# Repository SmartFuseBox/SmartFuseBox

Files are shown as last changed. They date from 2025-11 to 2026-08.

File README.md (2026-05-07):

# PowerControlHub  
PowerControlHub is an Arduino-based 12V power distribution and control system for marine and off-grid applications. It provides configurable fused relay switching, multi-protocol sensor telemetry, WiFi/BLE/MQTT connectivity, and a companion touchscreen control panel — all managed through a unified serial command protocol and EEPROM-persisted configuration.

> Current firmware version: **0.9.1.x** — see [`FirmwareVersion.h`](PowerControlHub/FirmwareVersion.h).

---

## Table of Contents

- [Overview](#overview)
- [Prototype PCBs](#prototype-pcbs)
- [Key Features](#key-features)
- [Architecture](#architecture)
- [Board Support](#board-support)
- [Installation](#installation)
- [Configuration](#configuration)
- [Usage](#usage)
- [Subsystem Reference](#subsystem-reference)
- [Limitations and Known Issues](#limitations-and-known-issues)
- [Documentation](#documentation)
- [License](#license)

## Overview

PowerControlHub is a single-unit firmware target running on an Arduino Uno R4 WiFi or ESP32 NodeMCU-32. The Nextion touchscreen display is driven directly by the PCH controller over a dedicated hardware serial port (`Serial2` for GPS; display connected via `NextionControl`).

The firmware entry point is `PowerControlHubApp`, which owns all subsystem instances and wires them together at startup. Host and debug communication uses a text-based framed serial protocol:

```
<CMD>:<key>=<value>;<key>=<value>\n
```

Commands are grouped by prefix (`F`, `C`, `R`, `H`, `W`, `S`, `M`, `N`, `E`, `T`) and are available over serial, USB, and — where applicable — the HTTP REST API. See [Docs/Commands.md](Docs/Commands.md) for the full reference.

---

## Prototype PCBs

<a href="Docs/pcbway.md">Prototype PCBs for PowerControlHub were supported by PCBWay</a>
Prototype PCBs for **PowerControlHub** were supported by [PCBWay](https://www.pcbway.com), enabling rapid iteration from design to real-world testing.

See the [PCB Sponsorship & Manufacturing](Docs/pcbway.md) page for photos, build details, and ongoing testing.

---
## Key Features

### Relay Control
- Up to **8 independently configurable relay channels**, pin-assigned at runtime via configuration.
- **Linked relays** — any relay can be configured to mirror the state of another.
- **Default-on state** — individual relays can be initialised to active at boot.
- **Pulse mode** — relay activates for a configurable duration (seconds) then turns off automatically.
- **Named relays** — short name (5 chars) and long name (20 chars) stored in EEPROM for display use.
- **Action types** — relays can be designated as `Default`, `Horn` (COLREGS sound signal output), or `NightRelay` (automatic day/night switching driven by the LDR sensor).
- **Relay status bitmask** broadcast via `MessageBus` on every state change.

### Sensor Pipeline

All sensors inherit from `BaseSensor` and are registered with `SensorController`. The `RemoteSensor` class provides an extensibility point for sensors on external devices that push readings via serial.

| Sensor | Class | Poll Interval | Notes |
|---|---|---|---|
| **DHT11** | `Dht11SensorHandler` | 2 500 ms | Temperature (°C) and relative humidity (%). Raises `TemperatureSensorFailure` warning on read error; clears automatically on recovery. |
| **Light (LDR)** | `LightSensorHandler` | 30 000 ms | Rolling average over 10 readings. 3-reading debounce before day/night state change. Configurable ADC threshold (default 512). Drives a `NightRelay` automatically. |
| **Water Level** | `WaterSensorHandler` | Configurable | 15-reading rolling average. Active-pin corrosion-reduction control (power applied only during measurement). |
| **GPS** | `GpsSensorHandler` | Continuous | GY-GPS6MV2 (NMEA). Reports latitude, longitude, altitude, speed (km/h), course, cumulative distance. Provides UTC time for automatic RTC synchronisation. Raises `GpsFailure` warning if no valid fix for 30 seconds. |
| **System Diagnostics** | `SystemSensorHandler` | Configurable | Free heap memory, CPU usage percentage, WiFi/BT enabled state, SD log file size (bytes), system uptime (`d HH:MM:SS`), active warning count. |

Sensors expose data over Serial, WiFi REST, BLE, and MQTT. Custom local or remote sensors can be added with minimal boilerplate; see [Docs/Sensors.md](Docs/Sensors.md).

### Connectivity

#### WiFi
- Operates in **Access Point** or **Client** mode, selectable via `C12`.
- Implements **persistent HTTP connections** to reduce TCP handshake overhead on resource-constrained hardware.
- Supports up to **8 concurrent clients** (`MaxConcurrentClients`).
- Automatic reconnection with exponential backoff in Client mode.
- RSSI monitoring — raises `WeakWifiSignal` warning when signal falls below −70 dBm.
- Full REST API across 9 route groups:

| Route | Handler | Purpose |
|---|---|---|
| `/api/relay` | `RelayNetworkHandler` | Relay state read/write |
| `/api/sensor` | `SensorNetworkHandler` | Sensor telemetry |
| `/api/sound` | `SoundNetworkHandler` | COLREGS horn signals |
| `/api/system` | `SystemNetworkHandler` | System status, heartbeat, OTA |
| `/api/config` | `ConfigNetworkHandler` | Configuration read/write |
| `/api/warning` | `WarningNetworkHandler` | Warning bitmask access |
| `/api/timer` | `SchedulerNetworkHandler` | Scheduled event read |
| `/api/externalsensor` | `ExternalSensorNetworkHandler` | Remote sensor config |
| `/` | `WebIndexNetworkHandler` | Index page |

Uses a platform-abstraction interface (`IWifiRadio`) to isolate board-specific WiFi drivers from application logic.

#### Bluetooth BLE
- Available on boards with `BLUETOOTH_SUPPORT` defined.
- Exposes three GATT services via `BluetoothManager`:
  - `BluetoothSystemService` — system diagnostics characteristics.
  - `BluetoothSensorService` — sensor telemetry characteristics with notifications.
  - `BluetoothRelayService` — relay state read and write characteristics.
- Single-client model. Advertising restarts automatically after disconnect.
- No pairing or bonding. Device advertises as **"Power Control Hub"**.
- Uses `IBluetoothRadio` interface — higher-level code operates exclusively through the interface pointer, with runtime null-checks replacing compile-time guards.
- **Arduino Uno R4 WiFi constraint:** WiFi and BLE share the RF path on the ANNA-B112/ESP32-S3 modules; `BLUETOOTH_SUPPORT` and `WIFI_SUPPORT` are mutually exclusive on this board. Enforced by a compile-time `#error`. On ESP32, both can operate simultaneously.

#### MQTT
- Custom **MQTT 3.1.1** client implementation (`MQTTClient`) — no third-party MQTT library dependency.
- **Home Assistant auto-discovery** — all sensors and relays register as HA entities on connect.
- Configurable broker address (64 chars), credentials (32 chars each), device ID, discovery prefix, port (default 1883), and keepalive interval (default 60 s).
- Requires `WIFI_SUPPORT`. Guarded by `#if defined(WIFI_SUPPORT)` in `BoardConfig.h`.

### Warning System

A **32-bit bitmask** tracks up to 32 independent typed conditions within `WarningManager`.

- **Sensor failure aggregation**: any sensor warning (bits 21–31) automatically raises `SensorFailure` (bit 20). `SensorFailure` clears only when all sensor warnings are cleared.
- Warning state changes are broadcast on the `MessageBus` via `WarningChanged`.
- Full warning type reference: [Docs/Warnings.md](Docs/Warnings.md).

### Scheduler

Event-driven relay automation engine with EEPROM-persisted configuration.

- Up to **20 events** (6 on boards with ≤ 1 KB EEPROM) stored in `SchedulerSettings`.
- Each event specifies an independent **trigger**, **condition guard**, and **action**.

| Dimension | Supported Values |
|---|---|
| **Triggers** | `TimeOfDay`, `Sunrise`, `Sunset`, `Interval`, `DayOfWeek`, `Date` |
| **Conditions** | `TimeWindow`, `DayOfWeek`, `IsDark`, `IsDaylight`, `RelayIsOn`, `RelayIsOff` |
| **Actions** | `RelayOn`, `RelayOff`, `RelayToggle`, `RelayPulse`, `AllRelaysOn`, `AllRelaysOff`, `SetPinHigh`, `SetPinLow` |

Sunrise and sunset triggers are computed in real time from GPS coordinates by `SunCalculator`. The `IsDark` / `IsDaylight` conditions fall back to the LDR sensor when GPS is unavailable.

### Message Bus

`MessageBus` provides a **lightweight publish/subscribe event system** for internal component decoupling. No dynamic allocation occurs at publish time — subscriber lists use function-local statics.

Key events: `WarningChanged`, `RelayStatusChanged`, `TemperatureUpdated`, `HumidityUpdated`, `LightSensorUpdated`, `WaterLevelUpdated`, `GpsLocationUpdated`, `GpsAltitudeUpdated`, `GpsSpeedUpdated`, `WifiConnectionStateChanged`, `WifiSignalStrengthChanged`, `SystemMetricsUpdated`. Full reference: [Docs/MessageBus.md](Docs/MessageBus.md).

### Over-the-Air Updates (OTA)

- Available on **ESP32 + `WIFI_SUPPORT` + `OTA_AUTO_UPDATE`** only.
- Polls the GitHub Releases API (`k3ldar/PowerControlHub`) every **24 hours**.
- Downloads asset `PowerControlHub-esp32-v{major}.{minor}.{patch}.{build}.bin` with SHA-256 checksum verification.
- TLS connections use pinned root CA certificates (Sectigo E46 for `api.github.com`; ISRG Root X1 for `assets.githubusercontent.com`).
- **Auto-apply is disabled by default.** Enable via `F12:apply=1` or the `OtaFlagAutoApply` bit in `SystemHeader::reserved[0]`.
- OTA state (`idle`, `checking`, `available`, `downloading`, `rebooting`, `failed`, `uptodate`) is queryable at any time via `F13`.

### Diagnostics and Logging

- **SD card logging** via `SdCardLogger` / `MicroSdDriver`. Configurable SPI pins (`C4`). Raises `SpiPinConfigError`, `SdCardMissing`, `SdCardError`, or `SdCardLowSpace` warnings as appropriate.
- Optional **SD card config loader** (`CARD_CONFIG_LOADER`) — reads `config.txt` at boot to override EEPROM settings without reflashing.
- **DS1302 RTC** (`RtcDS1302Driver`) with configurable pins (`C18`). Automatically synchronised from GPS UTC time on each valid GPS fix.
- **CPU usage monitoring** via `SystemCpuMonitor`. Available over serial, WiFi, and MQTT.
- **Boot counter** and **crash counter** tracked in `SystemHeader` with magic number validation (`0x53464201`).
- **RGB LED warning indicator** (HW479) driven on configurable pins (`C8`).
- **PinGuard** — compile-time GPIO validation layer that rejects flash-reserved, input-only, and strapping pins at the point of assignment, returning `ACK:<cmd>=Invalid pin` before the value reaches EEPROM. Board-specific tables are selected automatically from the IDF toolchain macros — no manual configuration required. See [Docs/PinGuard.md](Docs/PinGuard.md).
- **Crash loop guard** — `crashCounter` in `SystemHeader` is incremented at the start of every boot and only reset after full initialisation succeeds. If the counter reaches `CrashCounterThreshold` (default 3), the firmware resets the config to safe defaults before any hardware initialisation runs, breaking a watchdog reset loop caused by invalid pin configuration.

### Nextion Display

- `NavigationController` manages an ordered list of active pages, rebuilt dynamically when the location type changes — no reboot required.
- Maritime-specific pages (buoys, cardinal markers, flags, VHF radio, COLREGS sound signals) are included in the page list only when `LocationType` is `Power`, `Sail`, `Fishing`, or `Yacht`.
- Pages included: Splash, Home, Relay, Relay Settings, Environment, System, Warning, Settings, About, Buoys, Cardinal Markers, Flags, Moon Phase, Sound (Fog / Maneuvering / Overtaking / Emergency / Other / Signals), VHF (Channels / Distress / Radio).

### Security

- **API key and HMAC key** fields (32 chars each) are reserved in the `Config` struct for future HTTP authentication.

---

## Architecture

### Repository Structure

```
PowerControlHub/    Firmware source (relays, sensors, WiFi, BLE, MQTT, OTA, SD, Nextion display)
Docs/            Reference documentation
TestData/        Serial command test scripts
```

### Subsystem Dependency Graph

```
PowerControlHubApp
├── MessageBus                  Pub/sub event bus (no dynamic allocation)
├── RelayController             Relay switching, linking, pulse, action types
├── SoundController             COLREGS signal sequencer -> horn relay
├── SensorController            Sensor pipeline (local + remote)
│   ├── Dht11SensorHandler
│   ├── LightSensorHandler
│   ├── WaterSensorHandler
│   ├── GpsSensorHandler
│   ├── SystemSensorHandler
│   └── RemoteSensor (xN)
├── ConfigController            EEPROM config lifecycle
├── WarningManager              32-bit bitmask, sensor failure aggregation
├── ScheduleController          Event engine: trigger -> condition -> action
├── WifiController              WiFi lifecycle, HTTP REST API
│   └── WifiServer              Connection state machine, request routing
├── BluetoothController         BLE lifecycle (BLUETOOTH_SUPPORT)
│   └── BluetoothManager
│       ├── BluetoothSystemService
│       ├── BluetoothSensorService
│       └── BluetoothRelayService
├── MQTTController              MQTT 3.1.1 client, HA auto-discovery (MQTT_SUPPORT)
├── SdCardLogger                SD card log writer (SD_CARD_SUPPORT)
├── RtcDS1302Driver             DS1302 real-time clock
├── OtaManager                  GitHub OTA (OTA_AUTO_UPDATE + ESP32 + WIFI_SUPPORT)
├── BroadcastManager            Centralised serial broadcast to computer/debug port
├── NavigationController        Nextion page navigation (NEXTION_DISPLAY_DEVICE)
└── SerialCommandManager        Framed serial command dispatch (USB/debug)
```

### Interface Abstraction Pattern

WiFi and Bluetooth subsystems are each accessed through a platform-agnostic interface (`IWifiRadio`, `IBluetoothRadio`). Board-specific drivers (`R4WifiRadio`, `Esp32WifiRadio`, `BluetoothController`) are constructed only inside `PowerControlHubApp` under the appropriate `#if defined(...)` guard. All higher-level code operates through interface pointers with runtime null-checks, minimising preprocessor usage and enabling straightforward test doubles.

### Configuration Persistence

The `Config` struct is a versioned, packed POD serialised to EEPROM. The current layout version is **6** (`ConfigVersion6`). The `SystemHeader` (32 bytes) precedes the config payload and contains a magic number (`0x53464201`), boot count, crash counter, reset reason, OTA flags, and a 16-bit checksum. A config version mismatch triggers migration logic in `ConfigManager` and raises `DefaultConfigurationFuseBox`.

---

## Board Support

| Board | WiFi | BLE | MQTT | OTA | Notes |
|---|---|---|---|---|---|
| **Arduino Uno R4 WiFi** | Yes | Yes | Yes | No | WiFi and BLE are mutually exclusive (shared RF path) |
| **Arduino Uno R4 Minima** | No | No | No | No | Serial and sensor support only |
| **ESP32 NodeMCU-32** | Yes | Yes | Yes | Yes | Full feature support; WiFi and BLE simultaneous |

Board selection is controlled by a single `#define` in `Local.h` using the trailing-underscore convention. `BoardConfig.h` derives all capability flags, EEPROM limits, and enforces incompatible feature combinations at compile time.

---

## Installation

### Prerequisites

| Requirement | Details |
|---|---|
| **Arduino IDE** | 1.8.19 or Arduino IDE 2.x |
| **Git for Windows** | Standard installation |
| **Windows 10 / 11** | No special configuration required |

### Required Libraries (Arduino Library Manager)

| Library | Source |
|---|---|
| `SerialCommandManager` | Si Carter |
| `DHT sensor library` | Adafruit |
| `QMC5883LCompass` | Arduino Library Manager |
| `NextionControl` | Custom — copy `NextionControl/` folder to Arduino `libraries/` directory |

### Steps

1. Clone the repository:

   ```
   git clone https://github.com/k3ldar/PowerControlHub
   ```

2. Install all required libraries via the Arduino IDE Library Manager, and copy `NextionControl` manually.

3. Open `k3ldar/PowerControlHub.ino` in the Arduino IDE.

4. Edit `Local.h` to activate the correct board and feature flags (see [Configuration](#configuration)).

5. Select the target board and COM port, then upload.

Full setup walkthrough: [Docs/SETUP.md](Docs/SETUP.md).

---

## Configuration

All hardware-specific configuration is isolated in a single file: `PowerControlHub/Local.h`. No other file requires modification for a standard hardware setup.

### Board Selection

Exactly one board define must be active. Remove the trailing underscore to activate:

```cpp
#define ARDUINO_UNO_R4       // Arduino Uno R4 WiFi
#define ARDUINO_R4_MINIMA_   // Arduino Uno R4 Minima (inactive)
#define ESP32_NODE_32_       // ESP32 NodeMCU-32 (inactive)
```

### Feature Flags

| Define | Default | Approx. Flash | Description |
|---|---|---|---|
| `FUSE_BOX_CONTROLLER` | Active | — | Enables the full SFB subsystem stack |
| `WIFI_SUPPORT` | Active | — | WiFi controller and HTTP REST API |
| `MQTT_SUPPORT` | Active | ~40 KB | MQTT client and HA auto-discovery (requires `WIFI_SUPPORT`) |
| `BLUETOOTH_SUPPORT` | Inactive | ~144 KB | BLE services (mutually exclusive with WiFi on Uno R4) |
| `SD_CARD_SUPPORT` | Active | ~32 KB | SD card logger and SPI driver |
| `NEXTION_DISPLAY_DEVICE` | Active | ~52 KB | Nextion display page system |
| `OTA_AUTO_UPDATE` | Active | ~165 KB | GitHub OTA (ESP32 + WiFi only) |
| `LED_MANAGER` | Inactive | — | Arduino R4 WiFi LED matrix (experimental) |
| `CARD_CONFIG_LOADER` | Inactive | — | Load config overrides from SD `config.txt` at boot |

### Relay Count

```cpp
constexpr uint8_t ConfigRelayCount = 8;  // number of relay channels
```

Pins are assigned at runtime via the `R11` serial command and persisted to EEPROM. `0xFF` marks a pin as unassigned.

Full configuration reference: [Docs/Local.md](Docs/Local.md).

---

## Usage

### Serial / USB Commands (Quick Reference)

Commands follow the frame format: `<CMD>:<key>=<value>;<key>=<value>\n`

```
# Save config to EEPROM
C0

# Enable WiFi in client mode, set SSID and password
C11:v=1
C12:v=1
C13:YourSSID
C14:YourPassword
C0

# Switch relay 0 on / off
R3:i=0;v=1
R3:i=0;v=0

# Query all relay states
R2

# Read temperature and humidity
S0
S1

# Enable MQTT and set broker
M0:v=1
M1:192.168.1.100
C0

# Enable Home Assistant auto-discovery
M6:v=1

# Query OTA status (ESP32 only)
F13

# Check for firmware update
F12

# Apply firmware update immediately
F12:apply=1
```

Full command reference (all groups, all parameters): [Docs/Commands.md](Docs/Commands.md).

### HTTP REST API (WiFi)

```
# Relay control
POST /api/relay/R3?i=0&v=1

# Sensor data
GET /api/sensor/S0

# System status
GET /api/system/F2

# OTA status
GET /api/system/F13
```

---

## Subsystem Reference

| Document | Contents |
|---|---|
| [Docs/Commands.md](Docs/Commands.md) | Full serial and REST command reference (all groups F, C, R, H, W, S, M, N, E, T) |
| [Docs/Local.md](Docs/Local.md) | `Local.h` configuration reference: board selection, feature flags, pin layout |
| [Docs/PinGuard.md](Docs/PinGuard.md) | GPIO validation: board pin tables, blocked pin tiers, crash loop guard |
| [Docs/Sensors.md](Docs/Sensors.md) | Sensor classes, poll intervals, MQTT channels, warning behaviour, extensibility guide |
| [Docs/Warnings.md](Docs/Warnings.md) | 32-bit warning type reference, `WarningManager` API, propagation model |
| [Docs/Wifi.md](Docs/Wifi.md) | WiFi architecture: connection state machine, persistent connection model, handler pattern |
| [Docs/BluetoothBle.md](Docs/BluetoothBle.md) | BLE service/characteristic reference, connection model, adding new services |
| [Docs/ScheduleEvents.md](Docs/ScheduleEvents.md) | Scheduler data structures, trigger/condition/action types, EEPROM layout |
| [Docs/MessageBus.md](Docs/MessageBus.md) | Event reference, publish/subscribe API |
| [Docs/SETUP.md](Docs/SETUP.md) | Prerequisites, library installation, build instructions |
| [Docs/BOM.md](Docs/BOM.md) | Bill of materials: hardware, fasteners, connectors, 3D-printed parts |

---

## Limitations and Known Issues

- **Arduino Uno R4 WiFi**: WiFi and BLE cannot operate simultaneously due to the shared RF hardware path. This is enforced at compile time.
- **Arduino Uno R4 Minima**: No radio support. Serial, sensors, and Nextion display only.
- **OTA updates**: Restricted to ESP32 targets with WiFi in client mode and `OTA_AUTO_UPDATE` defined. Not available on Arduino Uno R4.
- **Scheduler capacity**: Limited to 6 events on boards with 1 KB or less of EEPROM.
- **LED matrix manager** (`LED_MANAGER`): Experimental on Arduino R4 WiFi; not recommended for production use.
- **SD card support**: Marked experimental in `Local.h`. SPI pin configuration must be correct or `SpiPinConfigError` is raised.
- **Single BLE client**: Only one BLE central can be connected at a time. No pairing or bonding is implemented.

---

## Documentation

| Getting Started | Configuration | Connectivity |
|:---|:---|:---|
| [Setup Guide](Docs/SETUP.md) | [Local.h Reference](Docs/Local.md) | [WiFi Architecture](Docs/Wifi.md) |
| [Bill of Materials](Docs/BOM.md) | [Scheduled Events](Docs/ScheduleEvents.md) | [Bluetooth BLE](Docs/BluetoothBle.md) |
| [Sensor Reference](Docs/Sensors.md) | [Warning System](Docs/Warnings.md) | [Message Bus](Docs/MessageBus.md) |
| [Command Reference](Docs/Commands.md) | [PinGuard & Crash Loop](Docs/PinGuard.md) | |

---

## License

PowerControlHub is released under the **GNU General Public License v3.0**.  
See [LICENSE](LICENSE) for the full licence text.

Copyright &copy; 2025 Simon Carter (`s1cart3r@gmail.com`)

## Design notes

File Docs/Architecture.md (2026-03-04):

# SmartFuseBox – Architecture Overview

## 1. Project Purpose

SmartFuseBox is a modular, Arduino-powered **12V power distribution and control system** designed for marine and off-grid applications. It provides fused relay switching, onboard sensor monitoring, wireless connectivity (WiFi/BLE/MQTT), and a serial command interface to an external control panel.

---

## 2. Physical Units

The system spans two physical hardware units that communicate over a serial link.

| Unit | Hardware | Role |
|---|---|---|
| **Smart Fuse Box (SFB)** | Arduino Uno R4 (or ESP32) | Relay control, sensor handling, WiFi, BLE, MQTT, SD logging |
| **Boat Control Panel (BCP)** | Arduino Mega + Nextion display | User interface, immobiliser logic, time sync, config management |

The two units communicate via a 7-wire harness (12V in/out, GND, 5V, TX, RX, spare). The control panel must return a valid 12V feed to enable the fuse box, acting as a basic immobiliser.

---

## 3. High-Level Component Map

```
┌───────────────────────────────────────────────────────────────────┐
│                        SmartFuseBoxApp                            │
│                                                                   │
│  ┌───────────────┐  ┌────────────────┐  ┌──────────────────────┐  │
│  │ Serial Link   │  │  Message Bus   │  │   Warning Manager    │  │
│  │ (BroadcastMgr)│  │  (pub/sub)     │  │   (32-bit bitmap)    │  │
│  └───────────────┘  └────────────────┘  └──────────────────────┘  │
│                                                                   │
│  ┌────────────────────────────────────────────────────────────┐   │
│  │                    Command Handlers (Serial)               │   │
│  │  SystemCmdHandler  RelayCmdHandler  SoundCmdHandler        │   │
│  │  SensorCmdHandler  ConfigCmdHandler  AckCmdHandler         │   │
│  └────────────────────────────────────────────────────────────┘   │
│                                                                   │
│  ┌──────────────┐  ┌──────────────┐  ┌────────────────────────┐   │
│  │   Relay      │  │   Sensor     │  │   Config System        │   │
│  │   Controller │  │   Manager    │  │   (EEPROM + SD)        │   │
│  └──────────────┘  └──────────────┘  └────────────────────────┘   │
│                                                                   │
│  ┌──────────────┐  ┌──────────────┐  ┌────────────────────────┐   │
│  │   WiFi       │  │  Bluetooth   │  │   MQTT                 │   │
│  │   Controller │  │  Controller  │  │   Controller           │   │
│  │   + HTTP API │  │  (BLE)       │  │   (Home Assistant)     │   │
│  └──────────────┘  └──────────────┘  └────────────────────────┘   │
│                                                                   │
│  ┌──────────────┐  ┌──────────────┐  ┌────────────────────────┐   │
│  │  SD Card     │  │  LED Matrix  │  │  Date/Time Manager     │   │
│  │  Logger      │  │  Manager     │  │  (RTC + millis())      │   │
│  └──────────────┘  └──────────────┘  └────────────────────────┘   │
└───────────────────────────────────────────────────────────────────┘
```

---

## 4. Entry Point and Application Lifecycle

### `SmartFuseBox.ino`
The sketch file wires everything together. It owns the two `SerialCommandManager` instances (selecting which hardware serial ports and baud rates to use) and constructs `SmartFuseBoxApp`. Project-specific sensors are constructed using accessors from the app object.

```
setup()  →  initializeSerial  →  app.setup(sensors, remoteSensors)
loop()   →  app.loop()
```

### `SmartFuseBoxApp`
Central application class that owns all subsystems. On `setup()` it:
1. Initialises the `SensorManager` with all local and remote sensor handlers.
2. Configures WiFi and Bluetooth from the stored `Config`.
3. Registers all command handlers with each `SerialCommandManager`.
4. Registers all network handlers with the `WifiController`.
5. Registers all MQTT handlers (if `MQTT_SUPPORT` is defined).
6. Starts an LED startup animation (if `LED_MANAGER` is defined).

On `loop()` it delegates to each subsystem in turn.

---

## 5. Serial Communication Layer

All serial communication uses the `SerialCommandManager` library. Commands are newline-terminated with the following format:

```
{COMMAND}:{key=value};{key=value}\n
```

Two serial connections are maintained:

| Port | Baud | Purpose |
|---|---|---|
| `Serial` (COMPUTER_SERIAL) | 115200 | USB debug / computer connection |
| `Serial1` (LINK_SERIAL) | 19200 | Link to Boat Control Panel |

### `BroadcastManager`
Wraps both serial managers and provides a single `sendCommand()` / `sendDebug()` / `sendError()` interface that can target both ports simultaneously or link-only.

### Command Handlers
Each handler inherits `SharedBaseCommandHandler` and declares the command tokens it owns.

| Handler | Command Prefix | Responsibility |
|---|---|---|
| `SystemCommandHandler` | `F0`–`F11` | Heartbeat, memory/CPU diagnostics, date/time, SD status, uptime |
| `RelayCommandHandler` | `R0`–`R4` | Turn relays on/off, retrieve relay states |
| `SoundCommandHandler` | `H0`–`H12` | COLREGS sound signal playback |
| `SensorCommandHandler` | `S*` | Sensor data reporting and querying |
| `ConfigCommandHandler` | `C0`–`C31` | Full configuration management |
| `AckCommandHandler` | `ACK` | Processes acknowledgement responses |
| `WarningCommandHandler` | `W*` | Warning state propagation |
| `InterceptDebugHandler` | – | Debug message interception |

---

## 6. Relay Subsystem

### `RelayController`
Manages up to 8 relay outputs. Relay pins are LOW-active (ON = LOW, OFF = HIGH).

Key behaviours:
- **Linked relays**: configured pairs that mirror each other's state.
- **Reserved relay**: one relay index can be reserved for the sound (horn) system and is excluded from bulk on/off commands.
- **State change notifications**: publishes a `RelayStatusChanged` bitmask event on the `MessageBus` when any relay changes state.

---

## 7. Sensor Subsystem

### Base Classes

| Class | Role |
|---|---|
| `BaseSensor` | Extends `BaseSensorHandler` (external `SensorManager` library); optionally extends `JsonVisitor` for status serialisation |
| `RemoteSensor` | Receives updates from the serial link or MQTT; stores up to 5 key/value parameters |

All sensors declare a `SensorIdList` ID, a command ID string, and (when `MQTT_SUPPORT` is defined) expose named MQTT channels with device class, unit, and binary/numeric type metadata.

### Included Sensor Handlers

| Sensor | Type | Measurements |
|---|---|---|
| `WaterSensorHandler` | Local (analog) | Raw water level + rolling average queue |
| `Dht11SensorHandler` | Local (digital) | Temperature (°C) + Humidity (%) |
| `LightSensorHandler` | Local (digital + analog) | Day/night state |
| `SystemSensorHandler` | Local (virtual) | Free RAM, CPU usage, BT/WiFi state, SD log file size, active warning count |
| `RemoteSensor` (GPS) | Remote | Latitude, Longitude (extensible to Altitude, Speed, Course) |

### `SensorManager` (external library)
Calls `update()` on each registered sensor at its own requested interval (returned in milliseconds from `update()`). This keeps all sensor polling non-blocking.

### `SensorController`
Provides indexed access to all `BaseSensor` instances for the MQTT and network layers.

---

## 8. Connectivity

### 8.1 WiFi (`WifiController` + `WifiServer`)

Available on boards that define `WIFI_SUPPORT` (e.g. Arduino Uno R4, ESP32).

- Operates in **AP mode** (device creates its own network) or **Client mode** (joins existing network).
- `WifiServer` runs an HTTP server supporting up to 2 concurrent clients.
- REST API routes are registered via `INetworkCommandHandler` implementations:

| Network Handler | Route | Exposes |
|---|---|---|
| `SystemNetworkHandler` | `/api/system/{cmd}` | System commands (F0-only via WiFi) |
| `RelayNetworkHandler` | `/api/relay/{cmd}` | Relay state and control |
| `SoundNetworkHandler` | `/api/sound/{cmd}` | Sound signal commands |
| `ConfigNetworkHandler` | `/api/config/{cmd}` | Configuration read/write |
| `SensorNetworkHandler` | `/api/sensor/{cmd}` | Sensor data |
| `WarningNetworkHandler` | `/api/warning/{cmd}` | Warning state |

### 8.2 Bluetooth BLE (`BluetoothController` + `BluetoothManager`)

Available on boards that define `ARDUINO_UNO_R4`. Uses the `ArduinoBLE` library.

`BluetoothManager` coordinates the BLE stack and delegates domain logic to services:

| BLE Service | Exposes |
|---|---|
| `BluetoothSystemService` | Heartbeat, system initialised, free memory, CPU usage (notify characteristics) |
| `BluetoothRelayService` | Relay state array (read/notify) + relay set command (write) |
| `BluetoothSensorService` | Sensor data streaming |

### 8.3 MQTT (`MQTTController` + `MQTTClient`)

Available when both `WIFI_SUPPORT` and `MQTT_SUPPORT` are defined.

- `MQTTClient` is a pure C++ MQTT 3.1.1 implementation over `WiFiClient` (no external MQTT library dependency).
- `MQTTController` manages connection lifecycle: retry with exponential back-off, reconnect count, uptime tracking.
- Supports Home Assistant auto-discovery (`useHomeAssistantDiscovery` config flag).

| MQTT Handler | Responsibility |
|---|---|
| `MQTTSensorHandler` | Publishes all sensor channel states; handles HA discovery payloads |
| `MQTTRelayHandler` | Publishes relay states; subscribes to relay command topics |
| `MQTTSystemHandler` | Publishes system metrics |
| `MQTTConfigCommandHandler` | Handles configuration updates via MQTT |

---

## 9. Configuration System

| Component | Role |
|---|---|
| `Config` struct | Packed POD stored in EEPROM; versioned with checksum validation |
| `ConfigManager` | Static EEPROM read/write; `resetToDefaults()`; checksum calculation |
| `ConfigController` | Domain façade exposing typed setters (e.g. `setWifiSsid`, `setLedColor`) |
| `ConfigSyncManager` | Periodically requests a C1 (Get Settings) from the Control Panel every 5 minutes; retries every 10 seconds on failure |
| `SDCardConfigLoader` | Optional: loads `config.txt` from SD card on boot or card insertion |

Notable configuration fields include vessel name, relay names (short 5-char + long 20-char), home page button mapping, vessel type (Motor/Sail/Fishing/Yacht), MMSI, call sign, home port, timezone offset, LED colours/brightness, WiFi credentials, MQTT credentials, relay default states, and linked relay pairs.

---

## 10. Event System – `MessageBus`

`MessageBus` is a compile-time typed publish/subscribe bus. Components subscribe to strongly-typed event structs; publishers call `messageBus->publish<EventType>(args)`.

Key events:

| Event | Payload | Published by |
|---|---|---|
| `TemperatureUpdated` | `float newTemp` | `Dht11SensorHandler` |
| `HumidityUpdated` | `uint8_t newHumidity` | `Dht11SensorHandler` |
| `LightSensorUpdated` | `bool isDayTime` | `LightSensorHandler` |
| `WaterLevelUpdated` | `uint16_t level, uint16_t avg` | `WaterSensorHandler` |
| `RelayStatusChanged` | `uint8_t changedMask` | `RelayController` |
| `WifiConnectionStateChanged` | `WifiConnectionState` | `WifiServer` |
| `WifiSignalStrengthChanged` | `uint16_t strength` | `WifiServer` |
| `GpsLocationUpdated` | `double lat, double lon` | `RemoteSensor` |
| `SystemMetricsUpdated` | – | `SystemSensorHandler` |
| `MqttConnected` / `MqttDisconnected` | – | `MQTTController` |
| `MqttMessageReceived` | `topic, payload` | `MQTTController` |
| `WarningChanged` | `uint32_t mask` | `WarningManager` |

---

## 11. Warning System – `WarningManager`

Tracks up to 32 simultaneous warnings using a `uint32_t` bitmask, split into local (raised on this device) and remote (received from the Control Panel).

| Bit Range | Category |
|---|---|
| 0–19 | System warnings (connection lost, WiFi/BT init failed, SD card issues, low battery, etc.) |
| 20–31 | Sensor warnings (temperature sensor failure, GPS failure, compass failure, etc.) |

Built-in heartbeat monitoring automatically raises/clears the `ConnectionLost` warning based on `F0` ACK timing (timeout: 3 seconds).

---

## 12. Sound System – `SoundController`

Non-blocking COLREGS-compliant sound signal playback via a relay-controlled horn. Uses a state machine (`Idle → StartDelay → BlastOn → BlastGap → WaitingRepeat`).

Supported signal types:

| Signal | COLREGS Reference |
|---|---|
| SOS | Distress (Morse) |
| Fog | Rule 35 (repeats every 2 minutes) |
| MoveStarboard / MovePort / MoveAstern / MoveDanger | Rule 34 manoeuvring signals |
| OvertakeStarboard / OvertakePort / OvertakeConsent / OvertakeDanger | Rule 34 overtaking signals |
| Test | Non-COLREGS test blast |

---

## 13. SD Card and Logging

| Component | Role |
|---|---|
| `MicroSdDriver` | Singleton resource manager for the SD card (SdFat library); handles card presence detection, settling delays, and up to 3 simultaneous file handles |
| `SdCardLogger` | Non-blocking sensor data logger; buffers up to 64 records in a circular buffer; writes a maximum of 5 records per loop iteration; creates date-named CSV files (`YYYYMMDD.csv`) with automatic midnight rotation |

`SdCardLogger` subscribes to `MessageBus` sensor events and captures a `SensorSnapshot` (temperature, humidity, water level, GPS, warnings, etc.) on each update.

---

## 14. LED Matrix – `LedMatrixManager`

Used on Arduino Uno R4 boards with `LED_MANAGER` defined. Drives the 8×12 built-in LED matrix.

Matrix layout (conceptual):

```
Row 0     : Top border / relay states
Col 0     : Left border / system indicator
Cols 3–4  : Temperature display (rows 2–7)
Cols 10–11: Warning / GPS indicators (rows 4–7)
```

Reacts to `MessageBus` events to update:
- Relay on/off states (top row)
- WiFi connection state and RSSI signal bars
- Temperature and humidity readings
- Warning indicators (GPS, system, warnings)

Supports startup and shutdown animation sequences.

---

## 15. Date/Time – `DateTimeManager`

Static class providing system-wide time management.

- Tracks Unix timestamp (seconds) plus a millisecond offset derived from `millis()`.
- On boot, attempts to read time from a DS1302 hardware RTC (Control Panel builds only).
- Time is continuously synchronised via the `t=` parameter in the `F0` heartbeat command from the Control Panel — no separate `F6` command is needed during normal operation.
- Exposes `setDateTimeISO()` and `setDateTime(unixTimestamp)`.

---

## 16. Feature Flags (`Local.h`)

All major features are controlled by compile-time defines in `Local.h` (consumer-editable):

| Define | Effect |
|---|---|
| `ARDUINO_UNO_R4` | Enables WiFi and Bluetooth support |
| `FUSE_BOX_CONTROLLER` | Includes relay/sensor controller code; omit to use components standalone |
| `WIFI_SUPPORT` | Includes `WifiController`, `WifiServer`, and network command handlers |
| `MQTT_SUPPORT` | Includes `MQTTController`, `MQTTClient`, and all MQTT handlers (requires `WIFI_SUPPORT`) |
| `LED_MANAGER` | Includes `LedMatrixManager` (requires `ARDUINO_UNO_R4`) |
| `CARD_CONFIG_LOADER` | Includes `SDCardConfigLoader` for SD-based config loading |

---

## 17. Key Design Patterns

| Pattern | Where Used |
|---|---|
| **Facade / Owned-component** | `SmartFuseBoxApp` owns all subsystems and exposes accessor methods to the sketch |
| **Publish / Subscribe** | `MessageBus` decouples producers (sensors, relay, WiFi) from consumers (LED matrix, MQTT, logger) |
| **Command Handler** | Serial, HTTP, and MQTT commands each routed through dedicated handler classes |
| **Strategy / Visitor** | `JsonVisitor` / `NetworkJsonVisitor` decouple JSON serialisation from domain objects |
| **Sensor Polling Abstraction** | External `SensorManager` library calls `update()` on each sensor at its own interval, avoiding `delay()` |
| **Mixin Logging** | `LoggingSupport`, `SingleLoggerSupport`, `BroadcastLoggerSupport` add logging to any class via multiple inheritance |
| **Compile-time Feature Selection** | `#define` flags in `Local.h` prevent unused subsystems from consuming flash/RAM on resource-constrained boards |

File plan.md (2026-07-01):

Move SensorMetaCache refresh to happen immediately when the DashboardPoller starts executing (after connection), rather than deferred until the first successful poll response.

Changes to `PowerControlHubApp\Services\DashboardPoller.cs`:
1. Remove the `_wasPreviouslyConnected` flag and the fire-and-forget `_metaCache.RefreshAsync` call inside the poll loop.
2. In `ExecuteAsync`, before entering the `while` loop, call `_metaCache.RefreshAsync(_service, stoppingToken)` synchronously (await) once. This ensures metadata is available before any sensor detail pages can be navigated to.
3. This makes the meta cache refresh happen once per connection, shortly after the poller starts, aligned with the device being reachable.

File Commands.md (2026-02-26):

# Communication Commands
The following sections indicate the types of commands that can be sent to the Boat Control Panel, with examples and purpose.

## System Commands
These are commands used to configure the system settings and can only be sent from a computer, they are not used for internal communication.

| Command | Example | Purpose |
|---|---|---|
| `F0` — Heart beat | `F0:w=0x00` (SFB) or `F0:w=0x00;t=1733328600` (BCP) | Send at rated intervals to monitor connection health. If no ACK received, indicates connection loss. **Params:** `w=<hex_warnings>` - bitmask of active local warnings (hex format). `t=<timestamp>` - (BCP only) Unix timestamp for continuous time sync. Smart Fuse Box automatically updates clock from `t=` parameter. |
| `F1` — System Initialized | `F1` | Sent by the system when initialization is complete to signal readiness. No params. Used to notify connected devices or software that the control panel is ready for operation. |
| `F2` — Free Memory | `F2` | When received will return the amount of free memory. |
| `F3` — Cpu Usage | `F3` | When received will return the current CPU usage. No params. |
| `F4` — Bluetooth Enabled | `F4` | When received will return the current enabled state of bluetooth 0 off 1 on. No params. |
| `F5` — Wifi Enabled | `F5` | When received will return the current enabled state of wifi 0 off 1 on. No params. |
| `F6` — Set DateTime | `F6:v=1733328600` | Set current date/time. Accepts Unix timestamp (seconds since epoch). Returns current stored time. |
| `F7` — Get DateTime | `F7` | Get current date/time as ISO 8601 datetime string `YYYY-MM-DDTHH:MM:SS`. |
| `F8` — SD Card Present | `F8` | Query if SD card is present. Returns `v=0` (not present) or `v=1` (present). No params. |
| `F9` — SD Card Log File Size | `F9` | Get current log file size in bytes. Returns `v=<bytes>` where bytes is the size of the active log file. Returns `v=0` if no file is open. No params. |
| `F10` — RTC Diagnostic | `F10` | Perform DS1302 RTC diagnostics. Returns status message with RTC health (availability, running state, write protection, time validity). Returns error message if RTC fails any check. No params. |
| `F11` — Uptime | F11 | Returns system uptime as "days HH:MM:SS" (e.g. 2d 03:12:45). No params. |

**Heartbeat Behavior:**
- Sent every 1 second (1000ms) from both devices
- Boat Control Panel (BCP) includes time sync: `F0:w=0x00;t=1733328600`
- Smart Fuse Box (SFB) includes only warnings: `F0:w=0x00`
- Connection timeout occurs after 3 seconds without response
- Time synchronization is automatic - no separate F6 commands needed during normal operation
- F6 command can still be used for manual time updates or initial configuration
- 
### Wifi System Commands (SFB)
Only F0 is supported via wifi.
Route: /api/system/{command}
Example: Return free memory = /api/system/F2 

------

## Configuration Commands
These are commands used to configure the system settings and can only be sent from a computer, they are not used for internal communication.

| Command | Example | Purpose |
|---|---|---|
| `C0` — Save settings | `C0` | Persist current in-memory config to EEPROM. Responds `SAVED` on success; error `EEPROM commit failed` on failure. No params. |
| `C1` — Get settings | `C1` | Request full config. Device replies with multiple commands: `C3 <boatName>`, `C4 <idx>:<shortName|longName>` for each relay, `C5 <slot>:<relay>` for each home-slot mapping, `C6 <idx>=<color>` for each button color, `C7 v=<type>` for vessel type, `C8 v=<relay>` for sound relay, `C9 v=<delay>` for sound delay, `C10`-`C17` for WiFi/Bluetooth settings (Arduino Uno R4 only), `C18 <relay>=<state>` for default relay states, `C19 <relay>=<linkedrelay>` for linked relays, `C20 v=<offset>` for timezone, `C21 <mmsi>` for MMSI, `C22 <callsign>` for call sign, `C23 <homeport>` for home port, then `OK`. No params. |
| `C2` — Reset settings | `C2` | Request full reset of all config settings. No params. |
| `C3` — Rename boat (BCP) | `C3:Sea Wolf` or `C3:name=SeaWolf` | Set the boat name. `<key>:<value>` pair (value is used as boat name. Empty name → error. Name is truncated to configured max length. |
| `C4` — Rename relay (BCP) | `C4:2=Bilge` or `C4:2=Bilge\|Bilge Pump` | Rename a relay. Param format: `<idx>=<shortName>` or `<idx>=<shortName|longName>`. `idx` must be 0..7 (`RELAY_COUNT`). If no pipe character or long name provided, the short name is used for both. Short name is truncated to 5 chars (used on home page), long name is truncated to 20 chars (used on buttons page). Missing name → error. |
| `C5` — Map home button (BCP) | `C5:1=3` (map) — `C5:1=255` (unmap) | Map a home-page slot to a relay. Param format: `<slot>:<relay>`. `button` must be 0..3 (`HOME_BUTTONS`). `relay` must be 0..7 or `255` to clear/unmap. |
| `C6` — Map home button color (BCP) | `C6:0=4` (map button 1 to Red when activated) — `C6:1=255` (unmap colors) | Map a home-page button to a color when activated (on). Param format: `<slot>:<relay>`. `slot` must be 0..3 (`ConfigManager::HOME_SLOTS`). `relay` must be 0..7 or `255` to clear/unmap. |
| `C7` — Set vessel type | `C7:v=1` | Set the vessel type. Param format: `v=<type>`. Possible values for `<type>` are: 0 (Motor), 1 (Sail), 2 (Fishing), 3 (Yacht). Uses enum values as defined in `Config.h`. Invalid or missing value → error. |
| `C8` — Sound relay button | `C8:v=3` (map) — `C8:v=255` (unmap) | Map the sound system (horn) to a relay. Param format: `v=<relay>`. `relay` must be 0..7 or `255` to clear/unmap. Auto-renames relay to "Sound" / "Sound\r\nSignals" if not already named. |
| `C9` — Sound delay Start | `C9:v=0xFF` | Sets the delay before the sound is started in milliseconds, allows other processing to continue so as sounds are not cut off. Invalid or missing value → error. |
| `C10` — Bluetooth Enabled (SFB) | `C10:v=1` | Sets the enabled state of bluetooth, 0 disabled, 1 enabled, if disabling then a restart is required. Invalid or missing value → error. |
| `C11` — Wifi Enabled (SFB) | `C11:v=1` | Sets the enabled state of wifi, 0 disabled, 1 enabled, if disabling then a restart is required. Invalid or missing value → error. |
| `C12` — Wifi Access Mode (SFB) | `C12:v=1` | Sets access mode, 0 is AP and 1 is client |
| `C13` — Wifi SSID (SFB) | `C13:RouterName` | Set's the wifi SSID, only available if access mode is client. Param format: SSID value directly (no v= prefix). |
| `C14` — Wifi Password (SFB) | `C14:Password123` | Set's the wifi password, only available if access mode is client. Param format: password value directly (no v= prefix). |
| `C15` — Wifi Port (SFB) | `C15:v=80` | Set's the wifi port, this is the port used to listen on, default value is 80. Invalid or zero port → error. |
| `C16` — Wifi connection state (SFB) | `C16` | Wifi connection state, no params, returns WifiConnectionState value. Note: Not implemented in ConfigCommandHandler - use SystemCommandHandler. |
| `C17` — Wifi AP Ip address (SFB) | `C17:192.168.4.1` | Sets the IP address when using access point mode, default is 192.168.4.1. Param format: IP address directly (no v= prefix). |
| `C18` — Initial relay on | `C18:3=1` — `C18:3=0`  | Set's the initial status of a relay to on by default. Param format: `<relay>=<value>`. `relay` must be 0..7 (`RELAY_COUNT`), `value` must be 0 (off by default) or 1 (on by default). |
| `C19` — Link Relays | `C19:3=4` — `C19:3=255` (unlink) | Links relays together, if one relay is switched on, the linked relay is switched on, and vice versa for switching off. Param format: `<relay>=<linkedrelay>`. `relay` must be 0..7 (`RELAY_COUNT`) `linkedrelay` must be 0..7 or `0xFF` (255) to unlink. |
| `C20` — Timezone Offset | `C20:v=-5` or `C20:v=8` | Set timezone offset from UTC in hours. Param format: `v=<offset>`. Valid range: -12 to +14. Invalid offset → error. |
| `C21` — MMSI | `C21:123456789` | Set Maritime Mobile Service Identity (MMSI) number. Param format: MMSI value directly (no v= prefix). Must be exactly 9 digits. Invalid length → error. |
| `C22` — Call Sign | `C22:ABCD123` | Set vessel call sign. Param format: call sign value directly (no v= prefix). Truncated to configured max length (ConfigCallSignLength). |
| `C23` — Home Port | `C23:Miami` | Set vessel home port. Param format: port name directly (no v= prefix). Truncated to configured max length (ConfigHomePortLength). |
| `C24` — LED Color | `C24:t=0;c=0;r=255;g=50;b=213` | Set LED RGB color. Param format: `t=<type>;c=<colorset>;r=<red>;g=<green>;b=<blue>`. `type` must be 0 (day) or 1 (night). `colorset` must be 0 (good) or 1 (bad). RGB values 0-255. |
| `C25` — LED Brightness | `C25:t=0;b=75` | Set LED brightness. Param format: `t=<type>;b=<brightness>`. `type` must be 0 (day) or 1 (night). `brightness` must be 0-100. |
| `C26` — LED Auto Switch | `C26:v=true` or `C26:v=1` | Enable/disable auto day/night switching. Param format: `v=<value>`. `value` must be true/false or 1/0. |
| `C27` — LED Enable States | `C27:g=true;w=true;s=false` | Enable/disable individual LEDs. Param format: `g=<gps>;w=<warning>;s=<system>`. Each value must be true/false or 1/0. `g`=GPS LED, `w`=Warning LED, `s`=System LED. |
| `C28` — Control Panel Tones | `C28:t=0;h=400;d=500;p=0;r=30000` | Configure control panel tones, 2 categories, good and bad, good is only used at startup to indicate all is working, bad is used in response to warnings. t=0 or 1 (0 good or 1 bad), h = tone Hz, d = duration in milliseconds, p = preset 0 custom tone/duration, 1 = submaring ping, 2 = double beep, 3 = rising chirp, 4 = descending alert, 5 = nautical bell, 0xFF = no sound.  r = repeat interval in milliseconds where 0 is do not repeat, this is only used for bad sounds. |
| `C29` — Reload Config from SD (SFB) | `C29` | **Local only (Serial/USB)**. Reload configuration from SD card config.txt file... |
| `C30` — Export Config to SD (SFB) | `C30` | **Local only (Serial/USB)**. Export current in-memory configuration to SD card... |
| `C31` — SD Card Initialize Speed (SFB) | `C31:v=4` | Set SD card SPI initialization speed in MHz. Param format: `v=<speed>`. Valid values: 4, 8, 12, 16, 20, 24. Default is 4 MHz. **Note:** Higher speeds (16+ MHz) should only be used with high-quality SD cards that explicitly support high-speed SPI mode. Using speeds that are too high for your SD card may result in initialization failures or data corruption. If experiencing SD card issues, try reducing the speed to 4 or 8 MHz. |

### MQTT Configuration Commands (SFB)
These commands configure MQTT connectivity for Home Assistant and other MQTT-based integrations.

| Command | Example | Purpose |
|---|---|---|
| `M0` — MQTT Enabled | `M0:v=1` | Enable/disable MQTT. Param format: `v=<value>`. `value` must be 0 (disabled) or 1 (enabled). Query without params returns current state. |
| `M1` — MQTT Broker | `M1:192.168.1.100` | Set MQTT broker address. Param format: broker address directly (no v= prefix). Supports IP addresses or hostnames. Query without params returns current broker. |
| `M2` — MQTT Port | `M2:v=1883` | Set MQTT broker port. Param format: `v=<port>`. Default is 1883. Query without params returns current port. |
| `M3` — MQTT Username | `M3:myuser` | Set MQTT username for authentication. Param format: username directly (no v= prefix). Optional - leave empty for no authentication. Query returns "Username" or empty string if no username has been set. |
| `M4` — MQTT Password | `M4:mypassword` | Set MQTT password for authentication. Param format: password directly (no v= prefix). Optional - leave empty for no authentication. Query returns "Password" or empty string if no password has been setM4. |
| `M5` — MQTT Device ID | `M5:boat_seawolf_01` | Set unique MQTT device identifier. Param format: device ID directly (no v= prefix). Used in topic paths: `smartfusebox/<deviceId>/...`. Query without params returns current device ID. |
| `M6` — HA Discovery | `M6:v=1` | Enable/disable Home Assistant auto-discovery. Param format: `v=<value>`. `value` must be 0 (disabled) or 1 (enabled). When enabled, publishes discovery messages for automatic entity configuration. Query without params returns current state. |
| `M7` — Keep Alive Interval | `M7:v=60` | Set MQTT keep-alive interval in seconds. Param format: `v=<seconds>`. Default is 60 seconds. Controls PING frequency. Query without params returns current interval. |
| `M8` — MQTT Connection State | `M8` | Query MQTT connection state. Returns `v=0` (disconnected/disabled) or `v=1` (connected). Read-only command, no parameters accepted. |
| `M9` — Discovery Prefix | `M9:homeassistant` | Set Home Assistant discovery prefix. Also used as the base topic prefix for all MQTT messages. Param format: prefix directly (no v= prefix). Default is "homeassistant". This prefix is used in discovery topic paths: `<prefix>/switch/<deviceId>/relay<index>/config` and state/command topics: `<prefix>/<deviceId>/relay/<index>/state`. Query without params returns current prefix. |

**MQTT Topic Structure:**
- Relay control: `<discoveryPrefix>/<deviceId>/relay/<index>/set` (command), `<discoveryPrefix>/<deviceId>/relay/<index>/state` (state)
- Sensor data: `<discoveryPrefix>/<deviceId>/sensor/<type>/state`
- System info: `<discoveryPrefix>/<deviceId>/system/<metric>/state`
- Warnings: `<discoveryPrefix>/<deviceId>/warning/active/state`
- Discovery: `<discoveryPrefix>/switch/<deviceId>/relay<index>/config`

**Example with default prefix (homeassistant):**
- State topic: `homeassistant/smartfusebox_01/relay/0/state`
- Command topic: `homeassistant/smartfusebox_01/relay/0/set`
- Discovery topic: `homeassistant/switch/smartfusebox_01/relay0/config`

**Example with custom prefix (myboat):**
- State topic: `myboat/boat_seawolf/relay/0/state`
- Command topic: `myboat/boat_seawolf/relay/0/set`
- Discovery topic: `myboat/switch/boat_seawolf/relay0/config`

**Setup Example:**
```
M0:v=1                          # Enable MQTT
M1:192.168.1.100                # Set broker IP
M5:boat_seawolf_01              # Set device ID
C0                              # Save to EEPROM
```

Common MQTT error responses: `Config not available`, `Invalid port`, `Invalid keep-alive interval`, `Invalid value (true/false or 0/1)`.

Common error responses you may see: `Missing param`, `Missing params`, `Missing name`, `Empty name`, `Index out of range`, `Button out of range`, `Slot out of range`, `Relay out of range (or 255 to clear)`, `Invalid value (0 or 1)`, `Invalid mode (0=AP, 1=Client)`, `Only available in Client mode`, `Invalid port`, `Invalid offset (-12 to +14)`, `MMSI must be 9 digits`, `Invalid boat type`, `No available link slots`, `EEPROM commit failed`, `Unknown config command`, `Invalid type (0=day, 1=night)`, `Brightness must be 0-100`, `Invalid value (true/false or 0/1)`, `Missing params (t,r,g,b)`, `Missing params (t,b)`, `Missing params (g,w,s)`, `Invalid speed (4, 8, 12, 16, 20, or 24 MHz)`, `Config not available`, `Invalid port`, `Invalid keep-alive interval`.

### Wifi Configuration Commands (SFB)
Route: /api/config/{command}
Example: Specify sound relay button = /api/config/C8?v=3 

------

## Acknowledgement Commands
These commands are used in response to receiving a command.

| Command | Example | Purpose |
|---|---|---|
| `ACK` — Acknowledgement | `ACK:C4=Index out of range` | Indicates that the C4 command was processed and the index specified was out of range. |
| `ACK` — Acknowledgement | `ACK:C4=ok` | Indicates that the C4 command was processed successfully. |

### Wifi Acknowledgement Commands 
Not supported

------

## Relay Control Commands (SFB)
These commands are used to control the relays on the Boat Control Panel. Commands can be sent from a computer or generated internally by the Boat Control Panel.

| Command | Example | Purpose |
|---|---|---|
| `R0` — Turn All Off | `R0` | Indicates that the C4 command was processed and the index specified was out of range. |
| `R1` — Turn All On | `R1` | Indicates that the C4 command was processed successfully. |
| `R2` — Retrieve States | `R2` | Retrieve the state of all relays. |
| `R3` — Relay State Set | `R3:3=1` (turn on relay 3) — `R3:5=0` (turn off relay 5) | Set the state of a specific relay. Param format: `<idx>=<state>`. `idx` must be 0..7 (`RELAY_COUNT`). `state` must be `0` (off) or `1` (on). |
| `R4` — Relay State Get | `R4:3` (retrieves status of relay 3) — `R4:5` (returns status of relay 5). Param format: `<idx>`. `idx` must be 0..7 (`RELAY_COUNT`). |

### Wifi Relay Commands (SFB)
Route: /api/relay/{command}
Example: Set relay state to on = /api/relay/R3?3=1
Returns JSON formatted response with all relay states.

------

## Sensor Commands
These commands are used to send sensor data from the Boat Control Panel to a computer.

| Command | Example | Purpose |
|---|---|---|
| `S0` — Temperature | `S0:v=72.5` | Send temperature sensor data. Param format: `<sensor>=<value>`. |
| `S1` — Humidity | `S1:v=55.2` | Send humidity sensor data. Param format: `<sensor>=<value>`. |
| `S2` — Bearing | `S2:v=128` | Send bearing sensor data. Param format: `<sensor>=<value>`. |
| `S3` — Direction | `S3:v=NNW` | Send direction sensor data. Param format: `<sensor>=<value>`. |
| `S4` — Speed | `S4:v=3.4` | Send speed sensor data. Param format: `<sensor>=<value>`. |
| `S5` — Compass Temp | `S5:v=23.4` | Send compass temperature sensor data. Param format: `<sensor>=<value>`. |
| `S6` — Water Level | `S6:v=3.4` | Send water level sensor data. Param format: `<sensor>=<value>`. |
| `S7` — Water Pump Active  | `S7:v=1` | Send water pump active status. Param format: `<sensor>=<value>`, 0 = off, 1 = on. |
| `S8` — Horn Active | `S8:v=1` | Send horn active status. Param format: `<sensor>=<value>`, 0 = off, 1 = on. |
| `S9` — Light Sensor Active  | `S9:v=1` | Send light sensor daytime value. Param format: `<sensor>=<value>`, 0 = off (night time), 1 = on (day time). |
| `S10` — GPS Lat/Long | `S10:lat=51.507351;lon=-0.127758` | Send GPS latitude and longitude coordinates. Param format: `lat=<latitude>;lon=<longitude>`. Values are in decimal degrees with 6 decimal places precision. |
| `S11` — GPS Altitude | `S11:v=125.50` | Send GPS altitude in meters. Param format: `<sensor>=<value>`. Value is in meters with 2 decimal places precision. |
| `S12` — GPS Speed | `S12:v=15.75;course=245.30;dir=NNW` | Send GPS speed in km/h with optional course/heading in degrees and optional direction. Param format: `v=<speed>;course=<degrees>;dir=<direction>`. Speed is in kilometers per hour with 2 decimal places precision. Course is in degrees (0-360) with 2 decimal places precision, where 0° is North, 90° is East, 180° is South, and 270° is West. Direction is optional cardinal direction string (N, NE, E, SE, S, SW, W, NW, etc.). |
| `S13` — GPS Satellites | `S13:v=8` | Send GPS satellite count. Param format: `<sensor>=<value>`. Value is the number of satellites currently connected to the GPS module. |
| `S14` — GPS Distance | `S14:v=1.23` | Send GPS distance moved. Param format: `<sensor>=<value>`. Value is the total distance travelled according to the GPS module. |

### Wifi Sensor Commands (SFB)
Route: /api/sensor/
Example: Get all sensor values = /api/sensor/

------

## Warning Commands
These commands are used to send warning data from the control panel to link/computer. WarningType corresponds to the enum in WarningManager.h.

| Command | Example | Purpose |
|---|---|---|
| `W0` — Warnings Active | `W0:v=3` | Number of active warnings 3 in this example. Param format: `<value>=<count>`. |
| `W1` — List Warnings | `W1` | Retrieve warning list. Param format: No parameters. |
| `W2` — Warning Status | `W2:0x05=1` | Sends warning status for each warning. Param format: `<WarningType>=<bool>`. |
| `W3` — Clear Warnings | `W3` | Clears all warning data. Param format: No Parameters. |
| `W4` — Warning Set Status | `W4:0x06=1` | Adds or removes a warning to the list of warnings. Param format: `<WarningType>=<bool>`. |

### Wifi Warning Commands (SFB)
Only W1 is supported via wifi.
Route: /api/warning/{command}
Example: Get all active warnings = /api/warning/W1
Returns JSON formatted response with warning status and active warnings if any.

------

## Sound Signal Commands (Fog Horn) (SFB)
These commands are used to activate, query or deactivate signal sounds (Fog Horn Sounds).

| Command | Example | Purpose |
|---|---|---|
| `H0` — Cancel All | `H0` | Cancels any sound signals immediately.. Param format: No Parameters. |
| `H1` — Is Active | `H1` | Retrieves active status of sound signals in form of <SoundType>=<SoundState>. |
| `H2` — Danger | `H2` | Activates SOS horn sound until cancelled ...---... Param format: No Parameters.  |
| `H3` — Fog sound | `H3` | Activates Fog sound (depending on boat type) every 2 minutes until cancelled. Param format: No Parameters. |
| `H4` — Maneuver Starboard | `H4` | Activates maneuver starboard sound. Param format: No Parameters. |
| `H5` — Maneuver Port | `H5` | Activates maneuver port sound. Param format: No Parameters. |
| `H6` — Maneuver Astern | `H6` | Activates maneuver astern sound. Param format: No Parameters. |
| `H7` — Maneuver Danger | `H7` | Activates maneuver danger sound. Param format: No Parameters. |
| `H8` — Overtake Starboard | `H8` | Activates overtake starboard sound. Param format: No Parameters. |
| `H9` — Overtake Port | `H9` | Activates overtake port sound. Param format: No Parameters. |
| `H10` — Overtake Consent | `H10` | Activates overtake consent sound. Param format: No Parameters. |
| `H11` — Overtake Danger | `H11` | Activates overtake danger sound. Param format: No Parameters. |
| `H12` — Test | `H12` | Tests the signal sound. Param format: No Parameters. |

### Wifi Sound Signal Commands (SFB)
Route: /api/sound/{command}
Example: Overtake danger = /api/sound/H11
Returns JSON formatted response with sound status and active sound if any.

------

## Please Note
- All commands and parameters are case-sensitive.
- Commands must be sent in the exact format as specified, including any required delimiters.
- Commands specific to Boat Control Panel have (BCP) indicated next to them.
- Commands specific to Smart Fuse Box have (SFB) indicated next to them.
- All wifi commands return JSON formatted responses.

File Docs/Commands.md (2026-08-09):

# PowerControlHub Command Reference

## Overview

This document describes every command the PowerControlHub (PCH) firmware understands.
Commands travel over two transports:

| Transport | Format | Direction |
|---|---|---|
| **Serial / USB** | `<CMD>:<key>=<val>;<key>=<val>\n` | Bidirectional |
| **WiFi REST** | `POST /api/<group>/<CMD>?<key>=<val>&…` | Client → PCH |

### Command-group prefix summary

| Prefix | Group | Handler | WiFi route |
|---|---|---|---|
| `F` | System | `SystemCommandHandler` | `/api/system` |
| `C` | Configuration | `ConfigCommandHandler` / `ConfigNetworkHandler` | `/api/config` |
| `R` | Relay control & config | `RelayCommandHandler` / `RelayNetworkHandler` | `/api/relay` |
| `H` | Sound / fog-horn signals | `SoundCommandHandler` / `SoundNetworkHandler` | `/api/sound` |
| `W` | Warnings | `WarningCommandHandler` / `WarningNetworkHandler` | `/api/warning` |
| `S` | Sensor config & telemetry | `SensorConfigCommandHandler` / `SensorCommandHandler` / `SensorNetworkHandler` | `/api/sensor` |
| `M` | MQTT configuration | `MQTTConfigCommandHandler` | `/api/config` |
| `N` | Nextion display config | `NextionConfigCommandHandler` / `ConfigNetworkHandler` | `/api/config` |
| `E` | External (remote) sensor config | `ExternalSensorConfigCommandHandler` / `ExternalSensorNetworkHandler` | `/api/externalsensor` |
| `T` | Timer / scheduler | `SchedulerCommandHandler` / `SchedulerNetworkHandler` | `/api/timer` |
| `ACK` | Acknowledgement | `AckCommandHandler` | — |

### General conventions

- All commands and parameters are **case-sensitive**.
- Serial frame format: `CMD:key=val;key=val\n` — delimiter `:`, param separator `;`, key/value separator `=`.
- Up to **5 parameters** per command on the serial transport.
- Responses follow the same frame format; multi-value responses send multiple frames.
- Every mutating command that requires a **reboot** to take effect returns `reboot=1` in its ACK.
- Use `C0` (Save Settings) to persist in-memory changes to EEPROM before powering off.
- `255` / `0xFF` means **disabled / not fitted** for any pin field.

---

## System Commands — `F`

These are commands used to configure the system settings and can only be sent from a computer, they are not used for internal communication.

| Command | Example | Purpose |
|---|---|---|
| `F0` — Heart beat | `F0:w=0x00` or `F0:w=0x00;t=1733328600` | Send at rated intervals to monitor connection health. If no ACK received, indicates connection loss. **Params:** `w=<hex_warnings>` - bitmask of active local warnings (hex format). `t=<timestamp>` - Unix timestamp for continuous time sync. PowerControlHub automatically updates clock from `t=` parameter. |
| `F1` — System Initialized | `F1` | Sent by the system when initialization is complete to signal readiness. No params. Used to notify connected devices or software that the control panel is ready for operation. |
| `F2` — Free Memory | `F2` | When received will return the amount of free memory. |
| `F3` — Cpu Usage | `F3` | When received will return the current CPU usage. No params. |
| `F4` — Bluetooth Enabled | `F4` | When received will return the current enabled state of bluetooth 0 off 1 on. No params. |
| `F5` — Wifi Enabled | `F5` | When received will return the current enabled state of wifi 0 off 1 on. No params. |
| `F6` — Set DateTime | `F6:v=1733328600` | Set current date/time. Accepts Unix timestamp (seconds since epoch). Returns current stored time. |
| `F7` — Get DateTime | `F7` | Get current date/time as ISO 8601 datetime string `YYYY-MM-DDTHH:MM:SS`. |
| `F8` — SD Card Present | `F8` | Query if SD card is present. Returns `v=0` (not present) or `v=1` (present). No params. |
| `F9` — SD Card Log File Size | `F9` | Get current log file size in bytes. Returns `v=<bytes>` where bytes is the size of the active log file. Returns `v=0` if no file is open. No params. |
| `F10` — RTC Diagnostic | `F10` | Perform DS1302 RTC diagnostics. Returns status message with RTC health (availability, running state, write protection, time validity). Returns error message if RTC fails any check. No params. |
| `F11` — Uptime | F11 | Returns system uptime as "days HH:MM:SS" (e.g. 2d 03:12:45). No params. |
| `F12` — OTA Check / Apply | `F12` or `F12:apply=1` | Trigger an OTA firmware check against the latest GitHub release. Without params (or `apply=0`) checks only and returns current status. With `apply=1` downloads and applies the update if one is available (or queues apply if a check is already in progress). Response params: `v=<current>` current firmware version, `av=<available>` available version tag (empty if none found yet), `s=<state>` OTA state string. **PCH only** — requires `OTA_AUTO_UPDATE`, ESP32 and WiFi in client mode. |
| `F13` — OTA Status | `F13` | Query current OTA state without triggering a check. Response params: `v=<current>` current firmware version, `av=<available>` available version tag, `s=<state>` OTA state string (`idle`, `checking`, `available`, `downloading`, `rebooting`, `failed`, `uptodate`), `auto=<0\|1>` whether auto-apply is enabled. **PCH only** — requires `OTA_AUTO_UPDATE`, ESP32 and WiFi in client mode. |
| `F14` — PinGuard Mode | `F14` or `F14:a=true` or `F14:a=false;b=false` | Read or write the persistent PinGuard mode flags stored in `SystemHeader::pinGuardFlags`. **Params:** `a=<bool>` — AllowAdvisory: when `true`, advisory (strapping/UART) pins are permitted. `b=<bool>` — Bypass: when `true`, all PinGuard checks are skipped (no validation at all). If both `a` and `b` are `true`, Bypass takes precedence and the system returns `Safe` immediately. Changes are persisted immediately via `saveHeader()` and take effect at runtime without reboot. **Response:** `a=<0\|1>` current AllowAdvisory state, `b=<0\|1>` current Bypass state. No params = read-only. |
| `F15` — Pin Usage | `F15` | Returns a list of all GPIO pins currently assigned in configuration. Pins set to `0xFF` (disabled / not fitted) are omitted. **Serial response:** `v=pin1,pin2,...` (single frame). **WiFi response:** JSON object with a `pins` array. No params. |
| `F16` — Pin Restrictions | `F16` | Returns the compile-time pin restriction table for the current target MCU. Pins are classified as `Hard` (always blocked, e.g. flash-reserved, PSRAM) or `Advisory` (strapping, UART0, USB, JTAG — usable only when PinGuard AllowAdvisory is enabled). **Serial response:** one line per pin as `pin - category` followed by `ACK:F16=ok`. **WiFi response:** JSON object with `"hard"` and `"advisory"` integer arrays. No params. |
| `F17` — Location Types | `F17` | Returns all `LocationType` enum values as descriptors. Each entry has `id` (uint8), `type` (`boat` or `other`), and `desc` (human-readable name). **Serial response:** one line per descriptor as `F17:id=<id>;type=<boat\|other>;desc=<name>` followed by `ACK:F17=ok`. **WiFi response:** JSON object with `"success"`, `"command"`, and `"locations"` array of `{"id", "type", "description"}` objects. No params. |

**OTA behaviour (F12 / F13):**
- Automatic periodic check every 24 hours (first check fires 24 h after boot).
- `F12` without params (or `apply=0`) triggers a check only — it does **not** apply automatically.
- `F12:apply=1` downloads and applies immediately; if a check is in progress the apply is queued.
- Auto-apply is **off by default**; enable via `OtaFlagAutoApply (0x01)` in `SystemHeader::reserved[0]`.
- State transitions broadcast an `F12` automatically as they occur.
- `F13` is read-only — it never triggers any OTA activity.
- OTA is only active when `OTA_AUTO_UPDATE` is defined, the board is an ESP32, `WIFI_SUPPORT` is defined, and WiFi is in connected client mode.

### WiFi system commands
Route: `/api/system/{command}`  
Example: `GET /api/system/F2`

---

## Configuration Commands — `C`

| Command | Example | Purpose |
|---|---|---|
| `C0` — Save Settings | `C0` | Persist current in-memory config to EEPROM. Responds `SAVED` on success. No params. |
| `C1` — Get Settings | `C1` | Request full config dump. PCH replies with multiple frames covering all groups (see below). No params. |
| `C2` — Reset Settings | `C2` | Full reset of all config to factory defaults. No params. |
| `C3` — Rename Location | `C3:Sea Wolf` | Set the location name. Value directly, no `v=` prefix. Empty name → error. |
| `C4` — SPI Pins | `C4:sck=12;mosi=11;miso=13` | Set SD card SPI bus pins. Params: `sck=<pin>;mosi=<pin>;miso=<pin>`. Use `255` to clear any pin. Call `C0` to persist. |
| `C5` — Map Home Button | `C5:1=3` (map) — `C5:1=255` (unmap) | Map a home-page slot (0..3) to a relay (0..7), or `255` to unmap. |
| `C6` — XpdzTone Pin | `C6:v=12` | Set XpdzTone buzzer/piezo pin. `v=255` to disable. Call `C0` to persist. |
| `C7` — Location Type | `C7:v=1` | Set location type: `0`=Motor, `1`=Sail, `2`=Fishing, `3`=Yacht. |
| `C8` — Hw479Rgb Pins | `C8:r=12;g=13;b=14` | Set RGB LED warning indicator pins. Use `255` for any pin not fitted. Call `C0` to persist. |
| `C9` — Sound Start Delay | `C9:v=500` | Delay in milliseconds before sound starts, allowing other processing to complete. |
| `C10` — Bluetooth Enabled | `C10:v=1` | Enable (`1`) / disable (`0`) Bluetooth. Restart required. |
| `C11` — WiFi Enabled | `C11:v=1` | Enable (`1`) / disable (`0`) WiFi. Restart required. |
| `C12` — WiFi Access Mode | `C12:v=1` | Access mode: `0`=AP, `1`=Client. |
| `C13` — WiFi SSID | `C13:RouterName` | Set WiFi SSID (client mode only). Value directly, no `v=` prefix. |
| `C14` — WiFi Password | `C14:Password123` | Set WiFi password. Value directly, no `v=` prefix. |
| `C15` — WiFi Port | `C15:v=80` | Set listen port. Default `80`. Zero or invalid → error. |
| `C16` — WiFi Connection State | `C16` | Returns current `WifiConnectionState` value. Read-only, no params. |
| `C17` — WiFi AP IP Address | `C17:192.168.4.1` | Set AP-mode IP address. Value directly, no `v=` prefix. |
| `C18` — RTC Pins | `C18:dat=4;clk=5;rst=6` | Set DS1302 RTC pins. Use `255` for any pin not fitted. Call `C0` to persist. |
| `C19` — Network Authentication | `C19:e=1;k=MyApiKey;h=MyHmacKey` or `C19:g=1` | Configure WiFi API authentication. **Params:** `e=<0\|1>` enable/disable auth (disabled by default). `k=<key>` set API key (max 31 chars). `h=<key>` set HMAC-SHA256 key (max 31 chars). `g=1` auto-generate device-unique keys from the WiFi MAC address. No params returns current state as `e=<0\|1>;k=<apiKey>;h=<hmacKey>`. Call `C0` to persist. When enabled, all `/api/*` endpoints require either an `X-API-Key` header matching the configured key, or valid `X-Auth-Timestamp` + `X-Auth-Signature` HMAC headers. See [Network Authentication](#network-authentication) below. |
| `C20` — Timezone Offset | `C20:v=-5` | Set UTC timezone offset in hours. Valid range: −12 to +14. |
| `C21` — MMSI | `C21:v=123456789` | Set 9-digit Maritime Mobile Service Identity. Value directly. |
| `C22` — Call Sign | `C22:v=ABCD123` | Set location call sign. Value directly, truncated to max length. |
| `C23` — Home Port | `C23:v=Miami` | Set location home port. Value directly, truncated to max length. |
| `C24` — LED Color | `C24:t=0;c=0;r=255;g=50;b=213` | Set LED RGB color. `t`: `0`=day, `1`=night. `c`: `0`=good, `1`=bad. RGB values 0–255. |
| `C25` — LED Brightness | `C25:t=0;b=75` | Set LED brightness 0–100. `t`: `0`=day, `1`=night. |
| `C26` — LED Auto Switch | `C26:v=1` | Enable/disable automatic day/night LED switching. |
| `C27` — LED Enable States | `C27:g=1;w=1;s=0` | Enable/disable individual LEDs. `g`=GPS, `w`=Warning, `s`=System. |
| `C28` — Control Panel Tones | `C28:t=0;h=400;d=500;p=0;r=30000` | Configure tones. `t`: `0`=good, `1`=bad. `h`=Hz, `d`=duration ms. `p`=preset: `0`=custom, `1`=submarine ping, `2`=double beep, `3`=rising chirp, `4`=descending alert, `5`=nautical bell, `255`=silent. `r`=repeat interval ms (bad only, `0`=no repeat). |
| `C29` — Reload Config from SD | `C29` | **Serial only.** Reload configuration from SD card `config.txt`. |
| `C30` — Export Config to SD | `C30` | **Serial only.** Export current config to SD card. |
| `C31` — SD Card Init Speed | `C31:v=4` | Set SD card SPI init speed in MHz. Valid: 4, 8, 12, 16, 20, 24. Default 4 MHz. Higher speeds should only be used with cards that support high-speed SPI; reduce to 4–8 MHz if experiencing init failures. |
| `C32` — SD Card CS Pin | `C32:v=10` | Set SD card chip-select GPIO pin. Use `255` to disable. Call `C0` to persist. |
| `C33` — Light Sensor Threshold | `C33:v=512` | Analogue threshold (0–1023) above which daytime is detected. Default 512. Uses a rolling average of the last 10 samples; 3 consecutive consistent readings required before day/night state changes (see `S16`). |

**C1 response sequence:**  
PCH sends back: `C3` (name), `C4` (SPI pins), `C5` (home-button mappings), `C7` (location type), `C9` (sound delay), `C10`–`C17` (WiFi/Bluetooth — PCH only), `C18` (RTC pins), `C19` (network auth), `C20`–`C23` (location identity), `C24`–`C27` (LED config), `C28` (tones), `N1`–`N6` (Nextion config), `R6` per relay (names), `R7` per relay (colours), `R8` per relay (default states), `R9` (linked pairs), `R10` (action types), `R11` (pins), `S0` per sensor (sensor config), then `ACK:C1=ok`.

Common errors: `Missing param`, `Empty name`, `Invalid boat type`, `Invalid offset (-12 to +14)`, `MMSI must be 9 digits`, `Invalid speed (4, 8, 12, 16, 20, or 24 MHz)`, `Config not available`, `EEPROM commit failed`.

### WiFi configuration commands
Route: `/api/config/{command}`  
Example: `POST /api/config/C6?v=12`

---

## Nextion Display Configuration Commands — `N`

Each field is its own command so no message exceeds the 5-parameter serial limit.  
**Reboot required** for changes to take effect. Every mutating ACK carries `reboot=1`.  
Serial and network share the same handler — N-commands travel via `/api/config` on the network transport.

| Command | Example | Purpose |
|---|---|---|
| `N0` — Get Nextion Config | `N0` | Returns current config as individual `N1`–`N6` responses. No params. |
| `N1` — Enabled | `N1:v=1` | Enable (`1`) / disable (`0`) the Nextion display. Call `C0` to persist. |
| `N2` — Hardware Serial | `N2:v=1` | Serial mode: `1`=HardwareSerial, `0`=SoftwareSerial (uses rxPin/txPin). Call `C0` to persist. |
| `N3` — RX Pin | `N3:v=16` | Set RX pin. Use `255` to clear. Call `C0` to persist. |
| `N4` — TX Pin | `N4:v=17` | Set TX pin. Use `255` to clear. Call `C0` to persist. |
| `N5` — Baud Rate | `N5:v=9600` | Set serial baud rate. Call `C0` to persist. |
| `N6` — UART Number | `N6:v=1` | ESP32 UART peripheral index. Valid values: `1` or `2` (UART0 reserved for USB/debug). Call `C0` to persist. |

**WiFi route:** `/api/config/{command}`  
**Example:** `POST /api/config/N1?v=1`

**Setup example:**
```
N1:v=1    # Enable Nextion
N2:v=1    # Hardware serial
N3:v=16   # RX pin
N4:v=17   # TX pin
N5:v=9600 # Baud rate
N6:v=1    # UART1
C0        # Save to EEPROM
```

---

## External Sensor Configuration Commands — `E`

These commands configure the `RemoteSensorsConfig` array used to construct `RemoteSensor` instances dynamically at boot. Because each sensor record has more fields than the 5-parameter serial limit, add/update is split across two commands (`E1` for core fields, `E2` for MQTT detail fields).

**Reboot required** for changes to take effect. Every mutating ACK carries `reboot=1`.

| Command | Example | Purpose |
|---|---|---|
| `E0` — Get All | `E0` | Returns two frames per configured sensor (core fields then MQTT fields). No params. |
| `E1` — Set Core Fields | `E1:i=0;id=3;n=Gps;mn=Latitude;ms=latitude` | Set identity and core MQTT fields for sensor at index `i`. Params: `i=<idx>` (0-based, max `ConfigMaxSensors`); `id=<sensorId>` (`SensorIdList` enum value); `n=<name>` (≤20 chars — also used as the serial command ID that external devices push updates to); `mn=<mqttName>` (≤15 chars); `ms=<mqttSlug>` (≤15 chars). Call `C0` to persist. |
| `E2` — Set MQTT Fields | `E2:i=0;mt=latitude;md=;mu=°;bin=0` | Set MQTT type/device-class/unit fields for sensor at index `i`. Params: `i=<idx>`; `mt=<mqttTypeSlug>` (≤15 chars); `md=<mqttDeviceClass>` (≤15 chars, empty to clear); `mu=<mqttUnit>` (≤10 chars, empty to clear); `bin=<0\|1>` (binary sensor flag). Call `C0` to persist. |
| `E3` — Remove | `E3:0` | Remove sensor at index. Remaining entries are compacted down. Call `C0` to persist. |
| `E4` — Rename | `E4:0=GpsUnit` | Rename sensor at index. Param format: `<idx>=<name>`. Call `C0` to persist. |

**`E0` response format (two frames per sensor):**
```
E0:i=<idx>;id=<sensorId>;n=<name>;mn=<mqttName>;ms=<mqttSlug>
E0:i=<idx>;mt=<mqttTypeSlug>;md=<mqttDeviceClass>;mu=<mqttUnit>;bin=<0|1>
```

**`SensorIdList` values for the `id` parameter:**

| Value | Name |
|---|---|
| `0` | WaterSensor |
| `1` | Dht11Sensor |
| `2` | LightSensor |
| `3` | GpsSensor |
| `4` | SystemSensor |
| `5` | BinaryPresenceSensor |
| `6` | VoltageSensor |

**How external sensors receive value updates:**  
After boot the `name` field doubles as the sensor's serial command ID. An external device pushes readings by sending the name as a command:
```
Gps:lat=51.507351;lon=-0.127758
```
`SensorCommandHandler` routes this to the matching `RemoteSensor` which stores the values for MQTT publishing and status queries.

**WiFi route:** `/api/externalsensor/{command}`  
**GET** `/api/externalsensor/` returns a JSON status block with all configured sensors.  
**Example:** `POST /api/externalsensor/E1?i=0&id=3&n=Gps&mn=Latitude&ms=latitude`

**Setup example (GPS sensor with two channels):**
```
E1:i=0;id=3;n=Gps;mn=Latitude;ms=latitude
E2:i=0;mt=latitude;md=;mu=°;bin=0
E1:i=1;id=3;n=Gps;mn=Longitude;ms=longitude
E2:i=1;mt=longitude;md=;mu=°;bin=0
C0    # Save to EEPROM — reboot to activate
```

Common errors: `Config not available`, `Invalid sensor index`, `Invalid or missing parameters`, `Missing sensor index`, `Missing parameters`, `Missing name`.

---

## Acknowledgement — `ACK`

Every command returns an ACK frame on the serial transport:

| Example | Meaning |
|---|---|
| `ACK:R3=ok` | Command `R3` processed successfully. |
| `ACK:R3=Index out of range` | Command `R3` failed with the given error message. |

WiFi commands return JSON (`{"success":true}` or `{"success":false,"message":"…"}`) rather than ACK frames.

---

## Relay Control & Configuration Commands — `R`

| Command | Example | Purpose |
|---|---|---|
| `R0` — Turn All Off | `R0` | Turn off all relays. No params. |
| `R1` — Turn All On | `R1` | Turn on all relays. No params. |
| `R2` — Retrieve States | `R2` | Return the current state of all relays. |
| `R3` — Set Relay State | `R3:3=1` | Set relay `idx` on (`1`) or off (`0`). Param: `<idx>=<state>`. `idx` 0..7. |
| `R4` — Get Relay State | `R4:3` | Return state of relay at `idx`. Param: `<idx>`. |
| `R5` — Get All Relay Config | `R5` | Returns full relay config as a series of `R6`–`R11` responses. No params. |
| `R6` — Relay Rename | `R6:2=Bilge` or `R6:2=Bilge\|Bilge Pump` | Rename relay `idx`. Param: `<idx>=<shortName>` or `<idx>=<short\|long>`. Short ≤5 chars (home page), long ≤20 chars (buttons page). |
| `R7` — Set Button Color | `R7:2=4` or `R7:2=255` (clear) | Set active (on) button colour for relay `idx`. `0`=Blue, `1`=Green, `2`=Orange, `3`=Purple, `4`=Red, `5`=Yellow, `255`=clear. |

| `R7` — Set Button Color | `R7:2=4` or `R7:2=255` (clear) | Set active (on) button colour for relay `idx`. Accepts Nextion picture IDs (as stored on the device): `2`=Blue, `3`=Green, `4`=Grey, `5`=Orange, `6`=Red, `7`=Yellow, `255`=clear. |
| `R8` — Set Default State | `R8:3=1` | Power-on default state for relay `idx`: `0`=off, `1`=on. |
| `R9` — Link Relays | `R9:3=4` (link) — `R9:3=255` (unlink) | Link two relays so toggling one toggles the other. `255` to unlink. |
| `R10` — Set Action Type | `R10:2=0` / `R10:2=1` / `R10:2=2` | Set relay action type: `0`=Default, `1`=Horn (activates sound system), `2`=NightRelay (activates at night per light sensor). Only one relay per type at a time. |
| `R11` — Set Pin | `R11:2=15` | Set GPIO pin for relay `idx`. Must be a valid non-zero pin number or 255 to disable |

### WiFi relay commands
Route: `/api/relay/{command}`  
Example: `POST /api/relay/R3?3=1`

---

## Sound / Fog-Horn Signal Commands — `H`

| Command | Example | Purpose |
|---|---|---|
| `H0` — Cancel All | `H0` | Cancel all active sound signals immediately. No params. |
| `H1` — Is Active | `H1` | Returns active status as `<SoundType>=<SoundState>` pairs. No params. |
| `H2` — SOS / Danger | `H2` | Activates SOS horn sound (`...---...`) until cancelled. No params. |
| `H3` — Fog Signal | `H3` | Activates fog signal (location-type dependent) every 2 minutes until cancelled. No params. |
| `H4` — Manoeuvre Starboard | `H4` | One short blast. No params. |
| `H5` — Manoeuvre Port | `H5` | Two short blasts. No params. |
| `H6` — Manoeuvre Astern | `H6` | Three short blasts. No params. |
| `H7` — Manoeuvre Danger | `H7` | Five short rapid blasts. No params. |
| `H8` — Overtake Starboard | `H8` | Two prolonged + one short blast. No params. |
| `H9` — Overtake Port | `H9` | Two prolonged + two short blasts. No params. |
| `H10` — Overtake Consent | `H10` | One prolonged + one short + one prolonged + one short blast. No params. |
| `H11` — Overtake Danger | `H11` | Five short rapid blasts. No params. |
| `H12` — Test | `H12` | Test the horn/buzzer. No params. |

### WiFi sound commands
Route: `/api/sound/{command}`  
Example: `POST /api/sound/H3`

---

## Warning Commands — `W`

| Command | Example | Purpose |
|---|---|---|
| `W0` — Warnings Active | `W0:v=3` | Sent by SFB; indicates count of currently active warnings. |
| `W1` — List Warnings | `W1` | Retrieve warning list. Returns one `W2` frame per warning. No params. |
| `W2` — Warning Status | `W2:0x05=1` | Status of a single warning type. Param: `<WarningType>=<0\|1>`. |
| `W3` — Clear Warnings | `W3` | Clear all active warnings. No params. |
| `W4` — Set Warning Status | `W4:0x06=1` | Raise (`1`) or clear (`0`) a specific warning. Param: `<WarningType>=<0\|1>`. |
| `W5` — List Warning Text | `W5` | Returns one `W5:<hex>=<description>` frame per active warning and ends with `ACK:W5=ok`. Use this to get human-readable descriptions of all active warnings. No params. **WiFi response:** `{"success":true,"warnings":["desc1","desc2"]}`. |

### WiFi warning commands
Route: `/api/warning/{command}`  
Example: `GET /api/warning/W1`

---

## MQTT Configuration Commands — `M` (SFB only)

Requires `MQTT_SUPPORT` to be defined. M-commands share the `/api/config` network route.

| Command | Example | Purpose |
|---|---|---|
| `M0` — MQTT Enabled | `M0:v=1` | Enable (`1`) / disable (`0`) MQTT. Query without params returns current state. |
| `M1` — Broker Address | `M1:192.168.1.100` | Set broker hostname or IP. Value directly, no `v=` prefix. |
| `M2` — Broker Port | `M2:v=1883` | Set broker port. Default 1883. |
| `M3` — Username | `M3:myuser` | Set MQTT username. Leave empty for unauthenticated. |
| `M4` — Password | `M4:mypassword` | Set MQTT password. |
| `M5` — Device ID | `M5:boat_seawolf_01` | Set unique device identifier used in all topic paths: `<prefix>/<deviceId>/…`. |
| `M6` — HA Discovery | `M6:v=1` | Enable/disable Home Assistant auto-discovery messages. |
| `M7` — Keep-Alive | `M7:v=60` | PING interval in seconds. Default 60. |
| `M8` — Connection State | `M8` | Returns `v=0` (disconnected) or `v=1` (connected). Read-only. |
| `M9` — Discovery Prefix | `M9:homeassistant` | Base topic prefix. Default `homeassistant`. Used in all discovery and state topics. |

**MQTT topic structure:**
- Relay state / command: `<prefix>/<deviceId>/relay/<idx>/state` / `.../set`
- Sensor data: `<prefix>/<deviceId>/sensor/<type>/state`
- System metrics: `<prefix>/<deviceId>/system/<metric>/state`
- Warnings: `<prefix>/<deviceId>/warning/active/state`
- HA discovery: `<prefix>/switch/<deviceId>/relay<idx>/config`

**Setup example:**
```
M0:v=1              # Enable MQTT
M1:192.168.1.100    # Broker IP
M5:boat_seawolf_01  # Device ID
C0                  # Save to EEPROM
```

### WiFi MQTT commands
Route: `/api/config/{command}` (shares the config route)

---

## Sensor Commands — `S`

`S0`–`S6` are configuration commands (persisted in EEPROM, **reboot required**).  
`S7`–`S23` are live telemetry commands (sensor readings).

### Sensor Configuration — `S0`–`S6`

| Command | Example | Purpose |
|---|---|---|
| `S0` — Get All Sensor Config | `S0` or `S0?meta=1` | Returns one `S0` frame per configured sensor: `i=<idx>;t=<type>;n=<name>;p0=<pin>;p1=<pin>;u0=<opt1_0>;u1=<opt1_1>;o0=<opt2_0>;o1=<opt2_1>;en=<0\|1>`. The labels in the response are read-only aliases: `p0`/`p1` = `pins[0]`/`pins[1]`; `u0`/`u1` = `options1[0]`/`options1[1]` (signed byte); `o0`/`o1` = `options2[0]`/`options2[1]` (signed 16-bit). **WiFi only:** Append `?meta=1` to include a `"meta"` block with sensor type descriptors (field labels, types, ranges, defaults) for self-describing dynamic UI. No serial params. |
| `S1` — Add / Update Sensor | `S1:i=<idx>;t=<type>;o0=<val>;o1=<val>` | Add or update sensor at index `i`. **Only four params are accepted:** `i` (sensor index), `t` (type — `SensorIdList` enum value), `o0` (writes `options1[0]`), `o1` (writes `options1[1]`). Pins and all other options must be set separately via `S4` and `S6` **after** `S1`. All four params are required. ACK carries `reboot=1`. |
| `S2` — Remove Sensor | `S2:v=0` | Remove (clear) sensor at index. Param: `v=<idx>`. ACK carries `reboot=1`. |
| `S3` — Rename Sensor | `S3:0=Bilge Pump` | Rename sensor at index. Param: `<idx>=<name>`. ACK carries `reboot=1`. |
| `S4` — Set Sensor Pin | `S4:i=0;s=0;v=34` | Set a GPIO pin for sensor `i`. **All three params are required:** `i` (sensor index), `s` (pin slot, 0..`ConfigMaxSensorPins-1`), `v` (GPIO pin number; `255` to clear). Each sensor type uses specific slots — see the sensor type table below. ACK carries `reboot=1`. |
| `S5` — Set Sensor Enabled | `S5:0=1` | Enable (`1`) / disable (`0`) sensor at index. ACK carries `reboot=1`. |
| `S6` — Set Sensor Option | `S6:i=0;s=0;o=0;v=1` | Set an option value for sensor `i`. **All four params are required:** `i` (sensor index), `s` (slot, 0 or 1), `o` (group: `0`=`options1` signed byte, `1`=`options2` signed 16-bit), `v` (value). See the sensor type table below for which slot/group each sensor uses. ACK carries `reboot=1`. |

> **Understanding the field storage and response labels**
>
> Sensor configuration is stored in three arrays inside `SensorEntry`. The `S0` response exposes these with short labels for readability, but you **cannot use those labels as input to `S1`**:
>
> | `S0` response label | Underlying storage | Command to write it |
> |---|---|---|
> | `p0` | `pins[0]` | `S4:i=<idx>;s=0;v=<pin>` |
> | `p1` | `pins[1]` | `S4:i=<idx>;s=1;v=<pin>` |
> | `u0` | `options1[0]` (signed byte) | `S6:i=<idx>;s=0;o=0;v=<val>` |
> | `u1` | `options1[1]` (signed byte) | `S6:i=<idx>;s=1;o=0;v=<val>` |
> | `o0` | `options2[0]` (signed 16-bit) | `S6:i=<idx>;s=0;o=1;v=<val>` |
> | `o1` | `options2[1]` (signed 16-bit) | `S6:i=<idx>;s=1;o=1;v=<val>` |
>
> `S1` only writes `options1[0]` and `options1[1]` (its `o0`/`o1` params). Everything else requires a separate `S4` or `S6` call.

**Sensor type values (`t` for `S1`) — field mapping:**

The table below shows what each storage field means for each sensor type and which command sets it.

| Value | Name | Field | Meaning | Command |
|---|---|---|---|---|
| `0` | Water Sensor | `pins[0]` | Data pin | `S4:i=<idx>;s=0;v=<pin>` |
| | | `pins[1]` | Power pin | `S4:i=<idx>;s=1;v=<pin>` |
| `1` | DHT11 | `pins[0]` | Data pin | `S4:i=<idx>;s=0;v=<pin>` |
| `2` | Light Sensor | `pins[0]` | Analogue pin | `S4:i=<idx>;s=0;v=<pin>` |
| | | `options1[0]` | `1`=digital mode, `0`=analogue mode | `S1:…;o0=<val>;o1=0` |
| `3` | GPS Sensor | `pins[0]` | RX pin (**required** — `255` raises `GpsInvalidConfig`) | `S4:i=<idx>;s=0;v=<pin>` |
| | | `pins[1]` | TX pin (**required** — `255` raises `GpsInvalidConfig`) | `S4:i=<idx>;s=1;v=<pin>` |
| | | `options1[0]` | UART number: `1` or `2` (ESP32 only; other values default to `2`). Baud rate fixed at 9600. | `S6:i=<idx>;s=0;o=0;v=<uart>` |
| `4` | System Sensor | — | No pin or option required | — |
| `5` | Binary Presence Sensor | `pins[0]` | Sensor pin | `S4:i=<idx>;s=0;v=<pin>` |
| | | `pins[1]` | onDetected payload | `S4:i=<idx>;s=1;v=<val>` |
| | | `pins[2]` | onClear payload | `S4:i=<idx>;s=2;v=<val>` |
| | | `options1[0]` | Active state: `1`=HIGH, `0`=LOW | `S1:…;o0=<val>;o1=0` |
| | | `options1[1]` | onDetected action | `S6:i=<idx>;s=1;o=0;v=<val>` |
| | | `options2[1]` | onClear action | `S6:i=<idx>;s=1;o=1;v=<val>` |
| `6` | Voltage Sensor | `pins[0]` | Analogue input pin | `S4:i=<idx>;s=0;v=<pin>` |
| | | `options1[0]` | ADC Vref in tenths of a volt (`50`=5.0 V, `33`=3.3 V; `0`=default 5.0 V) | `S6:i=<idx>;s=0;o=0;v=<val>` |
| | | `options1[1]` | R2 in tenths of kΩ (`75`=7.5 kΩ; `0`=default 7.5 kΩ) | `S6:i=<idx>;s=1;o=0;v=<val>` |
| | | `options2[0]` | R1 in whole kΩ (`30`=30 kΩ; `0`=default 30 kΩ) | `S6:i=<idx>;s=0;o=1;v=<val>` |
| | | `options2[1]` | Low-voltage warning threshold in tenths of a volt (`114`=11.4 V; `0`=disabled) | `S6:i=<idx>;s=1;o=1;v=<val>` |

**Voltage sensor setup example (30 kΩ / 7.5 kΩ divider, 12 V system, warn below 11.4 V):**
```
S1:i=1;t=6;o0=0;o1=0   # Add Voltage sensor (type 6)
S3:1=Battery            # Name it
S4:i=1;s=0;v=34         # Analogue pin = 34
S6:i=1;s=0;o=0;v=50     # Vref = 5.0 V (50 tenths)
S6:i=1;s=1;o=0;v=75     # R2 = 7.5 kΩ (75 tenths)
S6:i=1;s=0;o=1;v=30     # R1 = 30 kΩ
S6:i=1;s=1;o=1;v=114    # Low-voltage warn at 11.4 V (114 tenths); use 0 to disable
S5:1=1                  # Enable sensor
C0                      # Save to EEPROM — reboot to activate
```

Common sensor config errors: `Config not available`, `Invalid sensor index`, `Missing sensor index`, `Missing parameters`, `Missing name`, `Invalid pin slot`, `Invalid option slot`.

**GPS setup example (ESP32 NodeMCU-32S — Nextion on UART2, GPS remapped to UART1 on pins 25/26):**
```
S1:i=0;t=3;o0=0;o1=0   # Add GPS sensor (type 3)
S3:0=GPS                # Name it
S4:i=0;s=0;v=25         # RX pin = 25
S4:i=0;s=1;v=26         # TX pin = 26
S6:i=0;s=0;o=0;v=1      # UART number = 1 (avoids conflict with Nextion on UART2)
S5:0=1                  # Enable sensor
C0                      # Save to EEPROM — reboot to activate
```
> **Note:** If either RX or TX pin is `255` (disabled) the GPS sensor will **not** be created at boot and a `GpsInvalidConfig` warning will be raised. Both pins must be set before saving.

### Sensor Telemetry — `S7`–`S23`

| Command | Example | Purpose |
|---|---|---|
| `S7` — Temperature | `S7:v=72.5` | Temperature reading. |
| `S8` — Humidity | `S8:v=55.2` | Humidity reading. |
| `S9` — Bearing | `S9:v=128` | Compass bearing in degrees. |
| `S10` — Direction | `S10:v=NNW` | Cardinal direction string. |
| `S11` — Speed | `S11:v=3.4` | Speed reading. |
| `S12` — Compass Temp | `S12:v=23.4` | Compass module temperature. |
| `S13` — Water Level | `S13:v=3.4` | Water level reading. |
| `S14` — Water Pump Active | `S14:v=1` | Water pump state: `0`=off, `1`=on. |
| `S15` — Horn Active | `S15:v=1` | Horn state: `0`=off, `1`=on. |
| `S16` — Light Sensor | `S16:v=1` | Daytime state: `0`=night, `1`=day. See `C33` for threshold. |
| `S17` — GPS Lat/Long | `S17:lat=51.507351;lon=-0.127758` | GPS coordinates in decimal degrees (6 d.p.). |
| `S18` — GPS Altitude | `S18:v=125.50` | Altitude in metres (2 d.p.). |
| `S19` — GPS Speed | `S19:v=15.75;course=245.30;dir=NNW` | Speed km/h, course degrees (0–360), optional cardinal direction. |
| `S20` — GPS Satellites | `S20:v=8` | Number of connected satellites. |
| `S21` — GPS Distance | `S21:v=1.23` | Total distance travelled. |
| `S22` — Binary Presence | `S22:v=1;name=PIR` | Pin-change event: `v=1` detected, `v=0` clear. `name` = configured sensor name. |
| `S23` — Voltage | `S23:v=12.45;avg=12.41` | Voltage reading from the DC 0–25 V module. `v`=latest sample in volts (2 d.p.), `avg`=10-reading rolling average in volts (2 d.p.). Raises `LowVoltage` warning when `avg` drops below the configured threshold; clears when it recovers. |

### WiFi sensor commands
Route: `/api/sensor/`  
Example: `GET /api/sensor/`

---

## Timer / Scheduler Commands — `T`

Up to 20 scheduled events stored in EEPROM (6 max on platforms with < 1 KB EEPROM). Each event has a **trigger**, an optional **condition**, and an **action**.

| Command | Example | Purpose |
|---|---|---|
| `T0` — List Events | `T0` | Returns `count=<n>;s=<0,1,0,…>` — enabled state for every slot. |
| `T1` — Get Event | `T1:v=2` | Returns full detail of event at index `v` in `T2` format. Error if slot empty. |
| `T2` — Set Event | `T2:i=0;e=1;t=1,18,30,0,0;c=0,0,0,0,0;a=2,2,0,0,0` | Add/update event at index `i`. Params: `i=<idx>;e=<enabled>;t=<type,b0,b1,b2,b3>;c=<type,b0,b1,b2,b3>;a=<type,b0,b1,b2,b3>`. Each field is 5 comma-separated values (type + 4 payload bytes). Call `C0` to persist. |
| `T3` — Delete Event | `T3:v=2` | Clear event at index `v`. Call `C0` to persist. |
| `T4` — Enable / Disable | `T4:i=2;v=1` | Enable (`v=1`) or disable (`v=0`) event at index `i`. Call `C0` to persist. |
| `T5` — Clear All | `T5` | Remove all 20 events. Call `C0` to persist. |
| `T6` — Trigger Now | `T6:v=2` | Execute the action of event `v` immediately, bypassing trigger and condition. Useful for testing. |

**Trigger types (`t` first value):**

| Type | Name | Payload `b0..b3` |
|---|---|---|
| `0` | None | Never fires automatically |
| `1` | TimeOfDay | `b0`=hour (0–23), `b1`=minute (0–59) |
| `2` | Sunrise | `b0..b1`=int16 offset minutes (+after, −before) |
| `3` | Sunset | `b0..b1`=int16 offset minutes |
| `4` | Interval | `b0..b1`=uint16 interval minutes |
| `5` | DayOfWeek | `b0`=bitmask (bit0=Mon…bit6=Sun). Mon–Fri=31, weekends=96, all days=127 |
| `6` | Date | `b0`=day (1–31), `b1`=month (1–12) |

**Condition types (`c` first value):**

| Type | Name | Payload `b0..b3` |
|---|---|---|
| `0` | None | Always fires |
| `1` | TimeWindow | `b0`=start_hour, `b1`=start_min, `b2`=end_hour, `b3`=end_min |
| `2` | DayOfWeek | `b0`=bitmask (same layout as trigger DayOfWeek) |
| `3` | IsDark | True between sunset and sunrise |
| `4` | IsDaylight | True between sunrise and sunset |
| `5` | RelayIsOn | `b0`=relay index |
| `6` | RelayIsOff | `b0`=relay index |

**Action types (`a` first value):**

| Type | Name | Payload `b0..b3` |
|---|---|---|
| `0` | None | Nothing happens |
| `1` | RelayOn | `b0`=relay index |
| `2` | RelayOff | `b0`=relay index |
| `3` | RelayToggle | `b0`=relay index |
| `4` | RelayPulse | `b0`=relay index, `b1..b2`=uint16 duration seconds (little-endian) |
| `5` | AllRelaysOn | — |
| `6` | AllRelaysOff | — |
| `7` | SetPinHigh | `b0`=GPIO pin number |
| `8` | SetPinLow | `b0`=GPIO pin number |

**Examples:**
```
# At 18:30 turn Relay 3 off (relay index 2, 0-based)
T2:i=0;e=1;t=1,18,30,0,0;c=0,0,0,0,0;a=2,2,0,0,0
C0

# 10 minutes after sunset turn Relay 2 on (relay index 1, offset +10 min)
T2:i=1;e=1;t=3,10,0,0,0;c=0,0,0,0,0;a=1,1,0,0,0
C0

# At sunrise on weekdays only, toggle Relay 1 (relay index 0, Mon–Fri bitmask=31)
T2:i=2;e=1;t=2,0,0,0,0;c=2,31,0,0,0;a=3,0,0,0,0
C0

# Every 30 minutes, pulse Relay 5 for 10 seconds (relay index 4, interval=30, duration=10)
T2:i=3;e=1;t=4,30,0,0,0;c=0,0,0,0,0;a=4,4,10,0,0
C0
```

Common errors: `Index out of range`, `Missing params`, `Invalid trigger type`, `Invalid condition type`, `Invalid action type`, `Invalid enabled value (0 or 1)`, `Slot is empty`.

### WiFi timer commands
Route: `/api/timer/{command}`  
Example: `GET /api/timer/T0`

---

## Network Authentication

When network auth is enabled (`C19:e=1`), every request to `/api/*` endpoints must include authentication credentials. Two authentication methods are supported; clients may use either one.

### API Key (simple)

Include the `X-API-Key` header with the value of the configured API key:

```bash
curl -H "X-API-Key: ak-sfb-A1B2C3" http://DEVICE/api/system/F7
```

### HMAC-SHA256 (strong)

Include two headers: `X-Auth-Timestamp` (Unix epoch seconds) and `X-Auth-Signature` (lowercase hex HMAC-SHA256 of the canonical request).

**Canonical signing input format:**
```
<timestamp>\n<METHOD>\n<path>\n<body>
```

- `timestamp` — same value as `X-Auth-Timestamp`
- `METHOD` — HTTP method: `GET`, `POST`, etc.
- `path` — request path, e.g. `/api/relay/R3`
- `body` — raw request body for POST; empty string for GET

**Example (Bash):**
```bash
TS=$(date +%s)
PATH="/api/system/F7"
METHOD="GET"
BODY=""
HMAC_KEY="hk-sfb-A1B2C3"

SIGN_INPUT="${TS}\n${METHOD}\n${PATH}\n${BODY}"
SIG=$(echo -ne "$SIGN_INPUT" | openssl dgst -sha256 -hmac "$HMAC_KEY" | awk '{print $NF}')

curl -H "X-Auth-Timestamp: ${TS}" -H "X-Auth-Signature: ${SIG}" http://DEVICE${PATH}
```

### Timestamp window and clock bootstrap

- The HMAC timestamp must be within ±300 seconds (5 minutes) of the device's clock.
- **`F6` (Set DateTime) is always permitted via all transports**, even when auth is enabled, as long as the device clock has **never** been synchronized. Once time is set, `F6` requires authentication like all other commands. This prevents a deadlock where the client needs auth to set the clock but the clock is wrong, causing HMAC verification to fail.
- Clients can use an **API Key** to bootstrap the clock via `F6`, then switch to HMAC for stronger ongoing security.

### Best practices

1. **Enable auth after initial setup:** `C19:g=1` to generate per-device unique keys, then `C19:e=1` to enable.
2. **Persist changes:** Call `C0` (Save Settings) after configuring auth to survive power cycles.
3. **Synchronize the clock:** Use `F0:w=0x00;t=<timestamp>` heartbeat or `F6:v=<timestamp>` to keep the device clock accurate for HMAC.
4. **Rotate keys periodically:** `C19:k=<newkey>` and `C19:h=<newkey>` then `C0` to persist.

Common errors: `API key too long`, `HMAC key too long`.

---

## Notes

- All commands and parameters are case-sensitive.
- Commands must be sent in the exact format shown, including delimiters.
- All WiFi responses are JSON formatted.
- Changes to sensor config (`S`), external sensor config (`E`), and Nextion display config (`N`) require a **reboot** to take effect.
- Always call `C0` (Save Settings) after making config changes you want to survive a power cycle.

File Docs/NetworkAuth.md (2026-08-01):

# NetworkAuth — WiFi API Authentication

NetworkAuth is a dual-mode authentication layer that protects the device's HTTP API from unauthorised access over WiFi. It is disabled by default and must be explicitly enabled via the serial console, Bluetooth, or the MAUI application after initial configuration.

---

## Why It Exists

The ESP32 HTTP server exposes every control surface of the device — relay toggling, sensor data, pin configuration, MQTT credentials, and firmware updates — as REST endpoints at well-known paths. Without authentication:

- Any device on the same WiFi network can toggle relays, change pin assignments, or trigger OTA updates.
- The `/api/index` response includes the API key and HMAC key in cleartext, allowing an attacker to harvest credentials and impersonate the authorised MAUI client.
- Browser-based discovery (e.g. Chrome typing `192.168.4.1/api/index`) immediately leaks all device state and secrets.

NetworkAuth gates every HTTP request (including `/api/index`) behind credential verification. Requests lacking valid credentials receive `401 Unauthorized`.

---

## How It Works

### Server-Side Enforcement

Auth is enforced inside `WifiServer::processClientRequest()` in `WifiServer.cpp`. The check runs **before** any route handler is dispatched:

```cpp
if (_authConfig != nullptr && _authConfig->enabled)
{
    // parse X-API-Key, X-Auth-Timestamp, X-Auth-Signature headers
    // validate API key match OR HMAC signature
    if (!authorized)
    {
        sendResponse(401, …);
        cleanupClient(index);
        return;
    }
}
```

If `_authConfig` is `nullptr` or `enabled == false`, the check is skipped and all requests are serviced without credentials.

The `_authConfig` pointer is set once at startup from the global `Config` struct (stored in EEPROM) via `WifiServer::setAuthConfig()`. It points to the live in-memory config, so changes take effect immediately after a save (no reboot required).

### Credential Storage

Auth credentials live in `Config.h` as part of the persistent `Config` struct:

```cpp
struct NetworkAuthConfig {
    bool    enabled;                     // master switch
    uint8_t version;                    // reserved
    char    apiKey[32];                 // "ak-XXXX…" — 31 chars + null
    char    hmacKey[32];                // "hk-XXXX…" — 31 chars + null
    uint8_t reserved[4];
} __attribute__((packed));
```

Both keys are 31 characters max, null-terminated. The `version` and `reserved` fields are reserved for future use.

---

## Authentication Mechanisms

Two independent mechanisms are supported. Either one grants access.

### 1. API Key (Simple)

**Header:** `X-API-Key: ak-pch-1712A0`

The server performs an exact string comparison against `_authConfig->apiKey`. If they match, the request is authorised.

This is the simplest method. It requires no timestamp or body hashing and works even when the device RTC has not been set. It is less secure than HMAC because the key is transmitted verbatim on every request and could be captured from HTTP traffic (the connection is plain HTTP, not HTTPS).

### 2. HMAC-SHA256 (Strong)

**Headers:**

| Header | Value |
|---|---|
| `X-Auth-Timestamp` | Unix timestamp (seconds) of the signing moment |
| `X-Auth-Signature` | Lowercase hex-encoded HMAC-SHA256 signature |

**Signing input format** (canonical, one `\n`-separated line):

```
{timestamp}\n{METHOD}\n{path}\n{body}
```

Example signing input for `GET /api/index` with no body at timestamp `1746000000`:

```
1746000000
GET
/api/index

```

The signature is computed as `HMAC-SHA256(hmacKey, signInput)` and encoded as lowercase hex.

**Timestamp window:** ±300 seconds (5 minutes). Requests outside this window are rejected. This requires the device RTC to be set. If `DateTimeManager::isTimeSet()` returns false, HMAC verification is skipped and only API key auth can succeed.

**Device time synchronisation:** The ESP32 has no battery-backed RTC and loses time on power cycle. The device clock must be set before HMAC authentication will function. Command `F6` sets the system date/time:

```
F6;2026-07-15T14:30:00
```

The MAUI app sends `F6` automatically on first connection via the `TimeSyncService`, so HMAC works out of the box after pairing with the app. If connecting from a custom client or script, send `F6` with the current UTC time in ISO 8601 format before issuing HMAC-signed requests.

**HMAC key format:** `hk-XXXX…` — 31 characters. The key is the HMAC secret shared between client and server.

### Header Parsing

Headers are extracted from the raw HTTP request buffer by case-insensitive substring search. Both `X-API-Key:` and `x-api-key:` are recognised. Header values extend to the next `\r\n` or `\n`.

---

## Guarded Endpoints

When auth is enabled, **all** HTTP endpoints are guarded. This includes:

| Path | Method | Description |
|---|---|---|
| `/api/index` | GET | Full device state JSON (relays, sensors, config, auth keys) |
| `/api/relay/*` | GET/POST | Relay control and configuration |
| `/api/config/*` | GET/POST | Device configuration (pins, network, auth itself) |
| `/api/sensor/*` | GET/POST | Sensor configuration |
| `/api/sound/*` | GET/POST | Sound/signal control |
| `/api/system/*` | GET/POST | System commands, OTA, time |
| `/api/warning/*` | GET/POST | Warning manager |
| `/api/mqtt/*` | GET/POST | MQTT broker settings |
| `/api/scheduler/*` | GET/POST | Schedule management |
| `/api/externalsensor/*` | GET/POST | External sensor registration |

The built-in web UI (`/index` — HTML page) is **not** guarded by auth. However, its embedded JavaScript calls `fetch('/api/index')` every 5 seconds to refresh data. When auth is enabled, these fetch calls will receive `401` and the web UI will show stale data. This is by design — the web UI is a convenience dashboard for trusted local networks. For secure operation, use the MAUI application which sends proper auth headers.

---

## Configuration Interface

### Command `C19` — Network Authentication

Auth is configured via command `C19` on all transports (serial, Bluetooth, WiFi).

**Serial / Bluetooth format:**

```
C19                  — read current state
C19;e=1              — enable auth
C19;e=0              — disable auth
C19;k=ak-newkey      — set API key
C19;h=hk-newkey      — set HMAC key
C19;g=1              — auto-generate both keys
```

**WiFi HTTP format:**

```
GET  /api/config/C19                              — read current state
POST /api/config/C19?e=1                          — enable
POST /api/config/C19?k=ak-newkey                  — set API key
POST /api/config/C19?h=hk-newkey                  — set HMAC key
POST /api/config/C19?g=1                          — auto-generate keys
POST /api/config/C19?e=1&k=ak-X&h=hk-X            — combined
```

**Read response** (serial):

```
ACK:C19:e=1;k=ak-pch-1712A0;h=hk-sfb-1712A0
```

**Read response** (WiFi JSON):

```json
{"e":true,"k":"ak-pch-1712A0","h":"hk-sfb-1712A0"}
```

### Parameter Reference

| Param | Type | Description |
|---|---|---|
| `e` | bool (`0`/`1` or `true`/`false`) | Enable/disable authentication |
| `k` | string (≤31 chars) | API key value |
| `h` | string (≤31 chars) | HMAC secret key value |
| `g` | bool (`0`/`1` or `true`/`false`) | Generate new device-unique keys |

### Key Generation (`g=1`)

When `g=1` is sent, the device calls `ConfigController::generateAuthKeys()` which:

1. Generates a device-unique deterministic password via `SystemFunctions::GenerateDefaultPassword()`
2. Prefixes it with `ak-` for the API key and `hk-` for the HMAC key
3. Writes both into `config.auth.apiKey` and `config.auth.hmacKey`

The device ID used for generation is derived from hardware characteristics, making keys unique to each ESP32. Generated keys follow the pattern `ak-XXXX` / `hk-XXXX` where `XXXX` is the device-specific component.

### Validation Rules

When setting keys via `k=` or `h=`:

- **Null key:** Setting a key to an empty or null value **disables auth** (`enabled = false`). This is a safety measure — a blank key with auth enabled would lock out all clients.
- **Too long:** Keys exceeding 31 characters return `ConfigResult::TooLong` and auth is disabled.
- **Enable without keys:** Calling `e=1` when either key is empty returns `ConfigResult::InvalidParameter` — auth cannot be enabled until both keys are set.

---

## /api/index Auth Exposure

The `/api/index` response always includes the current auth configuration in its `config` section:

```json
{
  "config": {
    …
    "auth": {
      "enabled": true,
      "apiKey": "ak-pch-1712A0",
      "hmacKey": "hk-sfb-1712A0"
    }
  }
}
```

This is how the MAUI client discovers the device's auth keys on first connection. The flow:

1. User enters IP/port in the MAUI app (no auth keys known yet)
2. App calls `GET /api/index` — if auth is disabled, the response includes the keys
3. App reads the keys and stores them in local preferences
4. App calls `ConfigureAuth(apiKey, hmacKey)` on both `DashboardConnection` and `ConfigConnection`
5. Future requests carry auth headers

When auth is already enabled and the MAUI app has stored keys from a previous session, the app loads them from preferences at startup and configures the auth handler before the first request.

---

## Client-Side Implementation (.NET MAUI)

### DeviceAuthHandler

`DeviceAuthHandler` is a `DelegatingHandler` that sits in the `HttpClient` pipeline for both `DashboardConnection` and `ConfigConnection`. It intercepts every outbound request in `SendAsync()` and injects auth headers.

```csharp
// In SendAsync():
if (apiKey.Length > 0)
    request.Headers.TryAddWithoutValidation("X-API-Key", apiKey);

if (hmacKey.Length > 0)
{
    string timestamp = DateTimeOffset.UtcNow.ToUnixTimeSeconds().ToString();
    string signInput = $"{timestamp}\n{method}\n{path}\n{body}";
    byte[] hash = HMACSHA256(hmacKeyBytes, signInputBytes);
    string signature = BitConverter.ToString(hash).Replace("-", "").ToLowerInvariant();
    request.Headers.TryAddWithoutValidation("X-Auth-Timestamp", timestamp);
    request.Headers.TryAddWithoutValidation("X-Auth-Signature", signature);
}
```

Both mechanisms are applied simultaneously when both keys are configured. The server checks API key first (fast path), then falls back to HMAC.

Key design decisions in the handler:

- **Thread-safe state:** API key and HMAC key are stored behind a `lock` and can be updated at runtime via `Configure()` without disrupting in-flight requests.
- **Body buffering:** For POST requests, the handler reads and buffers the request body to compute the HMAC signature, then rewinds it with a `ByteArrayContent` so the inner handler can still read it. This is safe for the small payloads (typically <256 bytes) used by the MAUI app.
- **Streaming fallback:** If body buffering fails, the signature is computed with an empty body — the server will reject the HMAC, but API key auth may still succeed.

### Auth Sync Flow

When the MAUI app changes auth settings (enable/disable, set keys, generate keys), the `ConfigConnection` automatically re-syncs the handler:

```
SetAuthEnabledAsync() ──┐
SetAuthApiKeyAsync()  ──┼──► POST /api/config/C19
SetAuthHmacKeyAsync() ──┤          │
GenerateAuthKeysAsync()──┘          ▼
                         SyncAuthHandlerFromDeviceAsync()
                                    │
                         GET /api/config/C19
                                    │
                         _authHandler.Configure(apiKey, hmacKey)
                                    │
                         _messageBus.Publish(AuthConfigChanged)
                                    │
                         PowerHubService.OnAuthConfigChanged()
                                    │
                         dc.ConfigureAuth() + cc.ConfigureAuth()
```

This ensures that after any auth change, both the config connection (which made the change) and the dashboard connection (which polls `/api/index`) have the updated credentials. Without this sync, the config change would succeed but subsequent requests would fail with `401` because the handler still had the old keys.

### AuthConfigChanged Message

A fire-and-forget message published whenever the device's auth configuration changes:

```csharp
public record AuthConfigChanged(AuthConfigModel Config);
```

`PowerHubService` subscribes to this message and propagates the new credentials to both `DashboardConnection` and `ConfigConnection`. This decouples the config-layer auth change from the dashboard-layer credential update — the `ConfigPoller` doesn't need to know about auth internals.

---

## MAUI UI — NetworkSecurityPage

The `NetworkSecurityPage` (accessible from Settings) provides a UI for managing auth:

- **Enable/Disable toggle** — switch controlling `config.auth.enabled`
- **API Key entry** — text field for the API key
- **HMAC Key entry** — text field for the HMAC key
- **Generate New Keys** button — sends `g=1` to the device, then refreshes the displayed keys
- **Save All Settings** button — writes all three fields (enabled, API key, HMAC key) and saves to EEPROM

The page is backed by `NetworkSecurityViewModel` which calls `PowerHubService` methods:

| UI Action | Service Method | HTTP Call |
|---|---|---|
| Toggle enable | `SetAuthEnabledAsync(bool)` | `POST /api/config/C19?e=0\|1` |
| Save API key | `SetAuthApiKeyAsync(string)` | `POST /api/config/C19?k=…` |
| Save HMAC key | `SetAuthHmacKeyAsync(string)` | `POST /api/config/C19?h=…` |
| Generate keys | `GenerateAuthKeysAsync()` | `POST /api/config/C19?g=1` |
| Refresh | `GetAuthConfigAsync()` | `GET /api/config/C19` |

---

## Connection Lifecycle

### First Connection (auth disabled)

```
MAUI App                    ESP32 WiFi Server
   │                              │
   │── GET /api/index ───────────►│  auth disabled, no check
   │◄─ {config:{auth:{…}}} ──────│  leaks apiKey, hmacKey
   │                              │
   │  App stores keys in prefs    │
   │  ConfigureAuth(apiKey,hmacKey)
   │                              │
   │── GET /api/index ───────────►│  auth disabled, but headers sent anyway
   │  X-API-Key: ak-…             │
```

### Auth Enabled After Configuration

```
MAUI App                    ESP32 WiFi Server
   │                              │
   │── POST /api/config/C19?e=1 ─►│  enable auth
   │◄─ {"success":true} ─────────│
   │                              │
   │  SyncAuthHandlerFromDevice() │
   │  (re-reads keys, updates handler)
   │                              │
   │── GET /api/index ───────────►│  auth check: X-API-Key matches ✓
   │  X-API-Key: ak-…             │
   │◄─ 200 OK ───────────────────│
```

### Unauthorised Browser (auth enabled)

```
Browser                     ESP32 WiFi Server
   │                              │
   │── GET /api/index ───────────►│  auth check: no headers → not authorized
   │◄─ 401 {"message":"Unauthorized"}
   │                              │
```

---

## Security Considerations

| Concern | Mitigation |
|---|---|
| Plain-text HTTP | API key is sent in cleartext. Use HMAC mode for sensitive deployments. The connection is local WiFi only — not exposed to the internet unless the user explicitly port-forwards. |
| Replay attacks | HMAC timestamp window (±300 s) limits replay. Timestamp monotonicity is not enforced, so a captured signature can be replayed within the window. |
| Key exposure in `/api/index` | Keys are always present in the index JSON. When auth is enabled, reading `/api/index` requires a valid key — solving the chicken-and-egg problem for initial setup. Users should disable auth, read keys once, then enable auth. |
| Web UI breakage | The built-in HTML dashboard (`/index`) stops updating when auth is enabled because its JavaScript cannot send auth headers. This is by design. |
| EEPROM wear | Auth keys are stored in EEPROM as part of the `Config` struct. Frequent key regeneration should be avoided — keys are intended to be set once and rarely changed. |

---

## Migration from Pre-Auth Firmware

1. **Flash updated firmware** — auth defaults to disabled (`enabled == false`).
2. **Open NetworkSecurityPage** in the MAUI app and tap **Generate New Keys**.
3. Note the generated keys (they appear in the text fields).
4. Toggle **Enable Authentication** on.
5. Tap **Save All Settings**.
6. The MAUI app automatically syncs the new keys into its auth handler pipeline.
7. Verify by opening `http://<device-ip>/api/index` in a browser — you should receive `401 Unauthorized`.

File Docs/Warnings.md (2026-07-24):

# SmartFuseBox – Warning System

This document covers the warning system used across both the SmartFuseBox (SFB) and Boat Control Panel (BCP) controllers, including all warning types, the `WarningManager` API, propagation between devices, and how to add a new warning.

---

## Overview

The warning system tracks abnormal conditions across the entire system using a **32-bit bitmask**. Each bit represents a single named `WarningType`. Up to 32 independent warnings can be active simultaneously.

`WarningManager` separates warnings into two buckets:

| Bucket | Description |
|---|---|
| **Local** | Raised by the current device (`_localWarnings`) |
| **Remote** | Received from the connected peer via heartbeat or `W2` command (`_remoteWarnings`) |

`isWarningActive()` and `getActiveWarningsMask()` always return the **combined** view (local OR remote).  
`getLocalWarningsMask()` and `getRemoteWarningsMask()` return each bucket independently.

---

## Warning Type Reference

Bit ranges are reserved as follows:
- **Bits 0–19** — System warnings
- **Bits 20–31** — Sensor warnings (raising any of these also auto-raises `SensorFailure`)

| Bit | Hex Value | Constant | Display String | Raised by | Cleared by |
|---|---|---|---|---|---|
| 0 | `0x00000001` | `DefaultConfigurationFuseBox` | Fuse box Default Configuration | EEPROM config load fails at boot | Manually / successful config load |
| 1 | `0x00000002` | `DefaultConfigurationControlPanel` | Control Panel Default Configuration | BCP EEPROM config load fails at boot | Manually |
| 2 | `0x00000004` | `ConnectionLost` | Connection Lost To Fuse Box | No heartbeat ACK received within timeout (3000 ms) | Automatically on next `ACK:F0=ok` |
| 3 | `0x00000008` | `HighCompassTemperature` | High Compass Temperature | Compass module temperature exceeds threshold | Manually / when temperature falls |
| 4 | `0x00000010` | `LowBattery` | Low Battery | Battery voltage monitor | Manually |
| 5 | `0x00000020` | `BluetoothInitFailed` | Bluetooth Init Failed | BLE stack fails to initialise | Manually |
| 6 | `0x00000040` | `WifiInitFailed` | Wifi Init Failed | `WifiServer` creation fails | Manually |
| 7 | `0x00000080` | `WifiInvalidConfig` | Wifi Invalid Config | SSID empty or port is zero | Manually / on valid config applied |
| 8 | `0x00000100` | `WeakWifiSignal` | Weak Wifi Signal | RSSI drops below −70 dBm | Automatically when signal recovers |
| 9 | `0x00000200` | `SyncFailed` | Synchronization Failed | Config sync with BCP fails or times out | Automatically on next successful sync |
| 10 | `0x00000400` | `SpiPinConfigError` | SPI Pin Config Error | One or more required SPI pins (MISO/MOSI/SCK/CS) are set to `PinDisabled` (0xFF) when calling `MicroSdDriver::beginInitialize()` | Manually / on valid pin config applied |
| 11 | `0x00000800` | `SdCardError` | SD Card Error | SD card read/write error | Manually |
| 12 | `0x00001000` | `SdCardMissing` | SD Card Not Found | SD card not detected at initialisation | Automatically when card is inserted |
| 13 | `0x00002000` | `SdCardLowSpace` | SD Card Low Space | Free space falls below 10% | Automatically when space recovers |
| 14–19 | — | *(reserved)* | — | — | — |
| 20 | `0x00100000` | `SensorFailure` | Sensor Failure | **Auto-raised** when any sensor warning (bits 21–31) is raised | **Auto-cleared** when all sensor warnings are cleared |
| 21 | `0x00200000` | `TemperatureSensorFailure` | Temperature Sensor Failure | DHT11 returns a read error | Automatically on next successful DHT11 read |
| 22 | `0x00400000` | `CompassFailure` | Compass Failure | Compass module fails to initialise | Manually |
| 23 | `0x00800000` | `GpsFailure` | GPS Module Failure | No valid GPS fix received for 30 seconds | Automatically on next valid GPS fix |
| 24–31 | — | *(reserved)* | — | — | — |

---

## Automatic Behaviours

### SensorFailure Aggregation

Raising **any** sensor warning (bits 20–31) automatically raises `SensorFailure` (bit 20) if it is not already active. Clearing a sensor warning automatically clears `SensorFailure` **only** when no other sensor warnings remain. This means consumers can check `SensorFailure` as a single indicator that something is wrong with sensors, without polling every individual sensor flag.

### ConnectionLost

`WarningManager` manages the heartbeat internally. It sends an `F0` command at the configured interval (`HeartbeatIntervalMs` = 1000 ms) and raises `ConnectionLost` if no `ACK:F0=ok` is received within the timeout (`HeartbeatTimeoutMs` = 3000 ms). The warning clears automatically the moment a valid heartbeat ACK arrives.

On the BCP, when a connection is re-established after being lost, the current time is automatically re-synced to the SFB via `F6`.

---

## WarningManager API

```cpp
// Raise a warning (no-op if already active)
warningManager.raiseWarning(WarningType::WifiInvalidConfig);

// Clear a warning (no-op if not active)
warningManager.clearWarning(WarningType::WifiInvalidConfig);

// Clear all warnings (local and remote)
warningManager.clearAllWarnings();

// Check if any warnings are active (local or remote)
if (warningManager.hasWarnings())
{
}

// Check a specific warning (checks local AND remote)
if (warningManager.isWarningActive(WarningType::ConnectionLost))
{
}

// Get the full combined bitmask (local | remote)
uint32_t mask = warningManager.getActiveWarningsMask();

// Get masks separately
uint32_t local  = warningManager.getLocalWarningsMask();
uint32_t remote = warningManager.getRemoteWarningsMask();

// Called from the main loop — drives heartbeat and connection state
warningManager.update(SystemFunctions::millis64());

// Called from AckCommandHandler when ACK:F0=ok arrives
warningManager.notifyHeartbeatAck();

// Called from WarningCommandHandler when W2 arrives from the peer
warningManager.updateRemoteWarnings(remoteMask);
```

---

## Warning Propagation Between Devices

Warnings flow between SFB and BCP through two mechanisms:
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

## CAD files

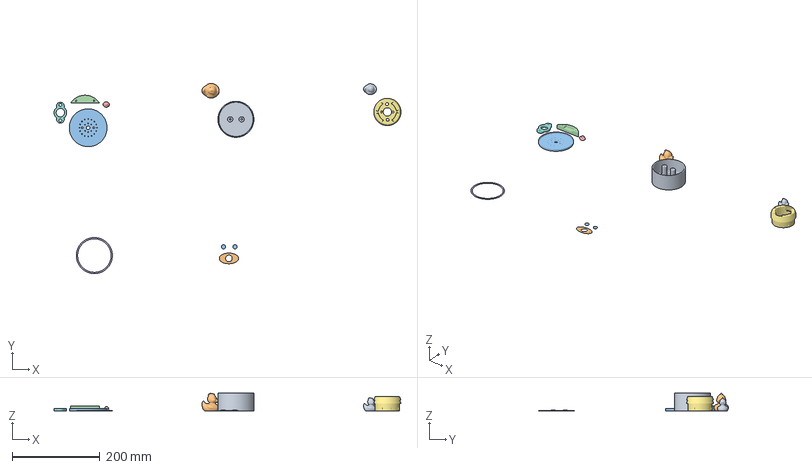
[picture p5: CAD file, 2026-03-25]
3mf/Boat Sensor Housing.3mf
789.8 x 433.1 x 40.0 mm
just a duck.stl x 3
Boat Sensor Housing GPS Base Plate.stl
Boat Sensor Housing GPS Grip.stl
Boat Sensor Housing GPS Seal.stl
Boat Sensor Housing GPS Base Pole.stl
Boat Sensor Housing GPS Underside Plate.stl
Boat Sensor Housing GPS Main Housing.stl
Boat Sensor Housing GPS Main Housing Cover 1.stl
Boat Sensor Housing GPS Main Housing Cover 2.stl

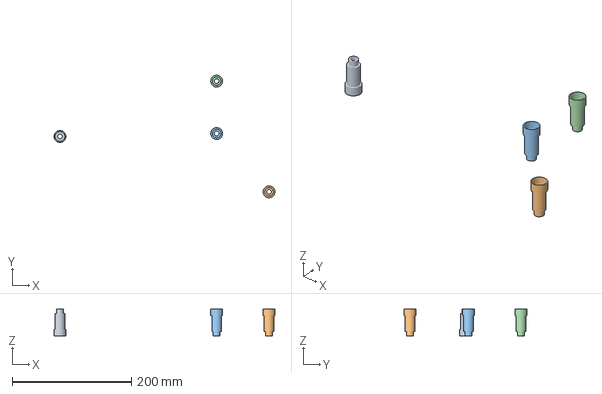
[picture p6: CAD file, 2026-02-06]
3mf/Aviation Connector Covers.3mf
371.2 x 206.0 x 45.0 mm
Boat Sensor Housing Aviation Cover.stl x 4

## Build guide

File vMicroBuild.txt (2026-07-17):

Ignoring source code that is included in the project but can not be located: C:\GitProjects\PowerControlHub\PowerControlHub\build_opt.h
Ignoring source code that is included in the project but can not be located: C:\GitProjects\PowerControlHub\PowerControlHub\build_opt.h
Ignoring source code that is included in the project but can not be located: C:\GitProjects\PowerControlHub\PowerControlHub\build_opt.h

Compiling debug version of 'PowerControlHub' for 'ESP32S3 Dev Module(esp32_esp32s3)'
Visual Studio Version: 2022 [18.0]
Build Folder: "file:///C:/Users/Simon/AppData/Local/Temp/VMBuilds/PowerControlHub/esp32_esp32s3/Debug"
Additional Defines: VM_DBT_HARDWARESERIAL 0;VM_DBT_SOFTWARESERIAL 1;VM_DBT_FASTSERIAL 2;VM_DBT_USB 3;VM_DBT_TEENSY 4;VM_DBT_UART 5;VM_DBT_USART 6;VM_DBT_USBSERIAL 7;VM_DBT_TTYUART 8;VM_DBT_NET_CONSOLE 9;VM_DBT_Uart 10;VM_DBT_COSA 11;VM_DBT_CDCSerialClass 12;VM_DBT_HARDWARESERIAL1 13;VM_DBT_HARDWARESERIAL2 14;VM_DBT_HARDWARESERIAL3 15;VM_DBT_NET_UDP 16;VM_DBT_USBAPI 17;VM_DBT_SERIALUSB 18;VM_DBT_MS430_SERIAL_ 19;VM_DBT_NO_SERIAL 20;VM_DBT_GENERIC_OBJECT 21;VM_DEBUG_ENABLE 1;VM_DEBUG;VM_DEBUGGER_SOFT_TRANSPORT Serial;VM_DEBUGGER_SOFT_TRANSPORT_WRITER Serial;VM_DBT VM_DBT_GENERIC_OBJECT;VM_DEBUG_BREAKPAUSE;
Architecture Tools: "file:///C://Users//Simon//AppData//Local//arduino15//packages//esp32//tools//esp-x32//2601/bin/"
Api: 2.2026.0422-1
Sketch Book: "file:///C:/Users/Simon/Documents/Arduino"
User Libraries: "file:///C:/Users/Simon/Documents/Arduino/libraries"
Build Temp: "file:///C:/Users/Simon/AppData/Local/Temp/VMBuilds/PowerControlHub/esp32_esp32s3/Debug"
Board Support Urls: ""
DefaultCodePage:                      1252
DefaultCharWidth:                     W
Encoding.Default.CodePage:            1252
Console.OutputEncoding.CodePage:      1252
Console.InputEncoding.CodePage:       1252
CurrentCulture TextInfo.ANSICodePage: 1252
CurrentCulture TextInfo.OEMCodePage:  850

Core Include Paths
Include Path "file:///C:/Users/Simon/AppData/Local/arduino15/packages/esp32/hardware/esp32/3.3.8/cores/esp32"
Include Path "file:///C:/Users/Simon/AppData/Local/arduino15/packages/esp32/hardware/esp32/3.3.8/variants/esp32s3"

# recipe.hooks.prebuild.0.pattern
Exec: C:\Users\Simon\AppData\Local\Temp\VMBuilds\PowerControlHub\esp32_esp32s3\Debug\.vm_sys\cmd_exec.bat
if exist "C:\Users\Simon\AppData\Local\Temp\VMBuilds\PowerControlHub\esp32_esp32s3\Debug\partitions.csv" del /f "C:\Users\Simon\AppData\Local\Temp\VMBuilds\PowerControlHub\esp32_esp32s3\Debug\partitions.csv"
"C:\Users\Simon\AppData\Local\Temp\VMBuilds\PowerControlHub\esp32_esp32s3\Debug\.vm_sys\cmd_exec.bat"
C:\Users\Simon\AppData\Local\Temp\VMBuilds\PowerControlHub\esp32_esp32s3\Debug>chcp 65001  1>NUL 2>NUL 
C:\Users\Simon\AppData\Local\Temp\VMBuilds\PowerControlHub\esp32_esp32s3\Debug>if exist "C:\Users\Simon\AppData\Local\Temp\VMBuilds\PowerControlHub\esp32_esp32s3\Debug\partitions.csv" del /f "C:\Users\Simon\AppData\Local\Temp\VMBuilds\PowerControlHub\esp32_esp32s3\Debug\partitions.csv" 

# recipe.hooks.prebuild.1.pattern
Exec: C:\Users\Simon\AppData\Local\Temp\VMBuilds\PowerControlHub\esp32_esp32s3\Debug\.vm_sys\cmd_exec.bat
if exist "C:\GitProjects\PowerControlHub\PowerControlHub\partitions.csv" COPY /y "C:\GitProjects\PowerControlHub\PowerControlHub\partitions.csv" "C:\Users\Simon\AppData\Local\Temp\VMBuilds\PowerControlHub\esp32_esp32s3\Debug\partitions.csv"
"C:\Users\Simon\AppData\Local\Temp\VMBuilds\PowerControlHub\esp32_esp32s3\Debug\.vm_sys\cmd_exec.bat"
C:\Users\Simon\AppData\Local\Temp\VMBuilds\PowerControlHub\esp32_esp32s3\Debug>chcp 65001  1>NUL 2>NUL 
C:\Users\Simon\AppData\Local\Temp\VMBuilds\PowerControlHub\esp32_esp32s3\Debug>if exist "C:\GitProjects\PowerControlHub\PowerControlHub\partitions.csv" COPY /y "C:\GitProjects\PowerControlHub\PowerControlHub\partitions.csv" "C:\Users\Simon\AppData\Local\Temp\VMBuilds\PowerControlHub\esp32_esp32s3\Debug\partitions.csv" 

# recipe.hooks.prebuild.2.pattern
Exec: C:\Users\Simon\AppData\Local\Temp\VMBuilds\PowerControlHub\esp32_esp32s3\Debug\.vm_sys\cmd_exec.bat
if not exist "C:\Users\Simon\AppData\Local\Temp\VMBuilds\PowerControlHub\esp32_esp32s3\Debug\partitions.csv" if exist "C:\Users\Simon\AppData\Local\arduino15\packages\esp32\hardware\esp32\3.3.8\variants\esp32s3\partitions.csv" COPY "C:\Users\Simon\AppData\Local\arduino15\packages\esp32\hardware\esp32\3.3.8\variants\esp32s3\partitions.csv" "C:\Users\Simon\AppData\Local\Temp\VMBuilds\PowerControlHub\esp32_esp32s3\Debug\partitions.csv"
"C:\Users\Simon\AppData\Local\Temp\VMBuilds\PowerControlHub\esp32_esp32s3\Debug\.vm_sys\cmd_exec.bat"
C:\Users\Simon\AppData\Local\Temp\VMBuilds\PowerControlHub\esp32_esp32s3\Debug>chcp 65001  1>NUL 2>NUL 
C:\Users\Simon\AppData\Local\Temp\VMBuilds\PowerControlHub\esp32_esp32s3\Debug>if not exist "C:\Users\Simon\AppData\Local\Temp\VMBuilds\PowerControlHub\esp32_esp32s3\Debug\partitions.csv" if exist "C:\Users\Simon\AppData\Local\arduino15\packages\esp32\hardware\esp32\3.3.8\variants\esp32s3\partitions.csv" COPY "C:\Users\Simon\AppData\Local\arduino15\packages\esp32\hardware\esp32\3.3.8\variants\esp32s3\partitions.csv" "C:\Users\Simon\AppData\Local\Temp\VMBuilds\PowerControlHub\esp32_esp32s3\Debug\partitions.csv" 

# recipe.hooks.prebuild.3.pattern
Exec: C:\Users\Simon\AppData\Local\Temp\VMBuilds\PowerControlHub\esp32_esp32s3\Debug\.vm_sys\cmd_exec.bat
if not exist "C:\Users\Simon\AppData\Local\Temp\VMBuilds\PowerControlHub\esp32_esp32s3\Debug\partitions.csv" COPY "C:\Users\Simon\AppData\Local\arduino15\packages\esp32\hardware\esp32\3.3.8\tools\partitions\min_spiffs.csv" "C:\Users\Simon\AppData\Local\Temp\VMBuilds\PowerControlHub\esp32_esp32s3\Debug\partitions.csv"
"C:\Users\Simon\AppData\Local\Temp\VMBuilds\PowerControlHub\esp32_esp32s3\Debug\.vm_sys\cmd_exec.bat"
C:\Users\Simon\AppData\Local\Temp\VMBuilds\PowerControlHub\esp32_esp32s3\Debug>chcp 65001  1>NUL 2>NUL 
C:\Users\Simon\AppData\Local\Temp\VMBuilds\PowerControlHub\esp32_esp32s3\Debug>if not exist "C:\Users\Simon\AppData\Local\Temp\VMBuilds\PowerControlHub\esp32_esp32s3\Debug\partitions.csv" COPY "C:\Users\Simon\AppData\Local\arduino15\packages\esp32\hardware\esp32\3.3.8\tools\partitions\min_spiffs.csv" "C:\Users\Simon\AppData\Local\Temp\VMBuilds\PowerControlHub\esp32_esp32s3\Debug\partitions.csv" 
        1 file(s) copied.

# recipe.hooks.prebuild.4.pattern
Exec: C:\Users\Simon\AppData\Local\Temp\VMBuilds\PowerControlHub\esp32_esp32s3\Debug\.vm_sys\cmd_exec.bat
IF EXIST "C:\GitProjects\PowerControlHub\PowerControlHub\bootloader.bin" ( COPY /y "C:\GitProjects\PowerControlHub\PowerControlHub\bootloader.bin" "C:\Users\Simon\AppData\Local\Temp\VMBuilds\PowerControlHub\esp32_esp32s3\Debug\PowerControlHub.ino.bootloader.bin" ) ELSE ( IF EXIST "C:\Users\Simon\AppData\Local\arduino15\packages\esp32\hardware\esp32\3.3.8\variants\esp32s3\bootloader.bin" ( COPY "C:\Users\Simon\AppData\Local\arduino15\packages\esp32\hardware\esp32\3.3.8\variants\esp32s3\bootloader.bin" "C:\Users\Simon\AppData\Local\Temp\VMBuilds\PowerControlHub\esp32_esp32s3\Debug\PowerControlHub.ino.bootloader.bin" ) ELSE ( "C:\Users\Simon\AppData\Local\arduino15\packages\esp32\tools\esptool_py\5.2.0\esptool.exe" --chip esp32s3 elf2image --flash-mode dio --flash-freq 80m --flash-size 4MB -o "C:\Users\Simon\AppData\Local\Temp\VMBuilds\PowerControlHub\esp32_esp32s3\Debug\PowerControlHub.ino.bootloader.bin" "C:\Users\Simon\AppData\Local\arduino15\packages\esp32\tools\esp32s3-libs\3.3.8\bin\bootloader_dio_80m.elf" ) )
"C:\Users\Simon\AppData\Local\Temp\VMBuilds\PowerControlHub\esp32_esp32s3\Debug\.vm_sys\cmd_exec.bat"
C:\Users\Simon\AppData\Local\Temp\VMBuilds\PowerControlHub\esp32_esp32s3\Debug>chcp 65001  1>NUL 2>NUL 
C:\Users\Simon\AppData\Local\Temp\VMBuilds\PowerControlHub\esp32_esp32s3\Debug>IF EXIST "C:\GitProjects\PowerControlHub\PowerControlHub\bootloader.bin" (COPY /y "C:\GitProjects\PowerControlHub\PowerControlHub\bootloader.bin" "C:\Users\Simon\AppData\Local\Temp\VMBuilds\PowerControlHub\esp32_esp32s3\Debug\PowerControlHub.ino.bootloader.bin"  )  ELSE (IF EXIST "C:\Users\Simon\AppData\Local\arduino15\packages\esp32\hardware\esp32\3.3.8\variants\esp32s3\bootloader.bin" (COPY "C:\Users\Simon\AppData\Local\arduino15\packages\esp32\hardware\esp32\3.3.8\variants\esp32s3\bootloader.bin" "C:\Users\Simon\AppData\Local\Temp\VMBuilds\PowerControlHub\esp32_esp32s3\Debug\PowerControlHub.ino.bootloader.bin"  )  ELSE ("C:\Users\Simon\AppData\Local\arduino15\packages\esp32\tools\esptool_py\5.2.0\esptool.exe" --chip esp32s3 elf2image --flash-mode dio --flash-freq 80m --flash-size 4MB -o "C:\Users\Simon\AppData\Local\Temp\VMBuilds\PowerControlHub\esp32_esp32s3\Debug\PowerControlHub.ino.bootloader.bin" "C:\Users\Simon\AppData\Local\arduino15\packages\esp32\tools\esp32s3-libs\3.3.8\bin\bootloader_dio_80m.elf"  ) ) 
esptool v5.2.0
Creating ESP32-S3 image...
Merged 2 ELF sections.
Successfully created ESP32-S3 image.

# recipe.hooks.prebuild.5.pattern
Exec: C:\Users\Simon\AppData\Local\Temp\VMBuilds\PowerControlHub\esp32_esp32s3\Debug\.vm_sys\cmd_exec.bat
if exist "C:\GitProjects\PowerControlHub\PowerControlHub\build_opt.h" COPY /y "C:\GitProjects\PowerControlHub\PowerControlHub\build_opt.h" "C:\Users\Simon\AppData\Local\Temp\VMBuilds\PowerControlHub\esp32_esp32s3\Debug\build_opt.h"
"C:\Users\Simon\AppData\Local\Temp\VMBuilds\PowerControlHub\esp32_esp32s3\Debug\.vm_sys\cmd_exec.bat"
C:\Users\Simon\AppData\Local\Temp\VMBuilds\PowerControlHub\esp32_esp32s3\Debug>chcp 65001  1>NUL 2>NUL 
C:\Users\Simon\AppData\Local\Temp\VMBuilds\PowerControlHub\esp32_esp32s3\Debug>if exist "C:\GitProjects\PowerControlHub\PowerControlHub\build_opt.h" COPY /y "C:\GitProjects\PowerControlHub\PowerControlHub\build_opt.h" "C:\Users\Simon\AppData\Local\Temp\VMBuilds\PowerControlHub\esp32_esp32s3\Debug\build_opt.h" 

# recipe.hooks.prebuild.6.pattern
Exec: C:\Users\Simon\AppData\Local\Temp\VMBuilds\PowerControlHub\esp32_esp32s3\Debug\.vm_sys\cmd_exec.bat
if not exist "C:\Users\Simon\AppData\Local\Temp\VMBuilds\PowerControlHub\esp32_esp32s3\Debug\build_opt.h" type nul > "C:\Users\Simon\AppData\Local\Temp\VMBuilds\PowerControlHub\esp32_esp32s3\Debug\build_opt.h"
"C:\Users\Simon\AppData\Local\Temp\VMBuilds\PowerControlHub\esp32_esp32s3\Debug\.vm_sys\cmd_exec.bat"
C:\Users\Simon\AppData\Local\Temp\VMBuilds\PowerControlHub\esp32_esp32s3\Debug>chcp 65001  1>NUL 2>NUL 
C:\Users\Simon\AppData\Local\Temp\VMBuilds\PowerControlHub\esp32_esp32s3\Debug>if not exist "C:\Users\Simon\AppData\Local\Temp\VMBuilds\PowerControlHub\esp32_esp32s3\Debug\build_opt.h" type nul  1>"C:\Users\Simon\AppData\Local\Temp\VMBuilds\PowerControlHub\esp32_esp32s3\Debug\build_opt.h" 

# recipe.hooks.prebuild.7.pattern
Exec: C:\Users\Simon\AppData\Local\Temp\VMBuilds\PowerControlHub\esp32_esp32s3\Debug\.vm_sys\cmd_exec.bat
type nul > "C:\Users\Simon\AppData\Local\Temp\VMBuilds\PowerControlHub\esp32_esp32s3\Debug/file_opts"
"C:\Users\Simon\AppData\Local\Temp\VMBuilds\PowerControlHub\esp32_esp32s3\Debug\.vm_sys\cmd_exec.bat"
C:\Users\Simon\AppData\Local\Temp\VMBuilds\PowerControlHub\esp32_esp32s3\Debug>chcp 65001  1>NUL 2>NUL 
C:\Users\Simon\AppData\Local\Temp\VMBuilds\PowerControlHub\esp32_esp32s3\Debug>type nul  1>"C:\Users\Simon\AppData\Local\Temp\VMBuilds\PowerControlHub\esp32_esp32s3\Debug/file_opts" 

# recipe.hooks.prebuild.8.pattern
Exec: C:\Users\Simon\AppData\Local\Temp\VMBuilds\PowerControlHub\esp32_esp32s3\Debug\.vm_sys\cmd_exec.bat
COPY /y "C:\Users\Simon\AppData\Local\arduino15\packages\esp32\tools\esp32s3-libs\3.3.8\sdkconfig" "C:\Users\Simon\AppData\Local\Temp\VMBuilds\PowerControlHub\esp32_esp32s3\Debug\sdkconfig"
"C:\Users\Simon\AppData\Local\Temp\VMBuilds\PowerControlHub\esp32_esp32s3\Debug\.vm_sys\cmd_exec.bat"
C:\Users\Simon\AppData\Local\Temp\VMBuilds\PowerControlHub\esp32_esp32s3\Debug>chcp 65001  1>NUL 2>NUL 
C:\Users\Simon\AppData\Local\Temp\VMBuilds\PowerControlHub\esp32_esp32s3\Debug>COPY /y "C:\Users\Simon\AppData\Local\arduino15\packages\esp32\tools\esp32s3-libs\3.3.8\sdkconfig" "C:\Users\Simon\AppData\Local\Temp\VMBuilds\PowerControlHub\esp32_esp32s3\Debug\sdkconfig" 
        1 file(s) copied.
		Pre-build discovered additional source: 'file:///C:\Users\Simon\AppData\Local\Temp\VMBuilds\PowerControlHub\esp32_esp32s3\Debug\build_opt.h'
 
Deep search for libraries ...
   Using previous search results: C:\Users\Simon\AppData\Local\Temp\VMBuilds\PowerControlHub\esp32_esp32s3\Debug\PowerControlHub.cpp
   Using previous search results: C:\Users\Simon\AppData\Local\Temp\VMBuilds\PowerControlHub\esp32_esp32s3\Debug\PowerControlHub.cpp
   Using previous search results: C:\Users\Simon\AppData\Local\Temp\VMBuilds\PowerControlHub\esp32_esp32s3\Debug\PowerControlHub.cpp
   Using previous search results: C:\Users\Simon\AppData\Local\Temp\VMBuilds\PowerControlHub\esp32_esp32s3\Debug\PowerControlHub.cpp
   Using previous search results: C:\Users\Simon\AppData\Local\Temp\VMBuilds\PowerControlHub\esp32_esp32s3\Debug\PowerControlHub.cpp
   Using previous search results: C:\Users\Simon\AppData\Local\Temp\VMBuilds\PowerControlHub\esp32_esp32s3\Debug\PowerControlHub.cpp
   Using previous search results: C:\Users\Simon\AppData\Local\Temp\VMBuilds\PowerControlHub\esp32_esp32s3\Debug\PowerControlHub.cpp
   Using previous search results: C:\Users\Simon\AppData\Local\Temp\VMBuilds\PowerControlHub\esp32_esp32s3\Debug\PowerControlHub.cpp
   Using previous search results: C:\Users\Simon\AppData\Local\Temp\VMBuilds\PowerControlHub\esp32_esp32s3\Debug\PowerControlHub.cpp
   Using previous search results: C:\Users\Simon\AppData\Local\Temp\VMBuilds\PowerControlHub\esp32_esp32s3\Debug\PowerControlHub.cpp
   Using previous search results: C:\Users\Simon\Documents\Arduino\libraries\SerialCommandManager\src\BaseCommandHandler.cpp
   Using previous search results: C:\Users\Simon\Documents\Arduino\libraries\SerialCommandManager\src\SerialCommandManager.cpp
   Using previous search results: C:\Users\Simon\Documents\Arduino\libraries\SdFat\src\FreeStack.cpp
   Using previous search results: C:\Users\Simon\Documents\Arduino\libraries\SdFat\src\MinimumSerial.cpp
   Using previous search results: C:\Users\Simon\Documents\Arduino\libraries\SdFat\src\common\FmtNumber.cpp
   Using previous search results: C:\Users\Simon\Documents\Arduino\libraries\SdFat\src\common\FsCache.cpp
   Using previous search results: C:\Users\Simon\Documents\Arduino\libraries\SdFat\src\common\FsDateTime.cpp
   Using previous search results: C:\Users\Simon\Documents\Arduino\libraries\SdFat\src\common\FsName.cpp
   Using previous search results: C:\Users\Simon\Documents\Arduino\libraries\SdFat\src\common\FsStructs.cpp
   Using previous search results: C:\Users\Simon\Documents\Arduino\libraries\SdFat\src\common\FsUtf.cpp
   Using previous search results: C:\Users\Simon\Documents\Arduino\libraries\SdFat\src\common\PrintBasic.cpp
   Using previous search results: C:\Users\Simon\Documents\Arduino\libraries\SdFat\src\common\upcase.cpp
   Using previous search results: C:\Users\Simon\Documents\Arduino\libraries\SdFat\src\ExFatLib\ExFatDbg.cpp
   Using previous search results: C:\Users\Simon\Documents\Arduino\libraries\SdFat\src\ExFatLib\ExFatFile.cpp
   Using previous search results: C:\Users\Simon\Documents\Arduino\libraries\SdFat\src\ExFatLib\ExFatFilePrint.cpp
   Using previous search results: C:\Users\Simon\Documents\Arduino\libraries\SdFat\src\ExFatLib\ExFatFileWrite.cpp
   Using previous search results: C:\Users\Simon\Documents\Arduino\libraries\SdFat\src\ExFatLib\ExFatFormatter.cpp
   Using previous search results: C:\Users\Simon\Documents\Arduino\libraries\SdFat\src\ExFatLib\ExFatName.cpp
   Using previous search results: C:\Users\Simon\Documents\Arduino\libraries\SdFat\src\ExFatLib\ExFatPartition.cpp
   Using previous search results: C:\Users\Simon\Documents\Arduino\libraries\SdFat\src\ExFatLib\ExFatVolume.cpp
   Using previous search results: C:\Users\Simon\Documents\Arduino\libraries\SdFat\src\FatLib\FatDbg.cpp
   Using previous search results: C:\Users\Simon\Documents\Arduino\libraries\SdFat\src\FatLib\FatFile.cpp
   Using previous search results: C:\Users\Simon\Documents\Arduino\libraries\SdFat\src\FatLib\FatFileLFN.cpp
   Using previous search results: C:\Users\Simon\Documents\Arduino\libraries\SdFat\src\FatLib\FatFilePrint.cpp
   Using previous search results: C:\Users\Simon\Documents\Arduino\libraries\SdFat\src\FatLib\FatFileSFN.cpp
   Using previous search results: C:\Users\Simon\Documents\Arduino\libraries\SdFat\src\FatLib\FatFormatter.cpp
   Using previous search results: C:\Users\Simon\Documents\Arduino\libraries\SdFat\src\FatLib\FatName.cpp
   Using previous search results: C:\Users\Simon\Documents\Arduino\libraries\SdFat\src\FatLib\FatPartition.cpp
   Using previous search results: C:\Users\Simon\Documents\Arduino\libraries\SdFat\src\FatLib\FatVolume.cpp
   Using previous search results: C:\Users\Simon\Documents\Arduino\libraries\SdFat\src\FsLib\FsFile.cpp
   Using previous search results: C:\Users\Simon\Documents\Arduino\libraries\SdFat\src\FsLib\FsNew.cpp
   Using previous search results: C:\Users\Simon\Documents\Arduino\libraries\SdFat\src\FsLib\FsVolume.cpp
   Using previous search results: C:\Users\Simon\Documents\Arduino\libraries\SdFat\src\iostream\istream.cpp
   Using previous search results: C:\Users\Simon\Documents\Arduino\libraries\SdFat\src\iostream\ostream.cpp
   Using previous search results: C:\Users\Simon\Documents\Arduino\libraries\SdFat\src\iostream\StdioStream.cpp
   Using previous search results: C:\Users\Simon\Documents\Arduino\libraries\SdFat\src\iostream\StreamBaseClass.cpp
   Using previous search results: C:\Users\Simon\Documents\Arduino\libraries\SdFat\src\SdCard\SdCardInfo.cpp
   Using previous search results: C:\Users\Simon\Documents\Arduino\libraries\SdFat\src\SdCard\SdSpiCard.cpp
   Using previous search results: C:\Users\Simon\Documents\Arduino\libraries\SdFat\src\SdCard\Rp2040Sdio\PioSdioCard.cpp
   Using previous search results: C:\Users\Simon\Documents\Arduino\libraries\SdFat\src\SdCard\TeensySdio\TeensySdio.cpp
   Using previous search results: C:\Users\Simon\Documents\Arduino\libraries\SdFat\src\SpiDriver\SdSpiArtemis.cpp
   Using previous search results: C:\Users\Simon\Documents\Arduino\libraries\SdFat\src\SpiDriver\SdSpiChipSelect.cpp
   Using previous search results: C:\Users\Simon\Documents\Arduino\libraries\SdFat\src\SpiDriver\SdSpiDue.cpp
   Using previous search results: C:\Users\Simon\Documents\Arduino\libraries\SdFat\src\SpiDriver\SdSpiParticle.cpp
   Using previous search results: C:\Users\Simon\Documents\Arduino\libraries\SdFat\src\SpiDriver\SdSpiSTM32.cpp
   Using previous search results: C:\Users\Simon\Documents\Arduino\libraries\SdFat\src\SpiDriver\SdSpiSTM32Core.cpp
   Using previous search results: C:\Users\Simon\Documents\Arduino\libraries\SdFat\src\SpiDriver\SdSpiTeensy3.cpp
   Using previous search results: C:\Users\Simon\AppData\Local\arduino15\packages\esp32\hardware\esp32\3.3.8\libraries\SPI\src\SPI.cpp
   Using previous search results: C:\Users\Simon\AppData\Local\arduino15\packages\esp32\hardware\esp32\3.3.8\libraries\WiFi\src\AP.cpp
   Using previous search results: C:\Users\Simon\AppData\Local\arduino15\packages\esp32\hardware\esp32\3.3.8\libraries\WiFi\src\STA.cpp
   Using previous search results: C:\Users\Simon\AppData\Local\arduino15\packages\esp32\hardware\esp32\3.3.8\libraries\WiFi\src\WiFi.cpp
   Using previous search results: C:\Users\Simon\AppData\Local\arduino15\packages\esp32\hardware\esp32\3.3.8\libraries\WiFi\src\WiFiAP.cpp
   Using previous search results: C:\Users\Simon\AppData\Local\arduino15\packages\esp32\hardware\esp32\3.3.8\libraries\WiFi\src\WiFiGeneric.cpp
   Using previous search results: C:\Users\Simon\AppData\Local\arduino15\packages\esp32\hardware\esp32\3.3.8\libraries\WiFi\src\WiFiMulti.cpp
   Using previous search results: C:\Users\Simon\AppData\Local\arduino15\packages\esp32\hardware\esp32\3.3.8\libraries\WiFi\src\WiFiScan.cpp
   Using previous search results: C:\Users\Simon\AppData\Local\arduino15\packages\esp32\hardware\esp32\3.3.8\libraries\WiFi\src\WiFiSTA.cpp
   Using previous search results: C:\Users\Simon\AppData\Local\arduino15\packages\esp32\hardware\esp32\3.3.8\libraries\Network\src\NetworkClient.cpp
   Using previous search results: C:\Users\Simon\AppData\Local\arduino15\packages\esp32\hardware\esp32\3.3.8\libraries\Network\src\NetworkEvents.cpp
   Using previous search results: C:\Users\Simon\AppData\Local\arduino15\packages\esp32\hardware\esp32\3.3.8\libraries\Network\src\NetworkInterface.cpp
   Using previous search results: C:\Users\Simon\AppData\Local\arduino15\packages\esp32\hardware\esp32\3.3.8\libraries\Network\src\NetworkManager.cpp
   Using previous search results: C:\Users\Simon\AppData\Local\arduino15\packages\esp32\hardware\esp32\3.3.8\libraries\Network\src\NetworkServer.cpp
   Using previous search results: C:\Users\Simon\AppData\Local\arduino15\packages\esp32\hardware\esp32\3.3.8\libraries\Network\src\NetworkUdp.cpp
   Using previous search results: C:\Users\Simon\Documents\Arduino\libraries\NextionControl\src\NextionControl.cpp
   Using previous search results: C:\Users\Simon\Documents\Arduino\libraries\TinyGPSPlus\src\TinyGPS++.cpp
   Using previous search results: C:\Users\Simon\AppData\Local\Temp\VMBuilds\PowerControlHub\esp32_esp32s3\Debug\AckCommandHandler.cpp
   Using previous search results: C:\Users\Simon\AppData\Local\Temp\VMBuilds\PowerControlHub\esp32_esp32s3\Debug\BaseNextionCommandHandler.cpp
   Using previous search results: C:\Users\Simon\AppData\Local\Temp\VMBuilds\PowerControlHub\esp32_esp32s3\Debug\BasePage.cpp
   Using previous search results: C:\Users\Simon\AppData\Local\Temp\VMBuilds\PowerControlHub\esp32_esp32s3\Debug\BinaryPresenceSensor.cpp
   Using previous search results: C:\Users\Simon\AppData\Local\Temp\VMBuilds\PowerControlHub\esp32_esp32s3\Debug\BluetoothManager.cpp
   Using previous search results: C:\Users\Simon\AppData\Local\Temp\VMBuilds\PowerControlHub\esp32_esp32s3\Debug\BluetoothRelayService.cpp
   Using previous search results: C:\Users\Simon\AppData\Local\Temp\VMBuilds\PowerControlHub\esp32_esp32s3\Debug\BluetoothSensorService.cpp
   Using previous search results: C:\Users\Simon\AppData\Local\Temp\VMBuilds\PowerControlHub\esp32_esp32s3\Debug\BluetoothSystemService.cpp
   Using previous search results: C:\Users\Simon\AppData\Local\Temp\VMBuilds\PowerControlHub\esp32_esp32s3\Debug\BroadcastManager.cpp
   Using previous search results: C:\Users\Simon\AppData\Local\Temp\VMBuilds\PowerControlHub\esp32_esp32s3\Debug\ConfigCommandHandler.cpp
   Using previous search results: C:\Users\Simon\AppData\Local\Temp\VMBuilds\PowerControlHub\esp32_esp32s3\Debug\ConfigController.cpp
   Using previous search results: C:\Users\Simon\AppData\Local\Temp\VMBuilds\PowerControlHub\esp32_esp32s3\Debug\ConfigManager.cpp
   Using previous search results: C:\Users\Simon\AppData\Local\Temp\VMBuilds\PowerControlHub\esp32_esp32s3\Debug\ConfigManager.cpp
   Using previous search results: C:\Users\Simon\AppData\Local\arduino15\packages\esp32\hardware\esp32\3.3.8\libraries\EEPROM\src\EEPROM.cpp
   Using previous search results: C:\Users\Simon\AppData\Local\Temp\VMBuilds\PowerControlHub\esp32_esp32s3\Debug\ConfigNetworkHandler.cpp
   Using previous search results: C:\Users\Simon\AppData\Local\Temp\VMBuilds\PowerControlHub\esp32_esp32s3\Debug\DateTimeManager.cpp
   Using previous search results: C:\Users\Simon\AppData\Local\Temp\VMBuilds\PowerControlHub\esp32_esp32s3\Debug\ExternalSensorNetworkHandler.cpp
   Using previous search results: C:\Users\Simon\AppData\Local\Temp\VMBuilds\PowerControlHub\esp32_esp32s3\Debug\LedMatrixManager.cpp
   Using previous search results: C:\Users\Simon\AppData\Local\Temp\VMBuilds\PowerControlHub\esp32_esp32s3\Debug\MicroSdDriver.cpp
   Using previous search results: C:\Users\Simon\AppData\Local\Temp\VMBuilds\PowerControlHub\esp32_esp32s3\Debug\MQTTClient.cpp
   Using previous search results: C:\Users\Simon\AppData\Local\Temp\VMBuilds\PowerControlHub\esp32_esp32s3\Debug\MQTTConfigCommandHandler.cpp
   Using previous search results: C:\Users\Simon\AppData\Local\Temp\VMBuilds\PowerControlHub\esp32_esp32s3\Debug\MQTTController.cpp
   Using previous search results: C:\Users\Simon\AppData\Local\Temp\VMBuilds\PowerControlHub\esp32_esp32s3\Debug\MQTTHandler.cpp
   Using previous search results: C:\Users\Simon\AppData\Local\Temp\VMBuilds\PowerControlHub\esp32_esp32s3\Debug\MQTTRelayHandler.cpp
   Using previous search results: C:\Users\Simon\AppData\Local\Temp\VMBuilds\PowerControlHub\esp32_esp32s3\Debug\MQTTSensorHandler.cpp
   Using previous search results: C:\Users\Simon\AppData\Local\Temp\VMBuilds\PowerControlHub\esp32_esp32s3\Debug\MQTTSystemHandler.cpp
   Using previous search results: C:\Users\Simon\AppData\Local\Temp\VMBuilds\PowerControlHub\esp32_esp32s3\Debug\NavigationController.cpp
   Using previous search results: C:\Users\Simon\AppData\Local\Temp\VMBuilds\PowerControlHub\esp32_esp32s3\Debug\OtaManager.cpp
   Using previous search results: C:\Users\Simon\AppData\Local\Temp\VMBuilds\PowerControlHub\esp32_esp32s3\Debug\OtaManager.cpp
   Using previous search results: C:\Users\Simon\AppData\Local\Temp\VMBuilds\PowerControlHub\esp32_esp32s3\Debug\OtaManager.cpp
   Using previous search results: C:\Users\Simon\AppData\Local\Temp\VMBuilds\PowerControlHub\esp32_esp32s3\Debug\OtaManager.cpp
   Using previous search results: C:\Users\Simon\AppData\Local\arduino15\packages\esp32\hardware\esp32\3.3.8\libraries\HTTPClient\src\HTTPClient.cpp
   Using previous search results: C:\Users\Simon\AppData\Local\arduino15\packages\esp32\hardware\esp32\3.3.8\libraries\NetworkClientSecure\src\NetworkClientSecure.cpp
   Using previous search results: C:\Users\Simon\AppData\Local\arduino15\packages\esp32\hardware\esp32\3.3.8\libraries\NetworkClientSecure\src\ssl_client.cpp
   Using previous search results: C:\Users\Simon\AppData\Local\arduino15\packages\esp32\hardware\esp32\3.3.8\libraries\Update\src\HttpsOTAUpdate.cpp
   Using previous search results: C:\Users\Simon\AppData\Local\arduino15\packages\esp32\hardware\esp32\3.3.8\libraries\Update\src\Updater.cpp
   Using previous search results: C:\Users\Simon\AppData\Local\arduino15\packages\esp32\hardware\esp32\3.3.8\libraries\Update\src\Updater_Signing.cpp
   Using previous search results: C:\Users\Simon\AppData\Local\Temp\VMBuilds\PowerControlHub\esp32_esp32s3\Debug\PageAbout.cpp
   Using previous search results: C:\Users\Simon\AppData\Local\Temp\VMBuilds\PowerControlHub\esp32_esp32s3\Debug\PageBuoys.cpp
   Using previous search results: C:\Users\Simon\AppData\Local\Temp\VMBuilds\PowerControlHub\esp32_esp32s3\Debug\PageCardinalMarkers.cpp
   Using previous search results: C:\Users\Simon\AppData\Local\Temp\VMBuilds\PowerControlHub\esp32_esp32s3\Debug\PageEnvironment.cpp
   Using previous search results: C:\Users\Simon\AppData\Local\Temp\VMBuilds\PowerControlHub\esp32_esp32s3\Debug\PageFlags.cpp
   Using previous search results: C:\Users\Simon\AppData\Local\Temp\VMBuilds\PowerControlHub\esp32_esp32s3\Debug\PageHome.cpp
   Using previous search results: C:\Users\Simon\AppData\Local\Temp\VMBuilds\PowerControlHub\esp32_esp32s3\Debug\PageMoonPhase.cpp
   Using previous search results: C:\Users\Simon\AppData\Local\Temp\VMBuilds\PowerControlHub\esp32_esp32s3\Debug\PageRelay.cpp
   Using previous search results: C:\Users\Simon\AppData\Local\Temp\VMBuilds\PowerControlHub\esp32_esp32s3\Debug\PageRelaySettings.cpp
   Using previous search results: C:\Users\Simon\AppData\Local\Temp\VMBuilds\PowerControlHub\esp32_esp32s3\Debug\PageSettings.cpp
   Using previous search results: C:\Users\Simon\AppData\Local\Temp\VMBuilds\PowerControlHub\esp32_esp32s3\Debug\PageSoundEmergency.cpp
   Using previous search results: C:\Users\Simon\AppData\Local\Temp\VMBuilds\PowerControlHub\esp32_esp32s3\Debug\PageSoundFog.cpp
   Using previous search results: C:\Users\Simon\AppData\Local\Temp\VMBuilds\PowerControlHub\esp32_esp32s3\Debug\PageSoundManeuvering.cpp
   Using previous search results: C:\Users\Simon\AppData\Local\Temp\VMBuilds\PowerControlHub\esp32_esp32s3\Debug\PageSoundOther.cpp
   Using previous search results: C:\Users\Simon\AppData\Local\Temp\VMBuilds\PowerControlHub\esp32_esp32s3\Debug\PageSoundOvertaking.cpp
   Using previous search results: C:\Users\Simon\AppData\Local\Temp\VMBuilds\PowerControlHub\esp32_esp32s3\Debug\PageSoundSignals.cpp
   Using previous search results: C:\Users\Simon\AppData\Local\Temp\VMBuilds\PowerControlHub\esp32_esp32s3\Debug\PageSystem.cpp
   Using previous search results: C:\Users\Simon\AppData\Local\Temp\VMBuilds\PowerControlHub\esp32_esp32s3\Debug\PageVhfChannels.cpp
   Using previous search results: C:\Users\Simon\AppData\Local\Temp\VMBuilds\PowerControlHub\esp32_esp32s3\Debug\PageVhfDistress.cpp
   Using previous search results: C:\Users\Simon\AppData\Local\Temp\VMBuilds\PowerControlHub\esp32_esp32s3\Debug\PageVhfRadio.cpp
   Using previous search results: C:\Users\Simon\AppData\Local\Temp\VMBuilds\PowerControlHub\esp32_esp32s3\Debug\PageWarning.cpp
   Using previous search results: C:\Users\Simon\AppData\Local\Temp\VMBuilds\PowerControlHub\esp32_esp32s3\Debug\Phonetic.cpp
   Using previous search results: C:\Users\Simon\AppData\Local\Temp\VMBuilds\PowerControlHub\esp32_esp32s3\Debug\PowerControlHubApp.cpp
   Using previous search results: C:\Users\Simon\AppData\Local\Temp\VMBuilds\PowerControlHub\esp32_esp32s3\Debug\RelayCommandHandler.cpp
   Using previous search results: C:\Users\Simon\AppData\Local\Temp\VMBuilds\PowerControlHub\esp32_esp32s3\Debug\RelayNetworkHandler.cpp
   Using previous search results: C:\Users\Simon\AppData\Local\Temp\VMBuilds\PowerControlHub\esp32_esp32s3\Debug\RtcDS1302Driver.cpp
   Using previous search results: C:\Users\Simon\AppData\Local\Temp\VMBuilds\PowerControlHub\esp32_esp32s3\Debug\RtcDS1302Driver.cpp
   Using previous search results: C:\Users\Simon\Documents\Arduino\libraries\Ds1302\src\Ds1302.cpp
   Using previous search results: C:\Users\Simon\AppData\Local\Temp\VMBuilds\PowerControlHub\esp32_esp32s3\Debug\ScheduleController.cpp
   Using previous search results: C:\Users\Simon\AppData\Local\Temp\VMBuilds\PowerControlHub\esp32_esp32s3\Debug\SchedulerCommandHandler.cpp
   Using previous search results: C:\Users\Simon\AppData\Local\Temp\VMBuilds\PowerControlHub\esp32_esp32s3\Debug\SchedulerNetworkHandler.cpp
   Using previous search results: C:\Users\Simon\AppData\Local\Temp\VMBuilds\PowerControlHub\esp32_esp32s3\Debug\SDCardConfigLoader.cpp
   Using previous search results: C:\Users\Simon\AppData\Local\Temp\VMBuilds\PowerControlHub\esp32_esp32s3\Debug\SdCardLogger.cpp
   Using previous search results: C:\Users\Simon\AppData\Local\Temp\VMBuilds\PowerControlHub\esp32_esp32s3\Debug\SensorCommandHandler.cpp
   Using previous search results: C:\Users\Simon\AppData\Local\Temp\VMBuilds\PowerControlHub\esp32_esp32s3\Debug\SensorNetworkHandler.cpp
   Using previous search results: C:\Users\Simon\AppData\Local\Temp\VMBuilds\PowerControlHub\esp32_esp32s3\Debug\SoundCommandHandler.cpp
   Using previous search results: C:\Users\Simon\AppData\Local\Temp\VMBuilds\PowerControlHub\esp32_esp32s3\Debug\SoundController.cpp
   Using previous search results: C:\Users\Simon\AppData\Local\Temp\VMBuilds\PowerControlHub\esp32_esp32s3\Debug\SoundNetworkHandler.cpp
   Using previous search results: C:\Users\Simon\AppData\Local\Temp\VMBuilds\PowerControlHub\esp32_esp32s3\Debug\SunCalculator.cpp
   Using previous search results: C:\Users\Simon\AppData\Local\Temp\VMBuilds\PowerControlHub\esp32_esp32s3\Debug\SystemCommandHandler.cpp
   Using previous search results: C:\Users\Simon\AppData\Local\Temp\VMBuilds\PowerControlHub\esp32_esp32s3\Debug\SystemCpuMonitor.cpp
   Using previous search results: C:\Users\Simon\AppData\Local\Temp\VMBuilds\PowerControlHub\esp32_esp32s3\Debug\SystemFunctions.cpp
   Using previous search results: C:\Users\Simon\AppData\Local\Temp\VMBuilds\PowerControlHub\esp32_esp32s3\Debug\SystemNetworkHandler.cpp
   Using previous search results: C:\Users\Simon\AppData\Local\Temp\VMBuilds\PowerControlHub\esp32_esp32s3\Debug\ToneManager.cpp
   Using previous search results: C:\Users\Simon\AppData\Local\Temp\VMBuilds\PowerControlHub\esp32_esp32s3\Debug\WarningCommandHandler.cpp
   Using previous search results: C:\Users\Simon\AppData\Local\Temp\VMBuilds\PowerControlHub\esp32_esp32s3\Debug\WarningManager.cpp
   Using previous search results: C:\Users\Simon\AppData\Local\Temp\VMBuilds\PowerControlHub\esp32_esp32s3\Debug\WarningNetworkHandler.cpp
   Using previous search results: C:\Users\Simon\AppData\Local\Temp\VMBuilds\PowerControlHub\esp32_esp32s3\Debug\WifiCommandBridge.cpp
   Using previous search results: C:\Users\Simon\AppData\Local\Temp\VMBuilds\PowerControlHub\esp32_esp32s3\Debug\WifiServer.cpp

Extracting .ino prototypes ...
"c:\program files\microsoft visual studio\18\insiders\common7\ide\extensions\hti01q5k.0wk\Micro Platforms\visualmicro\tools\ctags/ctags" -u --language-force=c++ -f - --c++-kinds=svpf --fields=KSTtzns --line-directives "C:\Users\Simon\AppData\Local\Temp\VMBuilds\PowerControlHub\esp32_esp32s3\Debug/.vmpreproc/sketch-gcc-e-clean.cpp.filtered.cpp"
onComputerCommandReceived	C:\Users\Simon\AppData\Local\Temp\VMBuilds\PowerControlHub\esp32_esp32s3\Debug/.vmpreproc/C:\GitProjects\PowerControlHub\PowerControlHub\PowerControlHub.ino	/^void onComputerCommandReceived(SerialCommandManager* mgr);$/;"	kind:prototype	line:36	signature:(SerialCommandManager* mgr)	returntype:void
commandMgrComputer	C:\Users\Simon\AppData\Local\Temp\VMBuilds\PowerControlHub\esp32_esp32s3\Debug/.vmpreproc/C:\GitProjects\PowerControlHub\PowerControlHub\PowerControlHub.ino	/^SerialCommandManager commandMgrComputer(&Serial0, onComputerCommandReceived, '\n', ':', ';', '=', 500, 64);$/;"	kind:variable	line:48
commandMgrComputer	C:\Users\Simon\AppData\Local\Temp\VMBuilds\PowerControlHub\esp32_esp32s3\Debug/.vmpreproc/C:\GitProjects\PowerControlHub\PowerControlHub\PowerControlHub.ino	/^PowerControlHubApp app(&commandMgrComputer);$/;"	kind:variable	line:50
setup	C:\Users\Simon\AppData\Local\Temp\VMBuilds\PowerControlHub\esp32_esp32s3\Debug/.vmpreproc/C:\GitProjects\PowerControlHub\PowerControlHub\PowerControlHub.ino	/^void setup(){ MicroDebug.init(3000); MicroDebug.begin(115200);if (MicroDebug.outPacketStart(true)) {Serial0.print("VMDPV_1|1_VMDPV\n");MicroDebug.DBG_YieldAndWait(10);MicroDebug.outPacketEnd();} MicroDebug.start(false,true);if (MicroDebug.outPacketStart(true)) {Serial0.print("VMDPR_");MicroDebug.outPacketEnd();}$/;"	kind:function	line:52	signature:()	returntype:void
loop	C:\Users\Simon\AppData\Local\Temp\VMBuilds\PowerControlHub\esp32_esp32s3\Debug/.vmpreproc/C:\GitProjects\PowerControlHub\PowerControlHub\PowerControlHub.ino	/^void loop(){$/;"	kind:function	line:64	signature:()	returntype:void
onComputerCommandReceived	C:\Users\Simon\AppData\Local\Temp\VMBuilds\PowerControlHub\esp32_esp32s3\Debug/.vmpreproc/C:\GitProjects\PowerControlHub\PowerControlHub\PowerControlHub.ino	/^void onComputerCommandReceived(SerialCommandManager* mgr)$/;"	kind:function	line:72	signature:(SerialCommandManager* mgr)	returntype:void

	Required: False, Prototype: void onComputerCommandReceived(SerialCommandManager* mgr);, Function: onComputerCommandReceived, Kind: prototype, Line: 36, Signature: (SerialCommandManager* mgr),  File: C:\GitProjects\PowerControlHub\PowerControlHub\PowerControlHub.ino, Code: void onComputerCommandReceived(SerialCommandManager* mgr); 
	Required: False, Prototype:  commandMgrComputer;, Function: commandMgrComputer, Kind: variable, Line: 48, Signature: ,  File: C:\GitProjects\PowerControlHub\PowerControlHub\PowerControlHub.ino, Code: SerialCommandManager commandMgrComputer(&Serial0, onComputerCommandReceived, '\n', ':', ';', '=', 500, 64); 
	Required: False, Prototype:  commandMgrComputer;, Function: commandMgrComputer, Kind: variable, Line: 50, Signature: ,  File: C:\GitProjects\PowerControlHub\PowerControlHub\PowerControlHub.ino, Code: PowerControlHubApp app(&commandMgrComputer); 
	Required: True, Prototype: void setup();, Function: setup, Kind: function, Line: 52, Signature: (),  File: C:\GitProjects\PowerControlHub\PowerControlHub\PowerControlHub.ino, Code: void setup(){ MicroDebug.init(3000); MicroDebug.begin(115200);if (MicroDebug.outPacketStart(true)) {Serial0.print("VMDPV_1|1_VMDPV\n");MicroDebug.DBG_YieldAndWait(10);MicroDebug.outPacketEnd();} MicroDebug.start(false,true);if (MicroDebug.outPacketStart(true)) {Serial0.print("VMDPR_");MicroDebug.outPacketEnd();} 
	Required: True, Prototype: void loop();, Function: loop, Kind: function, Line: 64, Signature: (),  File: C:\GitProjects\PowerControlHub\PowerControlHub\PowerControlHub.ino, Code: void loop(){ 
	Required: False, Prototype: void onComputerCommandReceived(SerialCommandManager* mgr);, Function: onComputerCommandReceived, Kind: function, Line: 72, Signature: (SerialCommandManager* mgr),  File: C:\GitProjects\PowerControlHub\PowerControlHub\PowerControlHub.ino, Code: void onComputerCommandReceived(SerialCommandManager* mgr) 

    # Warning: This core uses references to a current project folder. The shared core cache will accumlate once for each project. 
    # Tip: Periodically clear redundant cores by using 'Build>Clean Solution' to clear all shared cores from cache.

# recipe.hooks.core.prebuild.1.pattern
Exec: C:\Users\Simon\AppData\Local\Temp\VMBuilds\PowerControlHub\esp32_esp32s3\Debug\.vm_sys\cmd_exec.bat
echo "-DARDUINO_CORE_BUILD" > "C:\Users\Simon\AppData\Local\Temp\VMBuilds\PowerControlHub\esp32_esp32s3\Debug/file_opts"
"C:\Users\Simon\AppData\Local\Temp\VMBuilds\PowerControlHub\esp32_esp32s3\Debug\.vm_sys\cmd_exec.bat"
C:\Users\Simon\AppData\Local\Temp\VMBuilds\PowerControlHub\esp32_esp32s3\Debug>chcp 65001  1>NUL 2>NUL 
C:\Users\Simon\AppData\Local\Temp\VMBuilds\PowerControlHub\esp32_esp32s3\Debug>echo "-DARDUINO_CORE_BUILD"  1>"C:\Users\Simon\AppData\Local\Temp\VMBuilds\PowerControlHub\esp32_esp32s3\Debug/file_opts" 
 
Building variant ...
  Using previously compiled variant
 
Building core ...

# recipe.hooks.core.postbuild.1.pattern
Exec: C:\Users\Simon\AppData\Local\Temp\VMBuilds\PowerControlHub\esp32_esp32s3\Debug\.vm_sys\cmd_exec.bat
type nul > "C:\Users\Simon\AppData\Local\Temp\VMBuilds\PowerControlHub\esp32_esp32s3\Debug/file_opts"
"C:\Users\Simon\AppData\Local\Temp\VMBuilds\PowerControlHub\esp32_esp32s3\Debug\.vm_sys\cmd_exec.bat"
C:\Users\Simon\AppData\Local\Temp\VMBuilds\PowerControlHub\esp32_esp32s3\Debug>chcp 65001  1>NUL 2>NUL 
C:\Users\Simon\AppData\Local\Temp\VMBuilds\PowerControlHub\esp32_esp32s3\Debug>type nul  1>"C:\Users\Simon\AppData\Local\Temp\VMBuilds\PowerControlHub\esp32_esp32s3\Debug/file_opts" 
 
Building libraries ...
"C:\Users\Simon\AppData\Local\arduino15\packages\esp32\tools\esp-x32\2601/bin/xtensa-esp32s3-elf-g++" -MMD -c "@C:\Users\Simon\AppData\Local\arduino15\packages\esp32\tools\esp32s3-libs\3.3.8/flags/cpp_flags" -w -Os -Werror=return-type -DF_CPU=240000000L -DARDUINO=108010 -DARDUINO_ESP32S3_DEV -DARDUINO_ARCH_ESP32 "-DARDUINO_BOARD=\"ESP32S3_DEV\"" "-DARDUINO_VARIANT=\"esp32s3\"" -DARDUINO_PARTITION_min_spiffs "-DARDUINO_HOST_OS=\"windows\"" "-DARDUINO_FQBN=\"esp32:esp32:esp32s3:UploadSpeed=921600,USBMode=hwcdc,CDCOnBoot=default,MSCOnBoot=default,DFUOnBoot=default,UploadMode=default,CPUFreq=240,FlashMode=qio,FlashSize=4M,PartitionScheme=min_spiffs,DebugLevel=none,PSRAM=disabled,LoopCore=1,EventsCore=1,EraseFlash=none,JTAGAdapter=default,ZigbeeMode=default\"" -DESP32=ESP32 -DCORE_DEBUG_LEVEL=0 -DARDUINO_RUNNING_CORE=1 -DARDUINO_EVENT_RUNNING_CORE=1 -DARDUINO_USB_MODE=1 -DARDUINO_USB_CDC_ON_BOOT=0 -DARDUINO_USB_MSC_ON_BOOT=0 -DARDUINO_USB_DFU_ON_BOOT=0 "@C:\Users\Simon\AppData\Local\arduino15\packages\esp32\tools\esp32s3-libs\3.3.8/flags/defines" "-IC:\GitProjects\PowerControlHub\PowerControlHub" -iprefix "C:\Users\Simon\AppData\Local\arduino15\packages\esp32\tools\esp32s3-libs\3.3.8/include/" "@C:\Users\Simon\AppData\Local\arduino15\packages\esp32\tools\esp32s3-libs\3.3.8/flags/includes" "-IC:\Users\Simon\AppData\Local\arduino15\packages\esp32\tools\esp32s3-libs\3.3.8/dio_qspi/include" -I"C:\Users\Simon\AppData\Local\arduino15\packages\esp32\hardware\esp32\3.3.8\cores\esp32" -I"C:\Users\Simon\AppData\Local\arduino15\packages\esp32\hardware\esp32\3.3.8\variants\esp32s3" -I"C:\ProgramData\vMicro\SerialDebug\VM_DBG" -I"C:\Users\Simon\Documents\Arduino\libraries\SerialCommandManager\src" -I"C:\Users\Simon\Documents\Arduino\libraries\SensorManager\src" -I"C:\Users\Simon\Documents\Arduino\libraries\SdFat\src" -I"C:\Users\Simon\AppData\Local\arduino15\packages\esp32\hardware\esp32\3.3.8\libraries\SPI\src" -I"C:\Users\Simon\AppData\Local\arduino15\packages\esp32\hardware\esp32\3.3.8\libraries\WiFi\src" -I"C:\Users\Simon\AppData\Local\arduino15\packages\esp32\hardware\esp32\3.3.8\libraries\Network\src" -I"C:\Users\Simon\Documents\Arduino\libraries\NextionControl\src" -I"C:\Users\Simon\Documents\Arduino\libraries\TinyGPSPlus\src" -I"C:\Users\Simon\AppData\Local\arduino15\packages\esp32\hardware\esp32\3.3.8\libraries\EEPROM\src" -I"C:\Users\Simon\AppData\Local\arduino15\packages\esp32\hardware\esp32\3.3.8\libraries\HTTPClient\src" -I"C:\Users\Simon\AppData\Local\arduino15\packages\esp32\hardware\esp32\3.3.8\libraries\NetworkClientSecure\src" -I"C:\Users\Simon\AppData\Local\arduino15\packages\esp32\hardware\esp32\3.3.8\libraries\Update\src"  -Wall -Wextra -DVM_DEBUG_BREAKPAUSE -DVM_DBT=VM_DBT_GENERIC_OBJECT -DVM_DEBUGGER_SOFT_TRANSPORT_WRITER=Serial -DVM_DEBUGGER_SOFT_TRANSPORT=Serial -DVM_DEBUG -DVM_DEBUG_ENABLE=1 -DVM_DBT_GENERIC_OBJECT=21 -DVM_DBT_NO_SERIAL=20 -DVM_DBT_MS430_SERIAL_=19 -DVM_DBT_SERIALUSB=18 -DVM_DBT_USBAPI=17 -DVM_DBT_NET_UDP=16 -DVM_DBT_HARDWARESERIAL3=15 -DVM_DBT_HARDWARESERIAL2=14 -DVM_DBT_HARDWARESERIAL1=13 -DVM_DBT_CDCSerialClass=12 -DVM_DBT_COSA=11 -DVM_DBT_Uart=10 -DVM_DBT_NET_CONSOLE=9 -DVM_DBT_TTYUART=8 -DVM_DBT_USBSERIAL=7 -DVM_DBT_USART=6 -DVM_DBT_UART=5 -DVM_DBT_TEENSY=4 -DVM_DBT_USB=3 -DVM_DBT_FASTSERIAL=2 -DVM_DBT_SOFTWARESERIAL=1 -DVM_DBT_HARDWARESERIAL=0 -I"C:\Users\Simon\Documents\Arduino\libraries\Ds1302\src" "@C:\Users\Simon\AppData\Local\Temp\VMBuilds\PowerControlHub\esp32_esp32s3\Debug/build_opt.h" "@C:\Users\Simon\AppData\Local\Temp\VMBuilds\PowerControlHub\esp32_esp32s3\Debug/file_opts" "C:\ProgramData\vMicro\SerialDebug\VM_DBG\VM_DBG.cpp" -o "C:\Users\Simon\AppData\Local\Temp\VMBuilds\PowerControlHub\esp32_esp32s3\Debug\VM_DBG\VM_DBG.cpp.o"
"C:\Users\Simon\AppData\Local\arduino15\packages\esp32\tools\esp-x32\2601/bin/xtensa-esp32s3-elf-g++" -MMD -c "@C:\Users\Simon\AppData\Local\arduino15\packages\esp32\tools\esp32s3-libs\3.3.8/flags/cpp_flags" -w -Os -Werror=return-type -DF_CPU=240000000L -DARDUINO=108010 -DARDUINO_ESP32S3_DEV -DARDUINO_ARCH_ESP32 "-DARDUINO_BOARD=\"ESP32S3_DEV\"" "-DARDUINO_VARIANT=\"esp32s3\"" -DARDUINO_PARTITION_min_spiffs "-DARDUINO_HOST_OS=\"windows\"" "-DARDUINO_FQBN=\"esp32:esp32:esp32s3:UploadSpeed=921600,USBMode=hwcdc,CDCOnBoot=default,MSCOnBoot=default,DFUOnBoot=default,UploadMode=default,CPUFreq=240,FlashMode=qio,FlashSize=4M,PartitionScheme=min_spiffs,DebugLevel=none,PSRAM=disabled,LoopCore=1,EventsCore=1,EraseFlash=none,JTAGAdapter=default,ZigbeeMode=default\"" -DESP32=ESP32 -DCORE_DEBUG_LEVEL=0 -DARDUINO_RUNNING_CORE=1 -DARDUINO_EVENT_RUNNING_CORE=1 -DARDUINO_USB_MODE=1 -DARDUINO_USB_CDC_ON_BOOT=0 -DARDUINO_USB_MSC_ON_BOOT=0 -DARDUINO_USB_DFU_ON_BOOT=0 "@C:\Users\Simon\AppData\Local\arduino15\packages\esp32\tools\esp32s3-libs\3.3.8/flags/defines" "-IC:\GitProjects\PowerControlHub\PowerControlHub" -iprefix "C:\Users\Simon\AppData\Local\arduino15\packages\esp32\tools\esp32s3-libs\3.3.8/include/" "@C:\Users\Simon\AppData\Local\arduino15\packages\esp32\tools\esp32s3-libs\3.3.8/flags/includes" "-IC:\Users\Simon\AppData\Local\arduino15\packages\esp32\tools\esp32s3-libs\3.3.8/dio_qspi/include" -I"C:\Users\Simon\AppData\Local\arduino15\packages\esp32\hardware\esp32\3.3.8\cores\esp32" -I"C:\Users\Simon\AppData\Local\arduino15\packages\esp32\hardware\esp32\3.3.8\variants\esp32s3" -I"C:\ProgramData\vMicro\SerialDebug\VM_DBG" -I"C:\Users\Simon\Documents\Arduino\libraries\SerialCommandManager\src" -I"C:\Users\Simon\Documents\Arduino\libraries\SensorManager\src" -I"C:\Users\Simon\Documents\Arduino\libraries\SdFat\src" -I"C:\Users\Simon\AppData\Local\arduino15\packages\esp32\hardware\esp32\3.3.8\libraries\SPI\src" -I"C:\Users\Simon\AppData\Local\arduino15\packages\esp32\hardware\esp32\3.3.8\libraries\WiFi\src" -I"C:\Users\Simon\AppData\Local\arduino15\packages\esp32\hardware\esp32\3.3.8\libraries\Network\src" -I"C:\Users\Simon\Documents\Arduino\libraries\NextionControl\src" -I"C:\Users\Simon\Documents\Arduino\libraries\TinyGPSPlus\src" -I"C:\Users\Simon\AppData\Local\arduino15\packages\esp32\hardware\esp32\3.3.8\libraries\EEPROM\src" -I"C:\Users\Simon\AppData\Local\arduino15\packages\esp32\hardware\esp32\3.3.8\libraries\HTTPClient\src" -I"C:\Users\Simon\AppData\Local\arduino15\packages\esp32\hardware\esp32\3.3.8\libraries\NetworkClientSecure\src" -I"C:\Users\Simon\AppData\Local\arduino15\packages\esp32\hardware\esp32\3.3.8\libraries\Update\src"  -Wall -Wextra -DVM_DEBUG_BREAKPAUSE -DVM_DBT=VM_DBT_GENERIC_OBJECT -DVM_DEBUGGER_SOFT_TRANSPORT_WRITER=Serial -DVM_DEBUGGER_SOFT_TRANSPORT=Serial -DVM_DEBUG -DVM_DEBUG_ENABLE=1 -DVM_DBT_GENERIC_OBJECT=21 -DVM_DBT_NO_SERIAL=20 -DVM_DBT_MS430_SERIAL_=19 -DVM_DBT_SERIALUSB=18 -DVM_DBT_USBAPI=17 -DVM_DBT_NET_UDP=16 -DVM_DBT_HARDWARESERIAL3=15 -DVM_DBT_HARDWARESERIAL2=14 -DVM_DBT_HARDWARESERIAL1=13 -DVM_DBT_CDCSerialClass=12 -DVM_DBT_COSA=11 -DVM_DBT_Uart=10 -DVM_DBT_NET_CONSOLE=9 -DVM_DBT_TTYUART=8 -DVM_DBT_USBSERIAL=7 -DVM_DBT_USART=6 -DVM_DBT_UART=5 -DVM_DBT_TEENSY=4 -DVM_DBT_USB=3 -DVM_DBT_FASTSERIAL=2 -DVM_DBT_SOFTWARESERIAL=1 -DVM_DBT_HARDWARESERIAL=0 -I"C:\Users\Simon\Documents\Arduino\libraries\Ds1302\src" "@C:\Users\Simon\AppData\Local\Temp\VMBuilds\PowerControlHub\esp32_esp32s3\Debug/build_opt.h" "@C:\Users\Simon\AppData\Local\Temp\VMBuilds\PowerControlHub\esp32_esp32s3\Debug/file_opts" "C:\ProgramData\vMicro\SerialDebug\VM_DBG\VM_mem_check_sam.cpp" -o "C:\Users\Simon\AppData\Local\Temp\VMBuilds\PowerControlHub\esp32_esp32s3\Debug\VM_DBG\VM_mem_check_sam.cpp.o"

Using library SerialCommandManager version 3.0.0 by Si Carter <s1cart3r@gmail.com> in folder "C:\Users\Simon\Documents\Arduino\libraries\SerialCommandManager"
  Using previously compiled file: C:\Users\Simon\AppData\Local\Temp\VMBuilds\PowerControlHub\esp32_esp32s3\Debug\SerialCommandManager\BaseCommandHandler.cpp.o
  Using previously compiled file: C:\Users\Simon\AppData\Local\Temp\VMBuilds\PowerControlHub\esp32_esp32s3\Debug\SerialCommandManager\SerialCommandManager.cpp.o

Using library SensorManager version 1.1.0 by Si Carter <s1cart3r@gmail.com> in folder "C:\Users\Simon\Documents\Arduino\libraries\SensorManager"

Using library SdFat version 2.3.0 by Bill Greiman <fat16lib@sbcglobal.net> in folder "C:\Users\Simon\Documents\Arduino\libraries\SdFat"
  Using previously compiled file: C:\Users\Simon\AppData\Local\Temp\VMBuilds\PowerControlHub\esp32_esp32s3\Debug\SdFat\FreeStack.cpp.o
  Using previously compiled file: C:\Users\Simon\AppData\Local\Temp\VMBuilds\PowerControlHub\esp32_esp32s3\Debug\SdFat\MinimumSerial.cpp.o
  Using previously compiled file: C:\Users\Simon\AppData\Local\Temp\VMBuilds\PowerControlHub\esp32_esp32s3\Debug\SdFat\common\FmtNumber.cpp.o
  Using previously compiled file: C:\Users\Simon\AppData\Local\Temp\VMBuilds\PowerControlHub\esp32_esp32s3\Debug\SdFat\common\FsCache.cpp.o
  Using previously compiled file: C:\Users\Simon\AppData\Local\Temp\VMBuilds\PowerControlHub\esp32_esp32s3\Debug\SdFat\common\FsDateTime.cpp.o
  Using previously compiled file: C:\Users\Simon\AppData\Local\Temp\VMBuilds\PowerControlHub\esp32_esp32s3\Debug\SdFat\common\FsName.cpp.o
  Using previously compiled file: C:\Users\Simon\AppData\Local\Temp\VMBuilds\PowerControlHub\esp32_esp32s3\Debug\SdFat\common\FsStructs.cpp.o
  Using previously compiled file: C:\Users\Simon\AppData\Local\Temp\VMBuilds\PowerControlHub\esp32_esp32s3\Debug\SdFat\common\FsUtf.cpp.o
  Using previously compiled file: C:\Users\Simon\AppData\Local\Temp\VMBuilds\PowerControlHub\esp32_esp32s3\Debug\SdFat\common\PrintBasic.cpp.o
  Using previously compiled file: C:\Users\Simon\AppData\Local\Temp\VMBuilds\PowerControlHub\esp32_esp32s3\Debug\SdFat\common\upcase.cpp.o
  Using previously compiled file: C:\Users\Simon\AppData\Local\Temp\VMBuilds\PowerControlHub\esp32_esp32s3\Debug\SdFat\ExFatLib\ExFatDbg.cpp.o
  Using previously compiled file: C:\Users\Simon\AppData\Local\Temp\VMBuilds\PowerControlHub\esp32_esp32s3\Debug\SdFat\ExFatLib\ExFatFile.cpp.o
  Using previously compiled file: C:\Users\Simon\AppData\Local\Temp\VMBuilds\PowerControlHub\esp32_esp32s3\Debug\SdFat\ExFatLib\ExFatFilePrint.cpp.o
  Using previously compiled file: C:\Users\Simon\AppData\Local\Temp\VMBuilds\PowerControlHub\esp32_esp32s3\Debug\SdFat\ExFatLib\ExFatFileWrite.cpp.o
  Using previously compiled file: C:\Users\Simon\AppData\Local\Temp\VMBuilds\PowerControlHub\esp32_esp32s3\Debug\SdFat\ExFatLib\ExFatFormatter.cpp.o
  Using previously compiled file: C:\Users\Simon\AppData\Local\Temp\VMBuilds\PowerControlHub\esp32_esp32s3\Debug\SdFat\ExFatLib\ExFatName.cpp.o
  Using previously compiled file: C:\Users\Simon\AppData\Local\Temp\VMBuilds\PowerControlHub\esp32_esp32s3\Debug\SdFat\ExFatLib\ExFatPartition.cpp.o
  Using previously compiled file: C:\Users\Simon\AppData\Local\Temp\VMBuilds\PowerControlHub\esp32_esp32s3\Debug\SdFat\ExFatLib\ExFatVolume.cpp.o
  Using previously compiled file: C:\Users\Simon\AppData\Local\Temp\VMBuilds\PowerControlHub\esp32_esp32s3\Debug\SdFat\FatLib\FatDbg.cpp.o
  Using previously compiled file: C:\Users\Simon\AppData\Local\Temp\VMBuilds\PowerControlHub\esp32_esp32s3\Debug\SdFat\FatLib\FatFile.cpp.o
  Using previously compiled file: C:\Users\Simon\AppData\Local\Temp\VMBuilds\PowerControlHub\esp32_esp32s3\Debug\SdFat\FatLib\FatFileLFN.cpp.o
  Using previously compiled file: C:\Users\Simon\AppData\Local\Temp\VMBuilds\PowerControlHub\esp32_esp32s3\Debug\SdFat\FatLib\FatFilePrint.cpp.o
  Using previously compiled file: C:\Users\Simon\AppData\Local\Temp\VMBuilds\PowerControlHub\esp32_esp32s3\Debug\SdFat\FatLib\FatFileSFN.cpp.o
  Using previously compiled file: C:\Users\Simon\AppData\Local\Temp\VMBuilds\PowerControlHub\esp32_esp32s3\Debug\SdFat\FatLib\FatFormatter.cpp.o
  Using previously compiled file: C:\Users\Simon\AppData\Local\Temp\VMBuilds\PowerControlHub\esp32_esp32s3\Debug\SdFat\FatLib\FatName.cpp.o
  Using previously compiled file: C:\Users\Simon\AppData\Local\Temp\VMBuilds\PowerControlHub\esp32_esp32s3\Debug\SdFat\FatLib\FatPartition.cpp.o
  Using previously compiled file: C:\Users\Simon\AppData\Local\Temp\VMBuilds\PowerControlHub\esp32_esp32s3\Debug\SdFat\FatLib\FatVolume.cpp.o
  Using previously compiled file: C:\Users\Simon\AppData\Local\Temp\VMBuilds\PowerControlHub\esp32_esp32s3\Debug\SdFat\FsLib\FsFile.cpp.o
  Using previously compiled file: C:\Users\Simon\AppData\Local\Temp\VMBuilds\PowerControlHub\esp32_esp32s3\Debug\SdFat\FsLib\FsNew.cpp.o
  Using previously compiled file: C:\Users\Simon\AppData\Local\Temp\VMBuilds\PowerControlHub\esp32_esp32s3\Debug\SdFat\FsLib\FsVolume.cpp.o
  Using previously compiled file: C:\Users\Simon\AppData\Local\Temp\VMBuilds\PowerControlHub\esp32_esp32s3\Debug\SdFat\iostream\istream.cpp.o
  Using previously compiled file: C:\Users\Simon\AppData\Local\Temp\VMBuilds\PowerControlHub\esp32_esp32s3\Debug\SdFat\iostream\ostream.cpp.o
  Using previously compiled file: C:\Users\Simon\AppData\Local\Temp\VMBuilds\PowerControlHub\esp32_esp32s3\Debug\SdFat\iostream\StdioStream.cpp.o
  Using previously compiled file: C:\Users\Simon\AppData\Local\Temp\VMBuilds\PowerControlHub\esp32_esp32s3\Debug\SdFat\iostream\StreamBaseClass.cpp.o
  Using previously compiled file: C:\Users\Simon\AppData\Local\Temp\VMBuilds\PowerControlHub\esp32_esp32s3\Debug\SdFat\SdCard\SdCardInfo.cpp.o
  Using previously compiled file: C:\Users\Simon\AppData\Local\Temp\VMBuilds\PowerControlHub\esp32_esp32s3\Debug\SdFat\SdCard\SdSpiCard.cpp.o
  Using previously compiled file: C:\Users\Simon\AppData\Local\Temp\VMBuilds\PowerControlHub\esp32_esp32s3\Debug\SdFat\SdCard\Rp2040Sdio\PioSdioCard.cpp.o
  Using previously compiled file: C:\Users\Simon\AppData\Local\Temp\VMBuilds\PowerControlHub\esp32_esp32s3\Debug\SdFat\SdCard\TeensySdio\TeensySdio.cpp.o
  Using previously compiled file: C:\Users\Simon\AppData\Local\Temp\VMBuilds\PowerControlHub\esp32_esp32s3\Debug\SdFat\SpiDriver\SdSpiArtemis.cpp.o
  Using previously compiled file: C:\Users\Simon\AppData\Local\Temp\VMBuilds\PowerControlHub\esp32_esp32s3\Debug\SdFat\SpiDriver\SdSpiChipSelect.cpp.o
  Using previously compiled file: C:\Users\Simon\AppData\Local\Temp\VMBuilds\PowerControlHub\esp32_esp32s3\Debug\SdFat\SpiDriver\SdSpiDue.cpp.o
  Using previously compiled file: C:\Users\Simon\AppData\Local\Temp\VMBuilds\PowerControlHub\esp32_esp32s3\Debug\SdFat\SpiDriver\SdSpiParticle.cpp.o
  Using previously compiled file: C:\Users\Simon\AppData\Local\Temp\VMBuilds\PowerControlHub\esp32_esp32s3\Debug\SdFat\SpiDriver\SdSpiSTM32.cpp.o
  Using previously compiled file: C:\Users\Simon\AppData\Local\Temp\VMBuilds\PowerControlHub\esp32_esp32s3\Debug\SdFat\SpiDriver\SdSpiSTM32Core.cpp.o
  Using previously compiled file: C:\Users\Simon\AppData\Local\Temp\VMBuilds\PowerControlHub\esp32_esp32s3\Debug\SdFat\SpiDriver\SdSpiTeensy3.cpp.o

Using library SPI version 3.3.8 by Hristo Gochkov <hristo@espressif.com> in folder "C:\Users\Simon\AppData\Local\arduino15\packages\esp32\hardware\esp32\3.3.8\libraries\SPI"
  Using previously compiled file: C:\Users\Simon\AppData\Local\Temp\VMBuilds\PowerControlHub\esp32_esp32s3\Debug\SPI\SPI.cpp.o

Using library WiFi version 3.3.8 by Hristo Gochkov <hristo@espressif.com> in folder "C:\Users\Simon\AppData\Local\arduino15\packages\esp32\hardware\esp32\3.3.8\libraries\WiFi"
  Using previously compiled file: C:\Users\Simon\AppData\Local\Temp\VMBuilds\PowerControlHub\esp32_esp32s3\Debug\WiFi\AP.cpp.o
  Using previously compiled file: C:\Users\Simon\AppData\Local\Temp\VMBuilds\PowerControlHub\esp32_esp32s3\Debug\WiFi\STA.cpp.o
  Using previously compiled file: C:\Users\Simon\AppData\Local\Temp\VMBuilds\PowerControlHub\esp32_esp32s3\Debug\WiFi\WiFi.cpp.o
  Using previously compiled file: C:\Users\Simon\AppData\Local\Temp\VMBuilds\PowerControlHub\esp32_esp32s3\Debug\WiFi\WiFiAP.cpp.o
  Using previously compiled file: C:\Users\Simon\AppData\Local\Temp\VMBuilds\PowerControlHub\esp32_esp32s3\Debug\WiFi\WiFiGeneric.cpp.o
  Using previously compiled file: C:\Users\Simon\AppData\Local\Temp\VMBuilds\PowerControlHub\esp32_esp32s3\Debug\WiFi\WiFiMulti.cpp.o
  Using previously compiled file: C:\Users\Simon\AppData\Local\Temp\VMBuilds\PowerControlHub\esp32_esp32s3\Debug\WiFi\WiFiScan.cpp.o
  Using previously compiled file: C:\Users\Simon\AppData\Local\Temp\VMBuilds\PowerControlHub\esp32_esp32s3\Debug\WiFi\WiFiSTA.cpp.o

Using library Network version 3.3.8 by Hristo Gochkov <hristo@espressif.com> in folder "C:\Users\Simon\AppData\Local\arduino15\packages\esp32\hardware\esp32\3.3.8\libraries\Network"
  Using previously compiled file: C:\Users\Simon\AppData\Local\Temp\VMBuilds\PowerControlHub\esp32_esp32s3\Debug\Network\NetworkClient.cpp.o
  Using previously compiled file: C:\Users\Simon\AppData\Local\Temp\VMBuilds\PowerControlHub\esp32_esp32s3\Debug\Network\NetworkEvents.cpp.o
  Using previously compiled file: C:\Users\Simon\AppData\Local\Temp\VMBuilds\PowerControlHub\esp32_esp32s3\Debug\Network\NetworkInterface.cpp.o
  Using previously compiled file: C:\Users\Simon\AppData\Local\Temp\VMBuilds\PowerControlHub\esp32_esp32s3\Debug\Network\NetworkManager.cpp.o
  Using previously compiled file: C:\Users\Simon\AppData\Local\Temp\VMBuilds\PowerControlHub\esp32_esp32s3\Debug\Network\NetworkServer.cpp.o
  Using previously compiled file: C:\Users\Simon\AppData\Local\Temp\VMBuilds\PowerControlHub\esp32_esp32s3\Debug\Network\NetworkUdp.cpp.o

Using library NextionControl version 1.7.0 by Si Carter <s1cart3r@gmail.com> in folder "C:\Users\Simon\Documents\Arduino\libraries\NextionControl"
  Using previously compiled file: C:\Users\Simon\AppData\Local\Temp\VMBuilds\PowerControlHub\esp32_esp32s3\Debug\NextionControl\NextionControl.cpp.o

Using library TinyGPSPlus version 1.0.3 by Mikal Hart<mikal@arduniana.org> in folder "C:\Users\Simon\Documents\Arduino\libraries\TinyGPSPlus"
  Using previously compiled file: C:\Users\Simon\AppData\Local\Temp\VMBuilds\PowerControlHub\esp32_esp32s3\Debug\TinyGPSPlus\TinyGPS++.cpp.o

Using library EEPROM version 3.3.8 by Paolo Becchi <pbecchi@aerobusiness.it> in folder "C:\Users\Simon\AppData\Local\arduino15\packages\esp32\hardware\esp32\3.3.8\libraries\EEPROM"
  Using previously compiled file: C:\Users\Simon\AppData\Local\Temp\VMBuilds\PowerControlHub\esp32_esp32s3\Debug\EEPROM\EEPROM.cpp.o

Using library HTTPClient version 3.3.8 by Markus Sattler in folder "C:\Users\Simon\AppData\Local\arduino15\packages\esp32\hardware\esp32\3.3.8\libraries\HTTPClient"
  Using previously compiled file: C:\Users\Simon\AppData\Local\Temp\VMBuilds\PowerControlHub\esp32_esp32s3\Debug\HTTPClient\HTTPClient.cpp.o

Using library NetworkClientSecure version 3.3.8 by Github Community in folder "C:\Users\Simon\AppData\Local\arduino15\packages\esp32\hardware\esp32\3.3.8\libraries\NetworkClientSecure"
  Using previously compiled file: C:\Users\Simon\AppData\Local\Temp\VMBuilds\PowerControlHub\esp32_esp32s3\Debug\NetworkClientSecure\NetworkClientSecure.cpp.o
  Using previously compiled file: C:\Users\Simon\AppData\Local\Temp\VMBuilds\PowerControlHub\esp32_esp32s3\Debug\NetworkClientSecure\ssl_client.cpp.o

Using library Update version 3.3.8 by Hristo Gochkov <hristo@espressif.com> in folder "C:\Users\Simon\AppData\Local\arduino15\packages\esp32\hardware\esp32\3.3.8\libraries\Update"
  Using previously compiled file: C:\Users\Simon\AppData\Local\Temp\VMBuilds\PowerControlHub\esp32_esp32s3\Debug\Update\HttpsOTAUpdate.cpp.o
  Using previously compiled file: C:\Users\Simon\AppData\Local\Temp\VMBuilds\PowerControlHub\esp32_esp32s3\Debug\Update\Updater.cpp.o
  Using previously compiled file: C:\Users\Simon\AppData\Local\Temp\VMBuilds\PowerControlHub\esp32_esp32s3\Debug\Update\Updater_Signing.cpp.o

Using library Ds1302 version 1.1.0 by Rafa Couto <caligari@treboada.net> in folder "C:\Users\Simon\Documents\Arduino\libraries\Ds1302"
  Using previously compiled file: C:\Users\Simon\AppData\Local\Temp\VMBuilds\PowerControlHub\esp32_esp32s3\Debug\Ds1302\Ds1302.cpp.o
 
Building project code ...
  Using previously compiled file: C:\Users\Simon\AppData\Local\Temp\VMBuilds\PowerControlHub\esp32_esp32s3\Debug\PowerControlHub.cpp.o
  Using previously compiled file: C:\Users\Simon\AppData\Local\Temp\VMBuilds\PowerControlHub\esp32_esp32s3\Debug\AckCommandHandler.cpp.o
  Using previously compiled file: C:\Users\Simon\AppData\Local\Temp\VMBuilds\PowerControlHub\esp32_esp32s3\Debug\BaseNextionCommandHandler.cpp.o
  Using previously compiled file: C:\Users\Simon\AppData\Local\Temp\VMBuilds\PowerControlHub\esp32_esp32s3\Debug\BasePage.cpp.o
  Using previously compiled file: C:\Users\Simon\AppData\Local\Temp\VMBuilds\PowerControlHub\esp32_esp32s3\Debug\BinaryPresenceSensor.cpp.o
  Using previously compiled file: C:\Users\Simon\AppData\Local\Temp\VMBuilds\PowerControlHub\esp32_esp32s3\Debug\BluetoothManager.cpp.o
  Using previously compiled file: C:\Users\Simon\AppData\Local\Temp\VMBuilds\PowerControlHub\esp32_esp32s3\Debug\BluetoothRelayService.cpp.o
  Using previously compiled file: C:\Users\Simon\AppData\Local\Temp\VMBuilds\PowerControlHub\esp32_esp32s3\Debug\BluetoothSensorService.cpp.o
  Using previously compiled file: C:\Users\Simon\AppData\Local\Temp\VMBuilds\PowerControlHub\esp32_esp32s3\Debug\BluetoothSystemService.cpp.o
  Using previously compiled file: C:\Users\Simon\AppData\Local\Temp\VMBuilds\PowerControlHub\esp32_esp32s3\Debug\BroadcastManager.cpp.o
  Using previously compiled file: C:\Users\Simon\AppData\Local\Temp\VMBuilds\PowerControlHub\esp32_esp32s3\Debug\ConfigCommandHandler.cpp.o
  Using previously compiled file: C:\Users\Simon\AppData\Local\Temp\VMBuilds\PowerControlHub\esp32_esp32s3\Debug\ConfigController.cpp.o
  Using previously compiled file: C:\Users\Simon\AppData\Local\Temp\VMBuilds\PowerControlHub\esp32_esp32s3\Debug\ConfigManager.cpp.o
  Using previously compiled file: C:\Users\Simon\AppData\Local\Temp\VMBuilds\PowerControlHub\esp32_esp32s3\Debug\ConfigNetworkHandler.cpp.o
  Using previously compiled file: C:\Users\Simon\AppData\Local\Temp\VMBuilds\PowerControlHub\esp32_esp32s3\Debug\DateTimeManager.cpp.o
  Using previously compiled file: C:\Users\Simon\AppData\Local\Temp\VMBuilds\PowerControlHub\esp32_esp32s3\Debug\ExternalSensorNetworkHandler.cpp.o
  Using previously compiled file: C:\Users\Simon\AppData\Local\Temp\VMBuilds\PowerControlHub\esp32_esp32s3\Debug\LedMatrixManager.cpp.o
  Using previously compiled file: C:\Users\Simon\AppData\Local\Temp\VMBuilds\PowerControlHub\esp32_esp32s3\Debug\MicroSdDriver.cpp.o
  Using previously compiled file: C:\Users\Simon\AppData\Local\Temp\VMBuilds\PowerControlHub\esp32_esp32s3\Debug\MQTTClient.cpp.o
  Using previously compiled file: C:\Users\Simon\AppData\Local\Temp\VMBuilds\PowerControlHub\esp32_esp32s3\Debug\MQTTConfigCommandHandler.cpp.o
  Using previously compiled file: C:\Users\Simon\AppData\Local\Temp\VMBuilds\PowerControlHub\esp32_esp32s3\Debug\MQTTController.cpp.o
  Using previously compiled file: C:\Users\Simon\AppData\Local\Temp\VMBuilds\PowerControlHub\esp32_esp32s3\Debug\MQTTHandler.cpp.o
  Using previously compiled file: C:\Users\Simon\AppData\Local\Temp\VMBuilds\PowerControlHub\esp32_esp32s3\Debug\MQTTRelayHandler.cpp.o
  Using previously compiled file: C:\Users\Simon\AppData\Local\Temp\VMBuilds\PowerControlHub\esp32_esp32s3\Debug\MQTTSensorHandler.cpp.o
  Using previously compiled file: C:\Users\Simon\AppData\Local\Temp\VMBuilds\PowerControlHub\esp32_esp32s3\Debug\MQTTSystemHandler.cpp.o
  Using previously compiled file: C:\Users\Simon\AppData\Local\Temp\VMBuilds\PowerControlHub\esp32_esp32s3\Debug\NavigationController.cpp.o
  Using previously compiled file: C:\Users\Simon\AppData\Local\Temp\VMBuilds\PowerControlHub\esp32_esp32s3\Debug\OtaManager.cpp.o
  Using previously compiled file: C:\Users\Simon\AppData\Local\Temp\VMBuilds\PowerControlHub\esp32_esp32s3\Debug\PageAbout.cpp.o
  Using previously compiled file: C:\Users\Simon\AppData\Local\Temp\VMBuilds\PowerControlHub\esp32_esp32s3\Debug\PageBuoys.cpp.o
  Using previously compiled file: C:\Users\Simon\AppData\Local\Temp\VMBuilds\PowerControlHub\esp32_esp32s3\Debug\PageCardinalMarkers.cpp.o
  Using previously compiled file: C:\Users\Simon\AppData\Local\Temp\VMBuilds\PowerControlHub\esp32_esp32s3\Debug\PageEnvironment.cpp.o
  Using previously compiled file: C:\Users\Simon\AppData\Local\Temp\VMBuilds\PowerControlHub\esp32_esp32s3\Debug\PageFlags.cpp.o
  Using previously compiled file: C:\Users\Simon\AppData\Local\Temp\VMBuilds\PowerControlHub\esp32_esp32s3\Debug\PageHome.cpp.o
  Using previously compiled file: C:\Users\Simon\AppData\Local\Temp\VMBuilds\PowerControlHub\esp32_esp32s3\Debug\PageMoonPhase.cpp.o
  Using previously compiled file: C:\Users\Simon\AppData\Local\Temp\VMBuilds\PowerControlHub\esp32_esp32s3\Debug\PageRelay.cpp.o
  Using previously compiled file: C:\Users\Simon\AppData\Local\Temp\VMBuilds\PowerControlHub\esp32_esp32s3\Debug\PageRelaySettings.cpp.o
  Using previously compiled file: C:\Users\Simon\AppData\Local\Temp\VMBuilds\PowerControlHub\esp32_esp32s3\Debug\PageSettings.cpp.o
  Using previously compiled file: C:\Users\Simon\AppData\Local\Temp\VMBuilds\PowerControlHub\esp32_esp32s3\Debug\PageSoundEmergency.cpp.o
  Using previously compiled file: C:\Users\Simon\AppData\Local\Temp\VMBuilds\PowerControlHub\esp32_esp32s3\Debug\PageSoundFog.cpp.o
  Using previously compiled file: C:\Users\Simon\AppData\Local\Temp\VMBuilds\PowerControlHub\esp32_esp32s3\Debug\PageSoundManeuvering.cpp.o
  Using previously compiled file: C:\Users\Simon\AppData\Local\Temp\VMBuilds\PowerControlHub\esp32_esp32s3\Debug\PageSoundOther.cpp.o
  Using previously compiled file: C:\Users\Simon\AppData\Local\Temp\VMBuilds\PowerControlHub\esp32_esp32s3\Debug\PageSoundOvertaking.cpp.o
  Using previously compiled file: C:\Users\Simon\AppData\Local\Temp\VMBuilds\PowerControlHub\esp32_esp32s3\Debug\PageSoundSignals.cpp.o
  Using previously compiled file: C:\Users\Simon\AppData\Local\Temp\VMBuilds\PowerControlHub\esp32_esp32s3\Debug\PageSystem.cpp.o
  Using previously compiled file: C:\Users\Simon\AppData\Local\Temp\VMBuilds\PowerControlHub\esp32_esp32s3\Debug\PageVhfChannels.cpp.o
  Using previously compiled file: C:\Users\Simon\AppData\Local\Temp\VMBuilds\PowerControlHub\esp32_esp32s3\Debug\PageVhfDistress.cpp.o
  Using previously compiled file: C:\Users\Simon\AppData\Local\Temp\VMBuilds\PowerControlHub\esp32_esp32s3\Debug\PageVhfRadio.cpp.o
  Using previously compiled file: C:\Users\Simon\AppData\Local\Temp\VMBuilds\PowerControlHub\esp32_esp32s3\Debug\PageWarning.cpp.o
  Using previously compiled file: C:\Users\Simon\AppData\Local\Temp\VMBuilds\PowerControlHub\esp32_esp32s3\Debug\Phonetic.cpp.o
  Using previously compiled file: C:\Users\Simon\AppData\Local\Temp\VMBuilds\PowerControlHub\esp32_esp32s3\Debug\PowerControlHubApp.cpp.o
  Using previously compiled file: C:\Users\Simon\AppData\Local\Temp\VMBuilds\PowerControlHub\esp32_esp32s3\Debug\RelayCommandHandler.cpp.o
  Using previously compiled file: C:\Users\Simon\AppData\Local\Temp\VMBuilds\PowerControlHub\esp32_esp32s3\Debug\RelayNetworkHandler.cpp.o
  Using previously compiled file: C:\Users\Simon\AppData\Local\Temp\VMBuilds\PowerControlHub\esp32_esp32s3\Debug\RtcDS1302Driver.cpp.o
  Using previously compiled file: C:\Users\Simon\AppData\Local\Temp\VMBuilds\PowerControlHub\esp32_esp32s3\Debug\ScheduleController.cpp.o
  Using previously compiled file: C:\Users\Simon\AppData\Local\Temp\VMBuilds\PowerControlHub\esp32_esp32s3\Debug\SchedulerCommandHandler.cpp.o
  Using previously compiled file: C:\Users\Simon\AppData\Local\Temp\VMBuilds\PowerControlHub\esp32_esp32s3\Debug\SchedulerNetworkHandler.cpp.o
  Using previously compiled file: C:\Users\Simon\AppData\Local\Temp\VMBuilds\PowerControlHub\esp32_esp32s3\Debug\SDCardConfigLoader.cpp.o
  Using previously compiled file: C:\Users\Simon\AppData\Local\Temp\VMBuilds\PowerControlHub\esp32_esp32s3\Debug\SdCardLogger.cpp.o
  Using previously compiled file: C:\Users\Simon\AppData\Local\Temp\VMBuilds\PowerControlHub\esp32_esp32s3\Debug\SensorCommandHandler.cpp.o
"C:\Users\Simon\AppData\Local\arduino15\packages\esp32\tools\esp-x32\2601/bin/xtensa-esp32s3-elf-g++" -MMD -c "@C:\Users\Simon\AppData\Local\arduino15\packages\esp32\tools\esp32s3-libs\3.3.8/flags/cpp_flags" -Wall -Os -Werror=return-type -DF_CPU=240000000L -DARDUINO=108010 -DARDUINO_ESP32S3_DEV -DARDUINO_ARCH_ESP32 "-DARDUINO_BOARD=\"ESP32S3_DEV\"" "-DARDUINO_VARIANT=\"esp32s3\"" -DARDUINO_PARTITION_min_spiffs "-DARDUINO_HOST_OS=\"windows\"" "-DARDUINO_FQBN=\"esp32:esp32:esp32s3:UploadSpeed=921600,USBMode=hwcdc,CDCOnBoot=default,MSCOnBoot=default,DFUOnBoot=default,UploadMode=default,CPUFreq=240,FlashMode=qio,FlashSize=4M,PartitionScheme=min_spiffs,DebugLevel=none,PSRAM=disabled,LoopCore=1,EventsCore=1,EraseFlash=none,JTAGAdapter=default,ZigbeeMode=default\"" -DESP32=ESP32 -DCORE_DEBUG_LEVEL=0 -DARDUINO_RUNNING_CORE=1 -DARDUINO_EVENT_RUNNING_CORE=1 -DARDUINO_USB_MODE=1 -DARDUINO_USB_CDC_ON_BOOT=0 -DARDUINO_USB_MSC_ON_BOOT=0 -DARDUINO_USB_DFU_ON_BOOT=0 "@C:\Users\Simon\AppData\Local\arduino15\packages\esp32\tools\esp32s3-libs\3.3.8/flags/defines" "-IC:\GitProjects\PowerControlHub\PowerControlHub" -iprefix "C:\Users\Simon\AppData\Local\arduino15\packages\esp32\tools\esp32s3-libs\3.3.8/include/" "@C:\Users\Simon\AppData\Local\arduino15\packages\esp32\tools\esp32s3-libs\3.3.8/flags/includes" "-IC:\Users\Simon\AppData\Local\arduino15\packages\esp32\tools\esp32s3-libs\3.3.8/dio_qspi/include" -I"C:\GitProjects\PowerControlHub\PowerControlHub" -I"C:\Users\Simon\AppData\Local\arduino15\packages\esp32\hardware\esp32\3.3.8\cores\esp32" -I"C:\Users\Simon\AppData\Local\arduino15\packages\esp32\hardware\esp32\3.3.8\variants\esp32s3" -I"C:\ProgramData\vMicro\SerialDebug\VM_DBG" -I"C:\Users\Simon\Documents\Arduino\libraries\SerialCommandManager\src" -I"C:\Users\Simon\Documents\Arduino\libraries\SensorManager\src" -I"C:\Users\Simon\Documents\Arduino\libraries\SdFat\src" -I"C:\Users\Simon\AppData\Local\arduino15\packages\esp32\hardware\esp32\3.3.8\libraries\SPI\src" -I"C:\Users\Simon\AppData\Local\arduino15\packages\esp32\hardware\esp32\3.3.8\libraries\WiFi\src" -I"C:\Users\Simon\AppData\Local\arduino15\packages\esp32\hardware\esp32\3.3.8\libraries\Network\src" -I"C:\Users\Simon\Documents\Arduino\libraries\NextionControl\src" -I"C:\Users\Simon\Documents\Arduino\libraries\TinyGPSPlus\src" -I"C:\Users\Simon\AppData\Local\arduino15\packages\esp32\hardware\esp32\3.3.8\libraries\EEPROM\src" -I"C:\Users\Simon\AppData\Local\arduino15\packages\esp32\hardware\esp32\3.3.8\libraries\HTTPClient\src" -I"C:\Users\Simon\AppData\Local\arduino15\packages\esp32\hardware\esp32\3.3.8\libraries\NetworkClientSecure\src" -I"C:\Users\Simon\AppData\Local\arduino15\packages\esp32\hardware\esp32\3.3.8\libraries\Update\src"  -Wall -Wextra -DVM_DEBUG_BREAKPAUSE -DVM_DBT=VM_DBT_GENERIC_OBJECT -DVM_DEBUGGER_SOFT_TRANSPORT_WRITER=Serial -DVM_DEBUGGER_SOFT_TRANSPORT=Serial -DVM_DEBUG -DVM_DEBUG_ENABLE=1 -DVM_DBT_GENERIC_OBJECT=21 -DVM_DBT_NO_SERIAL=20 -DVM_DBT_MS430_SERIAL_=19 -DVM_DBT_SERIALUSB=18 -DVM_DBT_USBAPI=17 -DVM_DBT_NET_UDP=16 -DVM_DBT_HARDWARESERIAL3=15 -DVM_DBT_HARDWARESERIAL2=14 -DVM_DBT_HARDWARESERIAL1=13 -DVM_DBT_CDCSerialClass=12 -DVM_DBT_COSA=11 -DVM_DBT_Uart=10 -DVM_DBT_NET_CONSOLE=9 -DVM_DBT_TTYUART=8 -DVM_DBT_USBSERIAL=7 -DVM_DBT_USART=6 -DVM_DBT_UART=5 -DVM_DBT_TEENSY=4 -DVM_DBT_USB=3 -DVM_DBT_FASTSERIAL=2 -DVM_DBT_SOFTWARESERIAL=1 -DVM_DBT_HARDWARESERIAL=0 -I"C:\Users\Simon\Documents\Arduino\libraries\Ds1302\src" "@C:\Users\Simon\AppData\Local\Temp\VMBuilds\PowerControlHub\esp32_esp32s3\Debug/build_opt.h" "@C:\Users\Simon\AppData\Local\Temp\VMBuilds\PowerControlHub\esp32_esp32s3\Debug/file_opts" "C:\Users\Simon\AppData\Local\Temp\VMBuilds\PowerControlHub\esp32_esp32s3\Debug\SensorNetworkHandler.cpp" -o "C:\Users\Simon\AppData\Local\Temp\VMBuilds\PowerControlHub\esp32_esp32s3\Debug\SensorNetworkHandler.cpp.o"
  Using previously compiled file: C:\Users\Simon\AppData\Local\Temp\VMBuilds\PowerControlHub\esp32_esp32s3\Debug\SoundCommandHandler.cpp.o
  Using previously compiled file: C:\Users\Simon\AppData\Local\Temp\VMBuilds\PowerControlHub\esp32_esp32s3\Debug\SoundController.cpp.o
  Using previously compiled file: C:\Users\Simon\AppData\Local\Temp\VMBuilds\PowerControlHub\esp32_esp32s3\Debug\SoundNetworkHandler.cpp.o
  Using previously compiled file: C:\Users\Simon\AppData\Local\Temp\VMBuilds\PowerControlHub\esp32_esp32s3\Debug\SunCalculator.cpp.o
  Using previously compiled file: C:\Users\Simon\AppData\Local\Temp\VMBuilds\PowerControlHub\esp32_esp32s3\Debug\SystemCommandHandler.cpp.o
  Using previously compiled file: C:\Users\Simon\AppData\Local\Temp\VMBuilds\PowerControlHub\esp32_esp32s3\Debug\SystemCpuMonitor.cpp.o
  Using previously compiled file: C:\Users\Simon\AppData\Local\Temp\VMBuilds\PowerControlHub\esp32_esp32s3\Debug\SystemFunctions.cpp.o
  Using previously compiled file: C:\Users\Simon\AppData\Local\Temp\VMBuilds\PowerControlHub\esp32_esp32s3\Debug\SystemNetworkHandler.cpp.o
  Using previously compiled file: C:\Users\Simon\AppData\Local\Temp\VMBuilds\PowerControlHub\esp32_esp32s3\Debug\ToneManager.cpp.o
  Using previously compiled file: C:\Users\Simon\AppData\Local\Temp\VMBuilds\PowerControlHub\esp32_esp32s3\Debug\WarningCommandHandler.cpp.o
  Using previously compiled file: C:\Users\Simon\AppData\Local\Temp\VMBuilds\PowerControlHub\esp32_esp32s3\Debug\WarningManager.cpp.o
  Using previously compiled file: C:\Users\Simon\AppData\Local\Temp\VMBuilds\PowerControlHub\esp32_esp32s3\Debug\WarningNetworkHandler.cpp.o
  Using previously compiled file: C:\Users\Simon\AppData\Local\Temp\VMBuilds\PowerControlHub\esp32_esp32s3\Debug\WifiCommandBridge.cpp.o
  Using previously compiled file: C:\Users\Simon\AppData\Local\Temp\VMBuilds\PowerControlHub\esp32_esp32s3\Debug\WifiServer.cpp.o
 
Linking it all together ...
# Coping cached core C:\Users\Simon\AppData\Local\Temp\VMBCore\arduino20x\1fe2f24ae03749f2ec8fd1dcec6b1151\core.a to C:\Users\Simon\AppData\Local\Temp\VMBuilds\PowerControlHub\esp32_esp32s3\Debug\core.a

"C:\Users\Simon\AppData\Local\arduino15\packages\esp32\tools\esp-x32\2601/bin/xtensa-esp32s3-elf-g++" "-Wl,--Map=C:\Users\Simon\AppData\Local\Temp\VMBuilds\PowerControlHub\esp32_esp32s3\Debug/PowerControlHub.ino.map" "-LC:\Users\Simon\AppData\Local\arduino15\packages\esp32\tools\esp32s3-libs\3.3.8/lib" "-LC:\Users\Simon\AppData\Local\arduino15\packages\esp32\tools\esp32s3-libs\3.3.8/ld" "-LC:\Users\Simon\AppData\Local\arduino15\packages\esp32\tools\esp32s3-libs\3.3.8/dio_qspi" "-Wl,--wrap=esp_panic_handler" "@C:\Users\Simon\AppData\Local\arduino15\packages\esp32\tools\esp32s3-libs\3.3.8/flags/ld_flags" "@C:\Users\Simon\AppData\Local\arduino15\packages\esp32\tools\esp32s3-libs\3.3.8/flags/ld_scripts" -Wl,--start-group "PowerControlHub.cpp.o" "AckCommandHandler.cpp.o" "BaseNextionCommandHandler.cpp.o" "BasePage.cpp.o" "BinaryPresenceSensor.cpp.o" "BluetoothManager.cpp.o" "BluetoothRelayService.cpp.o" "BluetoothSensorService.cpp.o" "BluetoothSystemService.cpp.o" "BroadcastManager.cpp.o" "ConfigCommandHandler.cpp.o" "ConfigController.cpp.o" "ConfigManager.cpp.o" "ConfigNetworkHandler.cpp.o" "DateTimeManager.cpp.o" "ExternalSensorNetworkHandler.cpp.o" "LedMatrixManager.cpp.o" "MicroSdDriver.cpp.o" "MQTTClient.cpp.o" "MQTTConfigCommandHandler.cpp.o" "MQTTController.cpp.o" "MQTTHandler.cpp.o" "MQTTRelayHandler.cpp.o" "MQTTSensorHandler.cpp.o" "MQTTSystemHandler.cpp.o" "NavigationController.cpp.o" "OtaManager.cpp.o" "PageAbout.cpp.o" "PageBuoys.cpp.o" "PageCardinalMarkers.cpp.o" "PageEnvironment.cpp.o" "PageFlags.cpp.o" "PageHome.cpp.o" "PageMoonPhase.cpp.o" "PageRelay.cpp.o" "PageRelaySettings.cpp.o" "PageSettings.cpp.o" "PageSoundEmergency.cpp.o" "PageSoundFog.cpp.o" "PageSoundManeuvering.cpp.o" "PageSoundOther.cpp.o" "PageSoundOvertaking.cpp.o" "PageSoundSignals.cpp.o" "PageSystem.cpp.o" "PageVhfChannels.cpp.o" "PageVhfDistress.cpp.o" "PageVhfRadio.cpp.o" "PageWarning.cpp.o" "Phonetic.cpp.o" "PowerControlHubApp.cpp.o" "RelayCommandHandler.cpp.o" "RelayNetworkHandler.cpp.o" "RtcDS1302Driver.cpp.o" "ScheduleController.cpp.o" "SchedulerCommandHandler.cpp.o" "SchedulerNetworkHandler.cpp.o" "SDCardConfigLoader.cpp.o" "SdCardLogger.cpp.o" "SensorCommandHandler.cpp.o" "SensorNetworkHandler.cpp.o" "SoundCommandHandler.cpp.o" "SoundController.cpp.o" "SoundNetworkHandler.cpp.o" "SunCalculator.cpp.o" "SystemCommandHandler.cpp.o" "SystemCpuMonitor.cpp.o" "SystemFunctions.cpp.o" "SystemNetworkHandler.cpp.o" "ToneManager.cpp.o" "WarningCommandHandler.cpp.o" "WarningManager.cpp.o" "WarningNetworkHandler.cpp.o" "WifiCommandBridge.cpp.o" "WifiServer.cpp.o" "VM_DBG\VM_DBG.cpp.o" "VM_DBG\VM_mem_check_sam.cpp.o" "SerialCommandManager\BaseCommandHandler.cpp.o" "SerialCommandManager\SerialCommandManager.cpp.o" "SdFat\FreeStack.cpp.o" "SdFat\MinimumSerial.cpp.o" "SdFat\common\FmtNumber.cpp.o" "SdFat\common\FsCache.cpp.o" "SdFat\common\FsDateTime.cpp.o" "SdFat\common\FsName.cpp.o" "SdFat\common\FsStructs.cpp.o" "SdFat\common\FsUtf.cpp.o" "SdFat\common\PrintBasic.cpp.o" "SdFat\common\upcase.cpp.o" "SdFat\ExFatLib\ExFatDbg.cpp.o" "SdFat\ExFatLib\ExFatFile.cpp.o" "SdFat\ExFatLib\ExFatFilePrint.cpp.o" "SdFat\ExFatLib\ExFatFileWrite.cpp.o" "SdFat\ExFatLib\ExFatFormatter.cpp.o" "SdFat\ExFatLib\ExFatName.cpp.o" "SdFat\ExFatLib\ExFatPartition.cpp.o" "SdFat\ExFatLib\ExFatVolume.cpp.o" "SdFat\FatLib\FatDbg.cpp.o" "SdFat\FatLib\FatFile.cpp.o" "SdFat\FatLib\FatFileLFN.cpp.o" "SdFat\FatLib\FatFilePrint.cpp.o" "SdFat\FatLib\FatFileSFN.cpp.o" "SdFat\FatLib\FatFormatter.cpp.o" "SdFat\FatLib\FatName.cpp.o" "SdFat\FatLib\FatPartition.cpp.o" "SdFat\FatLib\FatVolume.cpp.o" "SdFat\FsLib\FsFile.cpp.o" "SdFat\FsLib\FsNew.cpp.o" "SdFat\FsLib\FsVolume.cpp.o" "SdFat\iostream\istream.cpp.o" "SdFat\iostream\ostream.cpp.o" "SdFat\iostream\StdioStream.cpp.o" "SdFat\iostream\StreamBaseClass.cpp.o" "SdFat\SdCard\SdCardInfo.cpp.o" "SdFat\SdCard\SdSpiCard.cpp.o" "SdFat\SdCard\Rp2040Sdio\PioSdioCard.cpp.o" "SdFat\SdCard\TeensySdio\TeensySdio.cpp.o" "SdFat\SpiDriver\SdSpiArtemis.cpp.o" "SdFat\SpiDriver\SdSpiChipSelect.cpp.o" "SdFat\SpiDriver\SdSpiDue.cpp.o" "SdFat\SpiDriver\SdSpiParticle.cpp.o" "SdFat\SpiDriver\SdSpiSTM32.cpp.o" "SdFat\SpiDriver\SdSpiSTM32Core.cpp.o" "SdFat\SpiDriver\SdSpiTeensy3.cpp.o" "SPI\SPI.cpp.o" "WiFi\AP.cpp.o" "WiFi\STA.cpp.o" "WiFi\WiFi.cpp.o" "WiFi\WiFiAP.cpp.o" "WiFi\WiFiGeneric.cpp.o" "WiFi\WiFiMulti.cpp.o" "WiFi\WiFiScan.cpp.o" "WiFi\WiFiSTA.cpp.o" "Network\NetworkClient.cpp.o" "Network\NetworkEvents.cpp.o" "Network\NetworkInterface.cpp.o" "Network\NetworkManager.cpp.o" "Network\NetworkServer.cpp.o" "Network\NetworkUdp.cpp.o" "NextionControl\NextionControl.cpp.o" "TinyGPSPlus\TinyGPS++.cpp.o" "EEPROM\EEPROM.cpp.o" "HTTPClient\HTTPClient.cpp.o" "NetworkClientSecure\NetworkClientSecure.cpp.o" "NetworkClientSecure\ssl_client.cpp.o" "Update\HttpsOTAUpdate.cpp.o" "Update\Updater.cpp.o" "Update\Updater_Signing.cpp.o" "Ds1302\Ds1302.cpp.o" "C:\Users\Simon\AppData\Local\Temp\VMBuilds\PowerControlHub\esp32_esp32s3\Debug\core.a" "@C:\Users\Simon\AppData\Local\arduino15\packages\esp32\tools\esp32s3-libs\3.3.8/flags/ld_libs" -Wl,--end-group -Wl,-EL -o "C:\Users\Simon\AppData\Local\Temp\VMBuilds\PowerControlHub\esp32_esp32s3\Debug/PowerControlHub.ino.elf"
ld.exe: PowerControlHubApp.cpp.o:(.literal._ZN18PowerControlHubAppC2EP20SerialCommandManager+0x1c): undefined reference to vtable for SensorConfigNetworkHandler
collect2.exe*: error: ld returned 1 exit status

Error linking for board ESP32S3 Dev Module(esp32_esp32s3)
 
Debug build failed for project 'PowerControlHub'

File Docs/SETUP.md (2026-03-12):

# SmartFuseBox Setup Guide

This guide covers everything you need to know to successfully check out and build the SmartFuseBox repository on Windows.

---

## 📋 Prerequisites

### Required Software
- **Git for Windows** (with symbolic link support enabled)
- **Arduino IDE** (1.8.19+ or Arduino IDE 2.x)
- **Windows 10/11** (with Developer Mode enabled OR administrator privileges)

### Required Hardware
- **Arduino Mega 2560** (Control Panel)
- **Arduino Uno R4** (Fuse Box)
- **Nextion Display** (3.5" or 5" NX4832T035 recommended)
- See [BOM.md](BOM.md) for complete hardware list

---

## ⚙️ Windows Configuration for Symbolic Links

**IMPORTANT:** This repository uses symbolic links to share code between `BoatControlPanel` and `SmartFuseBox` projects. You must configure Windows to handle them properly.

### Option 1: Enable Developer Mode (Recommended)
1. Open **Settings** → **Update & Security** → **For developers**
2. Enable **Developer Mode**
3. Restart your computer
4. Git will now automatically create symbolic links during clone

### Option 2: Use Administrator Privileges
If you cannot enable Developer Mode:
1. Clone the repository normally (symlinks will appear as text files)
2. Run the `SymLinks.bat` scripts manually (see below)

---

## 📥 Cloning the Repository

### With Developer Mode Enabled

Git will automatically create symbolic links during the clone process.

### Without Developer Mode (Admin Required)

After cloning, you **must** manually create symbolic links:

#### For BoatControlPanel:
*(Right-click → "Run as administrator")*

#### For SmartFuseBox:
*(Right-click → "Run as administrator")*

---

## 🔧 Git Configuration

### Enable Symlink Support Globally

### Verify Symlinks After Clone

### If Symlinks Are Missing
1. Delete the text files:
2. Run `SymLinks.bat` as administrator:

---

## 📚 Required Arduino Libraries

Install these libraries via **Arduino IDE Library Manager**:

### Third-Party Libraries
- **SerialCommandManager** (by Si Carter)
- **NextionControl** (custom library - see `NextionControl` folder)
- **DHT sensor library** (by Adafruit)
- **QMC5883LCompass** (for magnetic compass sensor)

### Installation
1. Open Arduino IDE
2. Go to **Sketch** → **Include Library** → **Manage Libraries**
3. Search and install each library

### Custom Libraries
If `NextionControl` is not in the Library Manager:
1. Copy `NextionControl` folder to your Arduino `libraries` directory
2. Restart Arduino IDE

---

## 🏗️ Building the Projects

### BoatControlPanel (Arduino Mega 2560)
1. Open `BoatControlPanel/BoatControlPanel.ino` in Arduino IDE
2. Select **Board**: Arduino Mega 2560
3. Select **Port**: (your COM port)
4. Click **Upload**

### SmartFuseBox (Arduino Uno R4)
1. Open `SmartFuseBox/SmartFuseBox.ino` in Arduino IDE
2. Select **Board**: Arduino Uno R4 WiFi (or R4 Minima)
3. Select **Port**: (your COM port)
4. Click **Upload**

---

## 🔍 Verifying Setup

### Check Symlinks
Run this in `BoatControlPanel` or `SmartFuseBox`:

You should see entries like:

If you see regular text files, symlinks weren't created correctly.

### Check Arduino Compilation
Both projects should compile without errors. Common issues:

- **Missing library errors**: Install required libraries
- **File not found errors**: Symlinks weren't created properly
- **Multiple definition errors**: Ensure you're not including `.cpp` files

---

## 🚨 Troubleshooting

### Symlinks Appear as Text Files After Clone
**Cause**: Git is not configured to create symlinks, or you lack permissions.

**Fix**:
1. Enable Developer Mode (see above)
2. Re-clone the repository OR run `SymLinks.bat` manually

### "ERROR: Failed to create symlink" When Running SymLinks.bat
**Cause**: Not running with administrator privileges.

**Fix**: Right-click `SymLinks.bat` → **Run as administrator**

### Symlinks Disappear After Git Pull
**Cause**: `core.symlinks` is set to `false`.

**Fix**:

### Files Show as Modified in Git After Creating Symlinks
**Cause**: Git thinks symlinks are regular files.

**Fix**:

---

## 📖 Additional Documentation

- [README.md](README.md) - Project overview and features
- [Commands.md](Commands.md) - Serial command protocol reference
- [BOM.md](BOM.md) - Complete bill of materials
- [ExternalUpdatePattern.md](ExternalUpdatePattern.md) - Display page update architecture

---

## 🤝 Contributing

When making changes to shared files:
1. Edit files in the `Shared/` directory only
2. Do **NOT** commit or modify symlinked files directly
3. Test changes in both `BoatControlPanel` and `SmartFuseBox`

---

## 📜 License

GNU General Public License v3.0 (GPLv3) — see [LICENSE](LICENSE) for details.

---

## ❓ Getting Help

If you encounter issues:
1. Check this setup guide thoroughly
2. Review the [README.md](README.md) for project context
3. Open an issue on GitHub with:
   - Your Git configuration (`git config --list | grep symlinks`)
   - Windows version and Developer Mode status
   - Error messages from `SymLinks.bat` or Arduino IDE

---

**Happy building! ⚡🚤**

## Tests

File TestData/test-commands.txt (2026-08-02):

# Smart Fuse Box Test Commands
# Lines starting with # are comments
# Format: COMMAND -> EXPECTED_RESPONSE
# Use | to separate multiple valid responses
# Use * as wildcard for variable content

# ============================================================
# SYSTEM COMMANDS - Query Commands
# ============================================================
F2 -> ACK:F2=ok:v=*
F3 -> ACK:F3=ok:v=*
F4 -> ACK:F4=ok:v=*
F5 -> ACK:F5=ok:v=*
F7 -> ACK:F7=ok:v=*
F8 -> ACK:F8=ok:v=*
F9 -> ACK:F9=ok:v=*
F11 -> ACK:F11=ok:v=*

# Pin Restrictions - compile-time restricted pins (Hard/Advisory)
F16 -> ACK:F16=ok

# RTC Diagnostic - returns status message
F10 -> ACK:F10=ok:*

# OTA Status (SFB only, requires WiFi)
# F13 -> ACK:F13:v=*;av=*;s=*;auto=*

# ============================================================
# SYSTEM COMMANDS - Set Commands
# ============================================================
# Set DateTime (Unix timestamp)
F6:v=1733328600 -> ACK:F6=ok:v=*

# Heartbeat (SFB sends warnings only)
F0:w=0x00 -> ACK:F0=ok

# ============================================================
# CONFIGURATION COMMANDS - Boat Info
# ============================================================
C3:Test Boat -> ACK:C3=ok:*
C3:name=Test Boat 2 -> ACK:C3=ok:*
C21:123456789 -> ACK:C21=ok|ACK:C21=Invalid parameter:*
C22:TEST123 -> ACK:C22=ok:*
C23:Test Port -> ACK:C23=ok:*

# ============================================================
# CONFIGURATION COMMANDS - Vessel Settings
# ============================================================
# Vessel Type: 0=Motor, 1=Sail, 2=Fishing, 3=Yacht
C7:v=0 -> ACK:C7=ok:*
C7:v=1 -> ACK:C7=ok:*
C7:v=2 -> ACK:C7=ok:*
C7:v=3 -> ACK:C7=ok:*

# Timezone offset
C20:v=-5 -> ACK:C20=ok:*
C20:v=0 -> ACK:C20=ok:*
C20:v=8 -> ACK:C20=ok:*

# Sound delay
C9:v=100 -> ACK:C9=ok:*
C9:v=255 -> ACK:C9=ok:*

# ============================================================
# CONFIGURATION COMMANDS - WiFi Settings (PCH)
# ============================================================
C11:v=0 -> ACK:C11=ok:*
C11:v=1 -> ACK:C11=ok:*
C12:v=0 -> ACK:C12=ok:*
C12:v=1 -> ACK:C12=ok:*
C13:TestSSID -> ACK:C13=ok:*
C14:TestPassword -> ACK:C14=ok:*
C15:v=80 -> ACK:C15=ok:*
C15:v=8080 -> ACK:C15=ok:*
C17:192.168.4.1 -> ACK:C17=ok:*

# ============================================================
# CONFIGURATION COMMANDS - Bluetooth Settings (PCH)
# ============================================================
C10:v=0 -> ACK:C10=ok:*|ACK:C10=Bluetooth init failed:*
C10:v=1 -> ACK:C10=ok:*|ACK:C10=Bluetooth init failed:*

# ============================================================
# CONFIGURATION COMMANDS - SPI Settings
# ============================================================
C4:sck=12;mosi=11;miso=13 -> ACK:C4=ok:*
C31:v=4 -> ACK:C31=ok:*
C31:v=8 -> ACK:C31=ok:*
C31:v=12 -> ACK:C31=ok:*

# ============================================================
# CONFIGURATION COMMANDS - LED Settings
# ============================================================
C24:t=0;c=0;r=255;g=50;b=213 -> ACK:C24=ok:*
C24:t=1;c=1;r=100;g=0;b=0 -> ACK:C24=ok:*
C25:t=0;b=75 -> ACK:C25=ok:*
C25:t=1;b=30 -> ACK:C25=ok:*
C26:v=1 -> ACK:C26=ok:*
C26:v=0 -> ACK:C26=ok:*
C27:g=1;w=1;s=1 -> ACK:C27=ok:*
C27:g=0;w=0;s=0 -> ACK:C27=ok:*

# ============================================================
# CONFIGURATION COMMANDS - Control Panel Tones
# ============================================================
C28:t=0;h=400;d=500;p=0;r=0 -> ACK:C28=ok:*
C28:t=1;h=400;d=500;p=2;r=30000 -> ACK:C28=ok:*
C33:v=512 -> ACK:C33=ok:*

# ============================================================
# MQTT CONFIGURATION COMMANDS
# ============================================================
M0:v=0 -> ACK:M0=ok:*
M0:v=1 -> ACK:M0=ok:*
M1:192.168.1.100 -> ACK:M1=ok:*
M2:v=1883 -> ACK:M2=ok:*
M3:testuser -> ACK:M3=ok:*|ACK:M3=Invalid parameter:*
M4:testpass -> ACK:M4=ok:*|ACK:M4=Invalid parameter:*
M5:test_device -> ACK:M5=ok:*
M6:v=0 -> ACK:M6=ok:*
M6:v=1 -> ACK:M6=ok:*
M7:v=60 -> ACK:M7=ok:*
M9:homeassistant -> ACK:M9=ok:*

# MQTT Query Commands
M0 -> ACK:M0=ok:v=*
M1 -> ACK:M1=ok:v=*
M2 -> ACK:M2=ok:v=*
M3 -> ACK:M3=ok:v=*
M4 -> ACK:M4=ok:v=*
M5 -> ACK:M5=ok:v=*
M6 -> ACK:M6=ok:v=*
M7 -> ACK:M7=ok:v=*
M9 -> ACK:M9=ok:v=*
M8 -> ACK:M8=ok:v=*

# ============================================================
# RELAY CONTROL COMMANDS
# ============================================================
R0 -> ACK:R0=ok
R1 -> ACK:R1=ok
R2 -> ACK:R2=ok:*
R3:0=0 -> ACK:R3=ok:*|ACK:R3=Invalid relay index:*
R3:0=1 -> ACK:R3=ok:*|ACK:R3=Invalid relay index:*
R3:7=1 -> ACK:R3=ok:*|ACK:R3=Invalid relay index:*
R4:0 -> ACK:R4=ok:0=*
R4:7 -> ACK:R4=ok:7=*
R5 -> ACK:R5=ok*

# ============================================================
# RELAY CONFIGURATION COMMANDS
# ============================================================
R6:0=Test -> ACK:R6=ok:*
R6:1=Test|Test Name -> ACK:R6=ok:*
R7:0=0 -> ACK:R7=ok:*
R7:1=4 -> ACK:R7=ok:*
R7:2=255 -> ACK:R7=ok:*
R8:0=0 -> ACK:R8=ok:*
R8:1=1 -> ACK:R8=ok:*
R9:0=1 -> ACK:R9=ok:*
R9:0=255 -> ACK:R9=ok:*
R10:0=0 -> ACK:R10=ok:*
R10:1=1 -> ACK:R10=ok:*
R10:2=2 -> ACK:R10=ok:*
R11:0=15 -> ACK:R11=ok:*
R11:7=22 -> ACK:R11=ok:*

# ============================================================
# SENSOR CONFIGURATION COMMANDS
# ============================================================
S0 -> ACK:S0=ok|ACK:S0=ok:*
S1:i=0;t=1;o0=0;o1=0 -> ACK:S1=ok:reboot=1
S2:0 -> ACK:S2=ok:reboot=1
S3:0=Test Sensor -> ACK:S3=ok:reboot=1
S4:i=0;s=0;v=34 -> ACK:S4=ok:reboot=1
S5:0=0 -> ACK:S5=ok:reboot=1
S5:0=1 -> ACK:S5=ok:reboot=1
S6:i=0;s=0;v=1 -> ACK:S6=ok:reboot=1|ACK:S6=Invalid or missing parameters

# ============================================================
# WARNING COMMANDS
# ============================================================
W1 -> ACK:W1=ok:*
W3 -> ACK:W3=ok
W4:0x05=1 -> ACK:W4=ok|ACK:W4=Invalid warning type
W4:0x05=0 -> ACK:W4=ok|ACK:W4=Invalid warning type

# ============================================================
# SOUND SIGNAL COMMANDS (Fog Horn)
# ============================================================
H0 -> ACK:H0=ok
H1 -> ACK:H1=ok:*
H2 -> ACK:H2=ok
H3 -> ACK:H3=ok
H4 -> ACK:H4=ok
H5 -> ACK:H5=ok
H6 -> ACK:H6=ok
H7 -> ACK:H7=ok
H8 -> ACK:H8=ok
H9 -> ACK:H9=ok
H10 -> ACK:H10=ok
H11 -> ACK:H11=ok
H12 -> ACK:H12=ok

# ============================================================
# TIMER/SCHEDULER COMMANDS
# ============================================================
T0 -> T0:count=*
T1:v=0 -> ACK:T1=Slot is empty:*|ACK:T1=ok:*
T2:i=0;e=1;t=1,18,30,0,0;c=0,0,0,0,0;a=2,2,0,0,0 -> ACK:T2=ok
T3:v=0 -> ACK:T3=ok:*
T4:i=0;v=1 -> ACK:T4=ok
T4:i=0;v=0 -> ACK:T4=ok
T5 -> ACK:T5=ok
T6:v=0 -> ACK:T6=ok|ACK:T6=No action defined

# ============================================================
# ERROR RESPONSE TESTS
# ============================================================
# Test invalid parameters
C7:v=99 -> ACK:C7=Invalid parameter:*
C20:v=99 -> ACK:C20=Invalid parameter:*
C21:123 -> ACK:C21=Invalid parameter:*
R3:99=1 -> ACK:R3=Invalid relay index
R7:0=99 -> ACK:R7=Invalid color:*
M2:v=0 -> ACK:M2=Invalid parameter:*

# Test missing parameters
C3 -> ACK:C3=Invalid parameter:*
C7 -> ACK:C7=Invalid parameter:*
C20 -> ACK:C20=Invalid parameter:*

# ============================================================
# CONFIGURATION GET/SAVE/RESET
# ============================================================
# Get all settings (returns multiple commands)
C1 -> C*

# Save settings to EEPROM
C0 -> ACK:C0=ok:*

# Reset all settings
C2 -> ACK:C2=ok:*

# ============================================================
# EXTENDED TESTS - BOUNDARY VALUES
# ============================================================

# Timezone boundaries
C20:v=-12 -> ACK:C20=ok:*
C20:v=14 -> ACK:C20=ok:*
C20:v=-13 -> ACK:C20=Invalid parameter:*
C20:v=15 -> ACK:C20=Invalid parameter:*

# LED Brightness boundaries
C25:t=0;b=0 -> ACK:C25=ok:*
C25:t=0;b=100 -> ACK:C25=ok:*
C25:t=0;b=101 -> ACK:C25=Invalid parameter:*
C25:t=1;b=50 -> ACK:C25=ok:*

# LED Type boundaries
C24:t=0;c=0;r=0;g=0;b=0 -> ACK:C24=ok:*
C24:t=0;c=0;r=255;g=255;b=255 -> ACK:C24=ok:*
C24:t=2;c=0;r=255;g=0;b=0 -> ACK:C24=Invalid parameter:*
C24:t=0;c=2;r=255;g=0;b=0 -> ACK:C24=Invalid parameter:*

# Relay color boundaries (0-5 valid, 255 clear)
R7:0=0 -> ACK:R7=ok:*
R7:0=5 -> ACK:R7=ok:*
R7:0=6 -> ACK:R7=Invalid color:*

# WiFi Port boundaries
C15:v=1 -> ACK:C15=ok:*
C15:v=65535 -> ACK:C15=ok:*

# MQTT Port boundaries
M2:v=1 -> ACK:M2=ok:*
M2:v=65535 -> ACK:M2=ok:*

# MQTT Keep Alive boundaries
M7:v=1 -> ACK:M7=ok:*
M7:v=3600 -> ACK:M7=ok:*

# ============================================================
# EXTENDED TESTS - ALL SENSOR TYPES
# ============================================================

# Sensor Type 0: Water Sensor
S1:i=0;t=0;o0=0;o1=0 -> ACK:S1=ok:reboot=1

# Sensor Type 1: Dht11 (already tested)

# Sensor Type 2: Light Sensor (digital mode)
S1:i=1;t=2;o0=1;o1=0 -> ACK:S1=ok:reboot=1

# Sensor Type 3: System Sensor
S1:i=2;t=3;o0=0;o1=0 -> ACK:S1=ok:reboot=1

# Sensor Type 5: Binary Presence Sensor
S1:i=3;t=5;o0=1;o1=0 -> ACK:S1=ok:reboot=1

# Remove all test sensors
S2:0 -> ACK:S2=ok:reboot=1
S2:1 -> ACK:S2=ok:reboot=1
S2:2 -> ACK:S2=ok:reboot=1
S2:3 -> ACK:S2=ok:reboot=1

# ============================================================
# EXTENDED TESTS - HOME BUTTON MAPPING
# ============================================================

# Map home buttons to relays
C5:0=0 -> ACK:C5=ok:*
C5:1=1 -> ACK:C5=ok:*
C5:2=2 -> ACK:C5=ok:*
C5:3=3 -> ACK:C5=ok:*

# Unmap home buttons
C5:0=255 -> ACK:C5=ok:*
C5:1=255 -> ACK:C5=ok:*

# Invalid slot (only 0-3 valid for HOME_BUTTONS)
C5:4=0 -> ACK:C5=Invalid parameter:*|ACK:C5=Button out of range

# Invalid relay (0-7 or 255 only)
C5:0=8 -> ACK:C5=Invalid parameter:*|ACK:C5=Relay out of range

# ============================================================
# EXTENDED TESTS - CONTROL PANEL TONE PRESETS
# ============================================================

# Preset 0: Custom tone
C28:t=0;h=1000;d=250;p=0;r=0 -> ACK:C28=ok:*

# Preset 1: Submarine ping
C28:t=0;h=0;d=0;p=1;r=0 -> ACK:C28=ok:*

# Preset 2: Double beep
C28:t=0;h=0;d=0;p=2;r=0 -> ACK:C28=ok:*

# Preset 3: Rising chirp
C28:t=0;h=0;d=0;p=3;r=0 -> ACK:C28=ok:*

# Preset 4: Descending alert
C28:t=0;h=0;d=0;p=4;r=0 -> ACK:C28=ok:*

# Preset 5: Nautical bell
C28:t=0;h=0;d=0;p=5;r=0 -> ACK:C28=ok:*

# Preset 0xFF: No sound
C28:t=0;h=0;d=0;p=255;r=0 -> ACK:C28=ok:*

# Bad tone with repeat interval
C28:t=1;h=400;d=500;p=0;r=30000 -> ACK:C28=ok:*

# ============================================================
# EXTENDED TESTS - STRING EDGE CASES
# ============================================================

# Long boat name (should be truncated)
C3:VeryLongBoatNameThatExceedsMaximumAllowedLength -> ACK:C3=ok:*

# Long call sign (should be truncated)
C22:VERYLONGCALLSIGN123 -> ACK:C22=ok:*

# Long home port (should be truncated)
C23:Very Long Home Port Name That Exceeds Maximum -> ACK:C23=ok:*

# Boat name with special characters
C3:Boat-Name -> ACK:C3=ok:*

# WiFi SSID with spaces
C13:SSID With Spaces -> ACK:C13=ok:*

# MQTT Device ID with underscores
M5:device_id_test -> ACK:M5=ok:*

# ============================================================
# EXTENDED TESTS - RELAY ACTION TYPES
# ============================================================

# Test all relay action types (0=Default, 1=Horn, 2=NightRelay)
R10:0=0 -> ACK:R10=ok:*
R10:1=0 -> ACK:R10=ok:*
R10:2=1 -> ACK:R10=ok:*
R10:3=0 -> ACK:R10=ok:*
R10:4=2 -> ACK:R10=ok:*
R10:5=0 -> ACK:R10=ok:*

# Invalid action type
R10:0=3 -> ACK:R10=Invalid parameter:*

# ============================================================
# EXTENDED TESTS - TIMER/SCHEDULER COMPREHENSIVE
# ============================================================

# Trigger Type 1: TimeOfDay (hour, minute)
T2:i=0;e=1;t=1,18,30,0,0;c=0,0,0,0,0;a=2,2,0,0,0 -> ACK:T2=ok

# Trigger Type 2: Sunrise with offset (+10 minutes)
T2:i=1;e=1;t=2,10,0,0,0;c=0,0,0,0,0;a=1,0,0,0,0 -> ACK:T2=ok

# Trigger Type 3: Sunset with offset (-10 minutes)
T2:i=2;e=1;t=3,246,255,0,0;c=0,0,0,0,0;a=1,1,0,0,0 -> ACK:T2=ok

# Trigger Type 4: Interval (every 30 minutes)
T2:i=3;e=1;t=4,30,0,0,0;c=0,0,0,0,0;a=1,2,0,0,0 -> ACK:T2=ok

# Trigger Type 5: DayOfWeek (Monday-Friday = 31)
T2:i=4;e=1;t=5,31,0,0,0;c=0,0,0,0,0;a=1,3,0,0,0 -> ACK:T2=ok

# Trigger Type 6: Date (December 25)
T2:i=5;e=1;t=6,25,12,0,0;c=0,0,0,0,0;a=1,4,0,0,0 -> ACK:T2=ok

# Condition Type 1: TimeWindow (9:00-17:00)
T2:i=6;e=1;t=1,12,0,0,0;c=1,9,0,17,0;a=1,5,0,0,0 -> ACK:T2=ok

# Condition Type 2: DayOfWeek in condition (weekends = 96)
T2:i=7;e=1;t=1,12,0,0,0;c=2,96,0,0,0;a=1,6,0,0,0 -> ACK:T2=ok

# Condition Type 3: IsDark
T2:i=8;e=1;t=1,20,0,0,0;c=3,0,0,0,0;a=1,7,0,0,0 -> ACK:T2=ok

# Condition Type 4: IsDaylight
T2:i=9;e=1;t=1,12,0,0,0;c=4,0,0,0,0;a=2,0,0,0,0 -> ACK:T2=ok

# Condition Type 5: RelayIsOn (relay 0)
T2:i=10;e=1;t=1,12,0,0,0;c=5,0,0,0,0;a=2,1,0,0,0 -> ACK:T2=ok

# Condition Type 6: RelayIsOff (relay 1)
T2:i=11;e=1;t=1,12,0,0,0;c=6,1,0,0,0;a=2,2,0,0,0 -> ACK:T2=ok

# Action Type 3: RelayToggle (relay 3)
T2:i=12;e=1;t=1,12,0,0,0;c=0,0,0,0,0;a=3,3,0,0,0 -> ACK:T2=ok

# Action Type 4: RelayPulse (relay 4, 10 seconds)
T2:i=13;e=1;t=1,12,0,0,0;c=0,0,0,0,0;a=4,4,10,0,0 -> ACK:T2=ok

# Action Type 5: AllRelaysOn
T2:i=14;e=1;t=1,12,0,0,0;c=0,0,0,0,0;a=5,0,0,0,0 -> ACK:T2=ok

# Action Type 6: AllRelaysOff
T2:i=15;e=1;t=1,12,0,0,0;c=0,0,0,0,0;a=6,0,0,0,0 -> ACK:T2=ok

# Action Type 7: SetPinHigh (GPIO 15)
T2:i=16;e=1;t=1,12,0,0,0;c=0,0,0,0,0;a=7,15,0,0,0 -> ACK:T2=ok

# Action Type 8: SetPinLow (GPIO 15)
T2:i=17;e=1;t=1,12,0,0,0;c=0,0,0,0,0;a=8,15,0,0,0 -> ACK:T2=ok

# Enable/disable specific events
T4:i=0;v=1 -> ACK:T4=ok
T4:i=0;v=0 -> ACK:T4=ok

# Get specific event details
T1:v=0 -> ACK:T1=ok:*|ACK:T1=Slot is empty:*

# Delete specific event
T3:v=0 -> ACK:T3=ok:*

# ============================================================
# EXTENDED TESTS - SEQUENTIAL VALIDATION
# ============================================================

# Set vessel type and verify
C7:v=2 -> ACK:C7=ok:*
C7 -> ACK:C7=ok:v=2

# Set timezone and verify
C20:v=-5 -> ACK:C20=ok:*
C20 -> ACK:C20=ok:v=-5

# Set MQTT enabled and verify
M0:v=1 -> ACK:M0=ok:*
M0 -> ACK:M0=ok:v=1

# Set relay state and verify
R3:0=1 -> ACK:R3=ok:*|ACK:R3=Invalid relay index:*
R4:0 -> ACK:R4=ok:0=*

# Set relay default state and verify through R5
R8:0=1 -> ACK:R8=ok:*
R5 -> ACK:R5=ok*

# ============================================================
# EXTENDED TESTS - ALL VESSEL TYPES
# ============================================================

# Vessel type 0: Motor
C7:v=0 -> ACK:C7=ok:*

# Vessel type 1: Sail
C7:v=1 -> ACK:C7=ok:*

# Vessel type 2: Fishing
C7:v=2 -> ACK:C7=ok:*

# Vessel type 3: Yacht
C7:v=3 -> ACK:C7=ok:*

# Invalid vessel type
C7:v=4 -> ACK:C7=Invalid parameter:*

# ============================================================
# EXTENDED TESTS - LED CONFIGURATION COMPLETE
# ============================================================

# Day mode, Good colorset, RGB values
C24:t=0;c=0;r=0;g=255;b=0 -> ACK:C24=ok:*

# Day mode, Bad colorset, RGB values
C24:t=0;c=1;r=255;g=0;b=0 -> ACK:C24=ok:*

# Night mode, Good colorset, dimmed
C24:t=1;c=0;r=0;g=100;b=0 -> ACK:C24=ok:*

# Night mode, Bad colorset, dimmed
C24:t=1;c=1;r=100;g=0;b=0 -> ACK:C24=ok:*

# Invalid type (only 0=day, 1=night)
C24:t=2;c=0;r=255;g=0;b=0 -> ACK:C24=Invalid parameter:*

# Invalid colorset (only 0=good, 1=bad)
C24:t=0;c=2;r=255;g=0;b=0 -> ACK:C24=Invalid parameter:*

# LED Auto Switch enabled
C26:v=1 -> ACK:C26=ok:*
C26:v=true -> ACK:C26=ok:*

# LED Auto Switch disabled
C26:v=0 -> ACK:C26=ok:*
C26:v=false -> ACK:C26=ok:*

# LED Enable all
C27:g=1;w=1;s=1 -> ACK:C27=ok:*
C27:g=true;w=true;s=true -> ACK:C27=ok:*

# LED Disable all
C27:g=0;w=0;s=0 -> ACK:C27=ok:*
C27:g=false;w=false;s=false -> ACK:C27=ok:*

# LED mixed state
C27:g=1;w=0;s=1 -> ACK:C27=ok:*

# ============================================================
# EXTENDED TESTS - SOUND DELAY BOUNDARIES
# ============================================================

C9:v=0 -> ACK:C9=ok:*
C9:v=50 -> ACK:C9=ok:*
C9:v=100 -> ACK:C9=ok:*
C9:v=255 -> ACK:C9=ok:*

# ============================================================
# EXTENDED TESTS - LIGHT SENSOR THRESHOLD
# ============================================================

C33:v=0 -> ACK:C33=ok:*
C33:v=256 -> ACK:C33=ok:*
C33:v=512 -> ACK:C33=ok:*
C33:v=768 -> ACK:C33=ok:*
C33:v=1023 -> ACK:C33=ok:*
C33:v=1024 -> ACK:C33=Invalid parameter:*

# ============================================================
# EXTENDED TESTS - SD CARD INITIALIZATION SPEEDS
# ============================================================

C31:v=4 -> ACK:C31=ok:*
C31:v=8 -> ACK:C31=ok:*
C31:v=12 -> ACK:C31=ok:*
C31:v=16 -> ACK:C31=ok:*
C31:v=20 -> ACK:C31=ok:*
C31:v=24 -> ACK:C31=ok:*
C31:v=5 -> ACK:C31=Invalid parameter:*

# ============================================================
# EXTENDED TESTS - RELAY LINKING COMPREHENSIVE
# ============================================================

# Link relay 0 to relay 1
R9:0=1 -> ACK:R9=ok:*

# Link relay 2 to relay 3
R9:2=3 -> ACK:R9=ok:*

# Unlink relay 0
R9:0=255 -> ACK:R9=ok:*

# Invalid linked relay
R9:0=8 -> ACK:R9=Invalid parameter:*|ACK:R9=No available link slots

# ============================================================
# EXTENDED TESTS - OTA FIRMWARE COMMANDS (SFB only)
# ============================================================

# Check OTA status (requires WiFi enabled and ESP32)
# F13 -> ACK:F13=ok:v=*;av=*;s=*;auto=*

# Check for OTA update without applying
# F12 -> ACK:F12=ok:v=*;av=*;s=*
# F12:apply=0 -> ACK:F12=ok:v=*;av=*;s=*

# Check and apply OTA update
# F12:apply=1 -> ACK:F12=ok:v=*;av=*;s=*

# ============================================================
# EXTENDED TESTS - MMSI VALIDATION
# ============================================================

# Valid MMSI (exactly 9 digits)
C21:123456789 -> ACK:C21=ok|ACK:C21=Invalid parameter:*
C21:000000000 -> ACK:C21=ok|ACK:C21=Invalid parameter:*
C21:999999999 -> ACK:C21=ok|ACK:C21=Invalid parameter:*

# Invalid MMSI (not 9 digits)
C21:12345678 -> ACK:C21=Invalid parameter:*
C21:1234567890 -> ACK:C21=Invalid parameter:*

# ============================================================
# EXTENDED TESTS - SENSOR PIN AND OPTION CONFIGURATION
# ============================================================

# Set sensor pin slot 0
S4:i=0;s=0;v=34 -> ACK:S4=ok:reboot=1

# Set sensor pin slot 1
S4:i=0;s=1;v=35 -> ACK:S4=ok:reboot=1

# Clear sensor pin (255 = PinDisabled)
S4:i=0;s=0;v=255 -> ACK:S4=ok:reboot=1

# Set sensor option
S6:i=0;s=0;v=1 -> ACK:S6=ok:reboot=1|ACK:S6=Invalid or missing parameters

# Invalid sensor index
S4:i=10;s=0;v=34 -> ACK:S4=Invalid sensor index|ACK:S4=Invalid parameter:*

# Invalid pin slot
S4:i=0;s=5;v=34 -> ACK:S4=Invalid parameter:*|ACK:S4=Invalid pin slot

# ============================================================
# EXTENDED TESTS - WIFI AP MODE
# ============================================================

# Set to AP mode
C12:v=0 -> ACK:C12=ok:*

# Set AP IP address
C17:192.168.4.1 -> ACK:C17=ok:*
C17:10.0.0.1 -> ACK:C17=ok:*

# Set back to Client mode
C12:v=1 -> ACK:C12=ok:*

# ============================================================
# EXTENDED TESTS - MQTT DISCOVERY PREFIX
# ============================================================

M9:homeassistant -> ACK:M9=ok:*
M9:myboat -> ACK:M9=ok:*
M9:custom_prefix -> ACK:M9=ok:*

# ============================================================
# EXTENDED TESTS - ALL BUTTON COLORS
# ============================================================

# BTN_COLOR_BLUE = 0
R7:0=0 -> ACK:R7=ok:*

# BTN_COLOR_GREEN = 1
R7:1=1 -> ACK:R7=ok:*

# BTN_COLOR_ORANGE = 2
R7:2=2 -> ACK:R7=ok:*

# BTN_COLOR_PINK = 3
R7:3=3 -> ACK:R7=ok:*

# BTN_COLOR_RED = 4
R7:4=4 -> ACK:R7=ok:*

# BTN_COLOR_YELLOW = 5
R7:5=5 -> ACK:R7=ok:*

# Clear color (255)
R7:6=255 -> ACK:R7=ok:*

# Invalid color
R7:7=6 -> ACK:R7=Invalid color:*

# ============================================================
# XPDZ TONE PIN CONFIGURATION (C6)
# ============================================================

# Set XpdzTone pin to a valid GPIO
C6:v=25 -> ACK:C6=ok:*
C6:v=26 -> ACK:C6=ok:*

# Set XpdzTone pin to PinDisabled (255 = not fitted)
C6:v=255 -> ACK:C6=ok:*

# Missing parameter
C6 -> ACK:C6=Invalid parameter:*

# Verify C1 includes C6
C1 -> C*

# ============================================================
# HW479 RGB LED PIN CONFIGURATION (C8)
# ============================================================

# Set all three RGB pins
C8:r=25;g=26;b=27 -> ACK:C8=ok:*
C8:r=16;g=17;b=18 -> ACK:C8=ok:*

# Disable all pins (PinDisabled = 255)
C8:r=255;g=255;b=255 -> ACK:C8=ok:*

# Mixed: some disabled, some active
C8:r=25;g=255;b=255 -> ACK:C8=ok:*

# Missing parameter(s)
C8:r=25;g=26 -> ACK:C8=Invalid parameter:*
C8 -> ACK:C8=Invalid parameter:*

# ============================================================
# RTC DS1302 PIN CONFIGURATION (C18)
# ============================================================

# Set all three DS1302 pins
C18:dat=4;clk=5;rst=6 -> ACK:C18=ok:*
C18:dat=14;clk=15;rst=16 -> ACK:C18=ok:*

# Disable all pins (PinDisabled = 255)
C18:dat=255;clk=255;rst=255 -> ACK:C18=ok:*

# Mixed: some disabled
C18:dat=4;clk=255;rst=255 -> ACK:C18=ok:*

# Missing parameter(s)
C18:dat=4;clk=5 -> ACK:C18=Invalid parameter:*
C18 -> ACK:C18=Invalid parameter:*

# ============================================================
# NEXTION DISPLAY CONFIGURATION (N0-N6)
# ============================================================

# Get all Nextion config (returns N1-N6 values then ACK)
N0 -> ACK:N0=ok

# N1: Enable/disable Nextion display
N1:v=1 -> ACK:N1=ok:*
N1:v=0 -> ACK:N1=ok:*
N1:v=true -> ACK:N1=ok:*
N1:v=false -> ACK:N1=ok:*

# Missing parameter
N1 -> ACK:N1=Invalid parameter:*

# N2: Hardware serial vs software serial
N2:v=1 -> ACK:N2=ok:*
N2:v=0 -> ACK:N2=ok:*

# Missing parameter
N2 -> ACK:N2=Invalid parameter:*

# N3: RX pin (255 = PinDisabled)
N3:v=16 -> ACK:N3=ok:*
N3:v=255 -> ACK:N3=ok:*

# Missing parameter
N3 -> ACK:N3=Invalid parameter:*

# N4: TX pin (255 = PinDisabled)
N4:v=17 -> ACK:N4=ok:*
N4:v=255 -> ACK:N4=ok:*

# Missing parameter
N4 -> ACK:N4=Invalid parameter:*

# N5: Baud rate (common values)
N5:v=9600 -> ACK:N5=ok:*
N5:v=115200 -> ACK:N5=ok:*
N5:v=921600 -> ACK:N5=ok:*

# Missing parameter
N5 -> ACK:N5=Invalid parameter:*

# N6: UART number (only 1 or 2 are valid; UART0 reserved)
N6:v=1 -> ACK:N6=ok:*
N6:v=2 -> ACK:N6=ok:*

# Invalid UART number
N6:v=0 -> ACK:N6=Invalid parameter:*
N6:v=3 -> ACK:N6=Invalid parameter:*

# Missing parameter
N6 -> ACK:N6=Invalid parameter:*

# ============================================================
# EXTERNAL / REMOTE SENSOR CONFIGURATION (E0-E4)
# ============================================================

# E0: Get all external sensor config entries
E0 -> ACK:E0=ok:*

# E1: Set core fields for a new external sensor
E1:i=0;id=7;n=TempSensor;mn=temperature;ms=temp -> ACK:E1=ok:reboot=1

# E1: Add a second sensor
E1:i=1;id=8;n=HumSensor;mn=humidity;ms=hum -> ACK:E1=ok:reboot=1

# E2: Set MQTT detail fields (sensor must exist first via E1)
E2:i=0;mt=sensor;md=temperature;mu=C;bin=0 -> ACK:E2=ok:reboot=1
E2:i=1;mt=sensor;md=humidity;mu=%;bin=0 -> ACK:E2=ok:reboot=1

# E2: Binary sensor
E2:i=0;mt=binary_sensor;md=motion;mu=;bin=1 -> ACK:E2=ok:reboot=1

# E4: Rename an existing sensor
E4:0=Outside Temp -> ACK:E4=ok:reboot=1

# E3: Remove sensor at index 1
E3:v=1 -> ACK:E3=ok:reboot=1

# E3: Remove sensor at index 0
E3:v=0 -> ACK:E3=ok:reboot=1
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

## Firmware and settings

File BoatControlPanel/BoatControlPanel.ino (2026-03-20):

/*
 * SmartFuseBox
 * Copyright (C) 2025 Simon Carter (s1cart3r@gmail.com)
 *
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
 * You should have received a copy of the GNU General Public License
 * along with this program. If not, see <https://www.gnu.org/licenses/>.
 */
#include <Arduino.h>
#include <SerialCommandManager.h>
#include <NextionControl.h>
#include <SensorManager.h>

#include "Local.h"

#if defined(ARDUINO_R4_MINIMA)
#include <SoftwareSerial.h>
#endif

#include "BoatControlPanelConstants.h"
#include "BroadcastManager.h"
#include "InterceptDebugCommandHandler.h"
#include "AckCommandHandler.h"
#include "ConfigCommandHandler.h"
#include "SensorCommandHandler.h"
#include "WarningCommandHandler.h"
#include "SystemCommandHandler.h"
#include "SystemCpuMonitor.h"
#include "DateTimeManager.h"
#include "SunCalculator.h"

#include "SplashPage.h"
#include "HomePage.h"
#include "WarningType.h"
#include "WarningPage.h"
#include "SystemPage.h"
#include "RelayPage.h"
#include "SoundSignalsPage.h"
#include "SoundOvertakingPage.h"
#include "SoundFogPage.h"
#include "SoundManeuveringPage.h"
#include "SoundEmergencyPage.h"
#include "SoundOtherPage.h"
#include "FlagsPage.h"
#include "CardinalMarkersPage.h"
#include "BuoysPage.h"
#include "MoonPhasePage.h"
#include "VhfRadioPage.h"
#include "VhfChannelsPage.h"
#include "VhfDistressPage.h"
#include "SettingsPage.h"
#include "RelaySettingsPage.h"
#include "EnvironmentPage.h"
#include "AboutPage.h"

#include "Config.h"
#include "ConfigManager.h"
#include "WarningManager.h"
#include "ToneManager.h"
#include "RgbLedFade.h"

#include "GpsSensorHandler.h"

#if defined(SCREEN_DEMO_SUPPORT)
#include "ScreenDemoHandler.h"
#endif

#if defined(ARDUINO_MEGA2560)
#define NEXTION_SERIAL Serial1
#define LINK_SERIAL Serial2
#define GPS_SERIAL Serial3
#elif defined(ARDUINO_R4_MINIMA)
SoftwareSerial LINK_SERIAL(2, 3); // RX, TX
SoftwareSerial NEXTION_SERIAL(4, 5); // RX, TX
#else
#error "You must define 'ARDUINO_MEGA2560' or 'ARDUINO_R4_MINIMA'"
#endif


#define COMPUTER_SERIAL Serial


constexpr unsigned long UpdateIntervalMs = 600;

// forward declares
void onLinkCommandReceived(SerialCommandManager* mgr);
void onComputerCommandReceived(SerialCommandManager* mgr);

// sound
ToneManager toneManager(PinTone);

// led indicators
RgbLedFade systemLedStatus(PinRgbRed, PinRgbGreen, PinRgbBlue);

// Serial managers
SerialCommandManager commandMgrComputer(&COMPUTER_SERIAL, onComputerCommandReceived, '\n', ':', ';', '=', 512, 64);
SerialCommandManager commandMgrLink(&LINK_SERIAL, onLinkCommandReceived, '\n', ':', ';', '=', 1024, 64);

// Broadcast manager for coordinated messaging
BroadcastManager broadcastManager(&commandMgrComputer, &commandMgrLink);

// Warning manager with heartbeat monitoring
WarningManager warningManager(&commandMgrLink, HeartbeatIntervalMs, HeartbeatTimeoutMs, &systemLedStatus, &toneManager);

// Nextion display setup
SplashPage splashPage(&NEXTION_SERIAL);
HomePage homePage(&NEXTION_SERIAL, &warningManager, &commandMgrLink, &commandMgrComputer);
WarningPage warningPage(&NEXTION_SERIAL, &warningManager, &commandMgrLink, &commandMgrComputer);
RelayPage relayPage(&NEXTION_SERIAL, &warningManager, &commandMgrLink, &commandMgrComputer);
SoundSignalsPage soundSignalsPage(&NEXTION_SERIAL, &warningManager, &commandMgrLink, &commandMgrComputer);
SoundOvertakingPage soundOvertakingPage(&NEXTION_SERIAL, &warningManager, &commandMgrLink, &commandMgrComputer);
SoundFogPage soundFogPage(&NEXTION_SERIAL, &warningManager, &commandMgrLink, &commandMgrComputer);
SoundManeuveringPage soundManeuveringPage(&NEXTION_SERIAL, &warningManager, &commandMgrLink, &commandMgrComputer);
SoundEmergencyPage soundEmergencyPage(&NEXTION_SERIAL, &warningManager, &commandMgrLink, &commandMgrComputer);
SoundOtherPage soundOtherPage(&NEXTION_SERIAL, &warningManager, &commandMgrLink, &commandMgrComputer);
SystemPage systemPage(&NEXTION_SERIAL, &warningManager, &commandMgrLink, &commandMgrComputer);
FlagsPage flagsPage(&NEXTION_SERIAL, &warningManager, &commandMgrLink, &commandMgrComputer);
CardinalMarkersPage cardinalMarkersPage(&NEXTION_SERIAL, &warningManager, &commandMgrLink, &commandMgrComputer);
BuoysPage buoysPage(&NEXTION_SERIAL, &warningManager, &commandMgrLink, &commandMgrComputer);
MoonPhasePage moonPhasePage(&NEXTION_SERIAL, &warningManager, &commandMgrLink, &commandMgrComputer);
VhfRadioPage radioPage(&NEXTION_SERIAL, &warningManager, &commandMgrLink, &commandMgrComputer);
VhfDistressPage radioPageDistress(&NEXTION_SERIAL, &warningManager, &commandMgrLink, &commandMgrComputer);
VhfChannelsPage radioPageChannels(&NEXTION_SERIAL, &warningManager, &commandMgrLink, &commandMgrComputer);
SettingsPage settingsPage(&NEXTION_SERIAL, &warningManager, &commandMgrLink, &commandMgrComputer);
RelaySettingsPage relaySettingsPage(&NEXTION_SERIAL, &warningManager, &commandMgrLink, &commandMgrComputer);
EnvironmentPage environmentPage(&NEXTION_SERIAL, &warningManager, &commandMgrLink, &commandMgrComputer);
AboutPage aboutPage(&NEXTION_SERIAL);

BaseDisplayPage* displayPages[] = { &splashPage, &homePage, &warningPage, &relayPage, &soundSignalsPage, 
    &soundOvertakingPage, &soundFogPage, &soundManeuveringPage, &soundEmergencyPage, &soundOtherPage,
    &systemPage, &flagsPage, & cardinalMarkersPage, &buoysPage, &moonPhasePage, &radioPage, 
    &radioPageDistress, &radioPageChannels, &relaySettingsPage, &settingsPage, &environmentPage,
    &aboutPage };
NextionControl nextion(&NEXTION_SERIAL, displayPages, sizeof(displayPages) / sizeof(displayPages[0]));

#if defined(SCREEN_DEMO_SUPPORT)
ScreenDemoHandler screenDemoHandler(&nextion, sizeof(displayPages) / sizeof(displayPages[0]));
#endif

// link command handlers
InterceptDebugHandler interceptDebugHandler(&broadcastManager);
SensorCommandHandler sensorCommandHandler(&broadcastManager, &nextion, &warningManager);
WarningCommandHandler warningCommandHandler(&broadcastManager, &nextion, &warningManager);

// computer command handlers
ConfigCommandHandler configHandler(&broadcastManager, &homePage);

// shared command handlers
AckCommandHandler ackHandler(&broadcastManager, &nextion, &warningManager);
SystemCommandHandler systemCommandHandler(&broadcastManager, &warningManager);

// sensors
//TLVCompassHandler compass(&commandMgrComputer, 5);

GpsSensorHandler gpsSensor(&GPS_SERIAL, &broadcastManager, &sensorCommandHandler, &warningManager);

BaseSensorHandler* sensorHandlers[] = {
    &gpsSensor
};
uint8_t sensorHandlerCount = sizeof(sensorHandlers) / sizeof(sensorHandlers[0]);
SensorManager sensorManager(sensorHandlers, sensorHandlerCount);

// Timers
unsigned long lastUpdate = 0;

void setup()
{
    systemLedStatus.begin();
    systemLedStatus.setFadeSpeed(0.008f);
    systemLedStatus.setMaxBrightness(60);
    systemLedStatus.setMinBrightness(10);
    systemLedStatus.setWarning(false);
    systemLedStatus.setDayTime(true); // Start in day mode
    systemLedStatus.setColor(120, 0, 180);
    systemLedStatus.update(0);

    DateTimeManager::begin();

    ISerialCommandHandler* linkHandlers[] = { &interceptDebugHandler, &ackHandler, &sensorCommandHandler,
        &warningCommandHandler, &systemCommandHandler, &configHandler };
    size_t linkHandlerCount = sizeof(linkHandlers) / sizeof(linkHandlers[0]);
    commandMgrLink.registerHandlers(linkHandlers, linkHandlerCount);

    ISerialCommandHandler* computerHandlers[] = { &configHandler, &ackHandler, &sensorCommandHandler, 
        &warningCommandHandler, &systemCommandHandler
#if defined(SCREEN_DEMO_SUPPORT)
        , &screenDemoHandler
#endif
        };
    size_t computerHandlerCount = sizeof(computerHandlers) / sizeof(computerHandlers[0]);
    commandMgrComputer.registerHandlers(computerHandlers, computerHandlerCount);

    SystemFunctions::initializeSerial(COMPUTER_SERIAL, BaudRateComputer, true);

#if defined(ARDUINO_MEGA2560)
    SystemFunctions::initializeSerial(NEXTION_SERIAL, BaudRateDefault, false);
    SystemFunctions::initializeSerial(LINK_SERIAL, BaudRateDefault, false);
	SystemFunctions::initializeSerial(GPS_SERIAL, BaudRateGps, false);
#elif defined(ARDUINO_R4_MINIMA)
	NEXTION_SERIAL.begin(BaudRateDefault);
	LINK_SERIAL.begin(BaudRateDefault);
	GPS_SERIAL.begin(BaudRateGps);
#endif

#if defined(NEXTION_DEBUG)
    nextion.setDebugCallback([](const String& msg)
    {
        commandMgrComputer.sendCommand(msg.c_str(), "NEXTION");
    });
#endif

    // retrieve config settings
    ConfigManager::begin();

    if (!ConfigManager::load())
    {
        warningManager.raiseWarning(WarningType::DefaultConfigurationControlPanel);
    }

    Config* config = ConfigManager::getConfigPtr();
    DateTimeManager::setTimezoneOffset(config->system.timezoneOffset);
    homePage.configSet(config);
    warningPage.configSet(config);
	relayPage.configSet(config);
    radioPage.configSet(config);
	radioPageDistress.configSet(config);
    settingsPage.configSet(config);
	relaySettingsPage.configSet(config);
	environmentPage.configSet(config);
	systemLedStatus.configSet(config);
	toneManager.configSet(&config->sound);

	systemLedStatus.setDayTime(true);

	nextion.begin();

	sensorManager.setup();

	char buffer[20];
	snprintf_P(buffer, sizeof(buffer), PSTR("v=%u"), config->sound.hornRelayIndex);
	broadcastManager.sendCommand(ConfigSoundRelayId, buffer);
	snprintf_P(buffer, sizeof(buffer), PSTR("v=%u"), static_cast<uint8_t>(config->vessel.vesselType));
	broadcastManager.sendCommand(ConfigBoatType, buffer);

	if (DateTimeManager::isTimeSet())
	{
		snprintf_P(buffer, sizeof(buffer), PSTR("v=%lu"), DateTimeManager::getCurrentTime());
		broadcastManager.sendCommand(SystemSetDateTime, buffer);
	}

	broadcastManager.sendCommand(SystemInitialized, "");

	nextion.sendCommand(PageOne);
	toneManager.play(ToneType::Good);
}

void loop()
{
    unsigned long now = millis();

    SystemCpuMonitor::startTask();
    commandMgrComputer.readCommands();
    SystemCpuMonitor::endTask();

    SystemCpuMonitor::startTask();
    commandMgrLink.readCommands();
    SystemCpuMonitor::endTask();

    SystemCpuMonitor::startTask();
    nextion.update(now);
    SystemCpuMonitor::endTask();

    SystemCpuMonitor::startTask();
    warningManager.update(now);
    SystemCpuMonitor::endTask();

    SystemCpuMonitor::startTask();
    broadcastManager.update(now);
    SystemCpuMonitor::endTask();

    SystemCpuMonitor::startTask();
    sensorManager.update(now);
    SystemCpuMonitor::endTask();

    SystemCpuMonitor::startTask();
    systemLedStatus.update(now);
    SystemCpuMonitor::endTask();

    SystemCpuMonitor::startTask();
    toneManager.update(now);
    SystemCpuMonitor::endTask();

    SystemCpuMonitor::update();
}

void onLinkCommandReceived(SerialCommandManager* mgr)
{
    char cmd[64];
	snprintf_P(cmd, sizeof(cmd), PSTR("%s"), mgr->getCommand());
    commandMgrComputer.sendError(cmd, F("LINKHANDLER"));

	// Reset serial to clear any residual data
	SystemFunctions::resetSerial(LINK_SERIAL);
}

void onComputerCommandReceived(SerialCommandManager* mgr)
{
    char cmd[64];
	snprintf_P(cmd, sizeof(cmd), PSTR("%s"), mgr->getCommand());

    commandMgrComputer.sendError(cmd, F("PCHANDLER"));

    // Reset serial to clear any residual data
    SystemFunctions::resetSerial(COMPUTER_SERIAL);
}

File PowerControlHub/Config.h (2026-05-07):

/*
 * PowerControlHub
 * Copyright (C) 2025 Simon Carter (s1cart3r@gmail.com)
 *
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
 * You should have received a copy of the GNU General Public License
 * along with this program. If not, see <https://www.gnu.org/licenses/>.
 */
#pragma once
#include <Arduino.h>
#include <stdint.h>

#include "SystemDefinitions.h"
#include "Local.h"


constexpr uint8_t ConfigMaxScheduledEvents = MAXIMUM_EVENTS;
constexpr uint8_t ConfigSchedulerPayloadSize = 4;
constexpr uint8_t ConfigScheduleEventReserved = 8;
constexpr uint8_t ConfigSchedulerReservedSize = 10;

// MQTT Configuration
constexpr uint8_t ConfigMqttBrokerLength = 64;
constexpr uint8_t ConfigMqttUsernameLength = 32;
constexpr uint8_t ConfigMqttPasswordLength = 32;
constexpr uint8_t ConfigMqttDeviceIdLength = 32;
constexpr uint8_t ConfigMqttDiscoveryPrefixLength = 32;
constexpr uint16_t ConfigMqttDefaultPort = 1883;
constexpr uint16_t ConfigMqttKeepAliveDefault = 60;

// sensors
constexpr uint8_t ConfigMaxSensors = 8;
constexpr uint8_t ConfigMaxSensorNameLength = 21;
constexpr uint8_t ConfigMaxSensorPins = 4;

constexpr uint32_t SystemHeaderMagic = 0x53464201;  // 'SFB\x01'

// Flags stored in SystemHeader::reserved[0]
constexpr uint8_t OtaFlagAutoApply = 0x01;  // bit0: automatically download and apply updates

constexpr uint8_t ConfigAuthApiKeyLength = 32;
constexpr uint8_t ConfigAuthHmacKeyLength = 32;

struct SystemHeader {
    uint32_t magic;               // offset 0  — must equal SystemHeaderMagic
    uint32_t bootCount;           // offset 4
    uint16_t configWrittenBy;     // offset 8
    uint8_t  headerVersion;       // offset 10 — for future header migrations
    uint8_t  crashCounter;        // offset 11
    uint8_t  lastResetReason;     // offset 12
    uint8_t  pinGuardFlags;       // offset 13 — PinGuardMode bitmask (see PinGuard.h)
    uint8_t  reserved[16];        // offset 14 — reserved[0] = OTA flags (see OtaFlagAutoApply)
    uint16_t checksum;            // offset 30 — always last
} __attribute__((packed));        // = 32 bytes

enum class LocationType : uint8_t
{
    Power = 0x00,                   // Power boat
    Sail = 0x01,                    // Sailing boat
    Fishing = 0x02,                 // Fishing boat
    Yacht = 0x03,                   // Yacht
	Shed = 0x04,                    // Shed
	Basement = 0x05,                // Basement
	Workshop = 0x06,                // Workshop
	Garage = 0x07,                  // Garage
	Bedroom = 0x08,                 // Bedroom
	Office = 0x09,                  // Office
	Other = 0xFF                    // Other/unspecified
};

enum class TriggerType : uint8_t
{
	None      = 0x00,
	TimeOfDay = 0x01,  // triggerPayload[0]=hour, [1]=minute
	Sunrise   = 0x02,  // triggerPayload[0..1]=int16 offset minutes before/after
	Sunset    = 0x03,  // triggerPayload[0..1]=int16 offset minutes before/after
	Interval  = 0x04,  // triggerPayload[0..1]=uint16 interval minutes
	DayOfWeek = 0x05,  // triggerPayload[0]=bitmask (bit0=Mon .. bit6=Sun)
	Date      = 0x06,  // triggerPayload[0]=day, [1]=month
};

enum class ConditionType : uint8_t
{
	None       = 0x00,
	TimeWindow = 0x01,  // conditionPayload[0]=start_hour, [1]=start_min, [2]=end_hour, [3]=end_min
	DayOfWeek  = 0x02,  // conditionPayload[0]=bitmask (bit0=Mon .. bit6=Sun)
	IsDark     = 0x03,  // no payload (computed from sunrise/sunset)
	IsDaylight = 0x04,  // no payload (computed from sunrise/sunset)
	RelayIsOn  = 0x05,  // conditionPayload[0]=relay index
	RelayIsOff = 0x06,  // conditionPayload[0]=relay index
};

enum class ExecutionActionType : uint8_t
{
	None         = 0x00,
	RelayOn      = 0x01,  // actionPayload[0]=relay index
	RelayOff     = 0x02,  // actionPayload[0]=relay index
	RelayToggle  = 0x03,  // actionPayload[0]=relay index
	RelayPulse   = 0x04,  // actionPayload[0]=relay index, [1..2]=uint16 duration seconds
	AllRelaysOn  = 0x05,
	AllRelaysOff = 0x06,
	SetPinHigh = 0x07,  // actionPayload[0]=pin number
	SetPinLow = 0x08,  // actionPayload[0]=pin number
};

enum class RelayActionType : uint8_t
{
	Default    = 0x00,
	Horn       = 0x01,  // Replaces SoundConfig::hornRelayIndex
	NightRelay = 0x02,  // Replaces LightSensorConfig::nightRelayIndex
};


// Keep struct packed and stable. Increase 'VERSION' when you change layout.
// Packed POD for persistent configuration.
constexpr uint8_t ConfigVersion1 = 1;
constexpr uint8_t ConfigVersion2 = 2;
constexpr uint8_t ConfigVersion3 = 3;
constexpr uint8_t ConfigVersion4 = 4;
constexpr uint8_t ConfigVersion5 = 5;
constexpr uint8_t ConfigVersion6 = 6;
constexpr uint8_t ConfigVersion = ConfigVersion6;
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

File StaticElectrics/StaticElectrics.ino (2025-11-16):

#include <Arduino.h>
#include <stdint.h>
#include <UnoWiFiDevEd.h>
#include <Adafruit_Sensor.h>
#include <dht11.h>
#include <SerialCommandManager.h>

#include "StaticElectricConstants.h"
#include "Config.h"
#include "ConfigManager.h"
#include "ConfigCommandHandler.h"
#include "Queue.h"
#include "SoundManager.h"

#include "SystemCommandHandler.h"
#include "AckCommandHandler.h"
#include "SoundCommandHandler.h"
#include "RelayCommandHandler.h"
#include "BaseCommandHandler.h"


#define COMPUTER_SERIAL Serial
#define LINK_SERIAL Serial1

constexpr int DefaultDelay = 5;

constexpr uint8_t WaterSensorPin = A0;
constexpr uint8_t WaterSensorActivePin = D8;

constexpr unsigned long SensorCheckIntervalMs = 5000;

constexpr unsigned long serialInitTimeoutMs = 300;
constexpr unsigned long serialReconnectMs = 10000;

constexpr uint8_t TempSensorPin = D9;

// forward declares
void InitializeSerial(HardwareSerial& serialPort, unsigned long baudRate, bool waitForConnection = false);
void onComputerCommandReceived(SerialCommandManager* mgr);
void onLinkCommandReceived(SerialCommandManager* mgr);

SerialCommandManager commandMgrComputer(&COMPUTER_SERIAL, onComputerCommandReceived, '\n', ':', '=', 500, 64);
SerialCommandManager commandMgrLink(&LINK_SERIAL, onLinkCommandReceived, '\n', ':', '=', 500, 64);

SoundManager soundManager;

SystemCommandHandler systemHandler(&commandMgrComputer);
AckCommandHandler ackHandler(&commandMgrComputer);
RelayCommandHandler relayHandler(&commandMgrComputer, &commandMgrLink, Relays, TotalRelays);
SoundCommandHandler soundHandler(&commandMgrComputer, &commandMgrLink, &soundManager);
ConfigCommandHandler configHandler(&soundManager);

unsigned long nextWaterSensorCheck = 5000;
Queue waterPumpQueue(15);

dht11 dht11Sensor;

unsigned long nextWeatherSensorCheck = 2500;
unsigned long lastSerialConnectAttempt = 0;


void setup()
{
	ISerialCommandHandler* linkHandlers[] = { &relayHandler, &soundHandler, &configHandler, &ackHandler, &systemHandler } ;
	size_t linkHandlerCount = sizeof(linkHandlers) / sizeof(linkHandlers[0]);
	commandMgrLink.registerHandlers(linkHandlers, linkHandlerCount);

	ISerialCommandHandler* computerHandlers[] = { &relayHandler, &soundHandler, &configHandler, &ackHandler, &systemHandler };
	size_t computerHandlerCount = sizeof(computerHandlers) / sizeof(computerHandlers[0]);
	commandMgrComputer.registerHandlers(computerHandlers, computerHandlerCount);

	InitializeSerial(COMPUTER_SERIAL, 115200, true);
	InitializeSerial(LINK_SERIAL, 9600, true);

	soundManager.configUpdated(ConfigManager::getConfigPtr());

	// water sensor
	pinMode(WaterSensorActivePin, OUTPUT);
	digitalWrite(WaterSensorActivePin, LOW);
	relayHandler.setup();

	commandMgrComputer.sendCommand(SystemInitializedCommand, "");
}

void loop() 
{
	unsigned long now = millis();
	commandMgrComputer.readCommands();
	commandMgrLink.readCommands();
	soundManager.update();

	getWaterSensorValue(now);
	readDHT11Sensor(now);

	delay(DefaultDelay);
}

void getWaterSensorValue(unsigned long currTime)
{
	if (currTime > nextWaterSensorCheck)
	{
		if (waterPumpQueue.isFull())
		  waterPumpQueue.dequeue();

		digitalWrite(WaterSensorActivePin, HIGH);

		delay(10);
		int sensorValue = analogRead(WaterSensorPin);
		waterPumpQueue.enqueue(sensorValue);

		digitalWrite(WaterSensorActivePin, LOW);

		nextWaterSensorCheck = currTime + SensorCheckIntervalMs;
		commandMgrLink.sendCommand(SensorWaterLevel, String(waterPumpQueue.average()));

		commandMgrComputer.sendDebug(String(sensorValue), F("WTRLVL"));
		commandMgrComputer.sendDebug(String(waterPumpQueue.average()), F("WTRAVG"));
	}
}

void readDHT11Sensor(unsigned long currTime)
{
	if (currTime > nextWeatherSensorCheck)
	{
		dht11Sensor.read(TempSensorPin);
		commandMgrComputer.sendDebug(String(dht11Sensor.humidity, 1), F("Humidity"));
		commandMgrComputer.sendDebug(String(dht11Sensor.temperature, 1), F("Temperature"));
		float humidity = dht11Sensor.humidity;
		float tempCelsius = dht11Sensor.temperature;

		nextWeatherSensorCheck = currTime + SensorCheckIntervalMs;

		commandMgrLink.sendCommand(SensorTemperature, String(tempCelsius, 1));
		commandMgrLink.sendCommand(SensorHumidity, String(humidity, 0));
	}
}

void onComputerCommandReceived(SerialCommandManager* mgr)
{
	commandMgrComputer.sendError(mgr->getRawMessage(), F("STATCMD"));
}

void onLinkCommandReceived(SerialCommandManager* mgr)
{
	commandMgrComputer.sendError(mgr->getRawMessage(), F("STATLNK"));
}

void InitializeSerial(HardwareSerial& serialPort, unsigned long baudRate, bool waitForConnection)
{
	serialPort.begin(baudRate);

	if (waitForConnection)
	{
		unsigned long leave = millis() + SerialInitTimeoutMs;

		while (!serialPort && millis() < leave)
			delay(10);

		if (serialPort)
			delay(100);
	}
}

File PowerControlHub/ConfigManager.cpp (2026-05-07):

/*
 * PowerControlHub
 * Copyright (C) 2025 Simon Carter (s1cart3r@gmail.com)
 *
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
 * You should have received a copy of the GNU General Public License
 * along with this program. If not, see <https://www.gnu.org/licenses/>.
 */
#include <EEPROM.h>

#include "Local.h"
#include "ConfigManager.h"
#include "SystemFunctions.h"

#include "ToneManager.h"

const char DefaultBoatName[] PROGMEM = "My Boat";
constexpr char RelayNameShort[] PROGMEM = "R %u";
constexpr char RelayNameLong[] PROGMEM = "Relay %u";
// Static storage (use the shared Config from Config.h)
Config ConfigManager::_cfg;
SystemHeader ConfigManager::_hdr;

void ConfigManager::begin()
{
	// On ESP platforms, EEPROM needs begin(size)
#if defined(ESP8266) || defined(ESP32)
	size_t requiredBytes = sizeof(SystemHeader) + sizeof(Config);
	EEPROM.begin(requiredBytes);
#endif
}

uint16_t ConfigManager::calcChecksum(const Config& c)
{
	// simple 16-bit sum over bytes excluding checksum field
	const uint8_t* p = reinterpret_cast<const uint8_t*>(&c);
	size_t bytes = sizeof(Config) - sizeof(c.checksum);
	uint32_t sum = 0;
	for (size_t i = 0; i < bytes; ++i) sum += p[i];
	return static_cast<uint16_t>(sum & 0xFFFF);
}

bool ConfigManager::load()
{
	// Ensure EEPROM is initialised for boards that require it
	begin();

	loadHeader();

	// Read raw bytes
	EEPROM.get(sizeof(SystemHeader), _cfg);

	// Step up through every known version in sequence.
	// Each migration bumps _cfg.version by one, so a device that has missed
	// multiple releases will chain through all intermediate steps automatically.
	bool migrated = false;
	while (_cfg.version < ConfigVersion)
	{
		if (_cfg.version == ConfigVersion1)
		{
			migrateV1toV2();
			migrated = true;
		}
		else if (_cfg.version == ConfigVersion2)
		{
			migrateV2toV3();
			migrated = true;
		}
		else if (_cfg.version == ConfigVersion3)
		{
			migrateV3toV4();
			migrated = true;
		}
		else if (_cfg.version == ConfigVersion4)
		{
			migrateV4toV5();
			migrated = true;
		}
		else if (_cfg.version == ConfigVersion5)
		{
			migrateV5toV6();
			migrated = true;
		}
		else
		{
			// Version is below the oldest known migration (e.g. 0x00 on some blank boards).
			// Cannot migrate safely — reset and persist clean defaults.
			resetToDefaults();
			save();
			return false;
		}
	}

	// Version is above ConfigVersion (future firmware downgraded, or 0xFF on a fresh board)
	if (_cfg.version != ConfigVersion)
	{
		resetToDefaults();
		save();
		return false;
	}

	// Migration succeeded — persist the upgraded config and skip the checksum check
	// (the old checksum is no longer valid for the new layout).
	if (migrated)
	{
		save();
		return true;
	}

	uint16_t expected = calcChecksum(_cfg);
	if (expected != _cfg.checksum)
	{
		// corrupted: reset to defaults and persist
		resetToDefaults();
		save();
		return false;
	}

	return true;
}

void ConfigManager::migrateV1toV2()
{
	// V1 -> V2: SchedulerSettings was appended immediately before checksum.
	// Every V1 field occupies the same byte position in V2, so no data moves are needed.
	// The first two bytes of scheduler overlap where the V1 checksum was written;
	// the remainder of scheduler extends into EEPROM that V1 never touched.
	// Zero the entire scheduler section so all events start disabled and the
	// reserved bytes are clean before the new checksum is calculated by save().
	memset(&_cfg.scheduler, 0x00, sizeof(_cfg.scheduler));
	_cfg.version = ConfigVersion2;
}

void ConfigManager::migrateV2toV3()
{
	// V2 -> V3: SensorsConfig block appended before the top-level reserved bytes.
	// All existing V2 fields occupy the same byte positions, so no data moves are needed.
	// Zero the new sensors section so all entries start disabled and pins are cleared
	// before the new checksum is calculated by save().
	
	memset(&_cfg.sensors, 0x00, sizeof(_cfg.sensors));

	for (uint8_t i = 0; i < ConfigMaxSensors; ++i)
	{
		memset(_cfg.sensors.sensors[i].pins, PinDisabled, ConfigMaxSensorPins);
	}

	_cfg.version = ConfigVersion3;
}

void ConfigManager::migrateV3toV4()
{
	// V3 -> V4: RelayActionType field added to RelayEntry (consumes 1 reserved byte).
	// Promote hornRelayIndex -> Horn actionType, nightRelayIndex -> NightRelay actionType.
	for (uint8_t i = 0; i < ConfigRelayCount; ++i)
	{
		_cfg.relay.relays[i].actionType = RelayActionType::Default;
	}

	if (_cfg.sound.hornRelayIndex < ConfigRelayCount)
	{
		_cfg.relay.relays[_cfg.sound.hornRelayIndex].actionType = RelayActionType::Horn;
	}

	if (_cfg.lightSensor.nightRelayIndex < ConfigRelayCount)
	{
		_cfg.relay.relays[_cfg.lightSensor.nightRelayIndex].actionType = RelayActionType::NightRelay;
	}

	_cfg.version = ConfigVersion4;
}
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

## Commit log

2025-11-16 Auto name relay for sound commands (#27)
    * Auto name relay for sound commands
    Include BroadcastManager for multi serial comms
    * Update BoatControlPanel/BroadcastManager.cpp
    * Update BoatControlPanel/BoatControlPanel.vcxproj
    * Update BoatControlPanel/ConfigCommandHandler.cpp
    * Update BoatControlPanel/BoatControlPanel.vcxproj.filters
    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
2025-11-16 AckCommandHandler, SystemCommandHandler (#31)
    * AckCommandHandler, SystemCommandHandler, bug fixes
    * updates from code review
    [ConfigCommandHandler.cpp, StaticElectrics.ino]
2025-11-19 Feature/dht11 sensor integration (#35)
    * Integrate Temp/Humidity sensor
    * Integrate Dht11 and improve Warnings to handle sensors better
    * add the missing code to convert
    * Update BoatControlPanel/WarningManager.h
    * Update BoatControlPanel/WarningManager.h
    * Update BoatControlPanel/WarningManager.cpp
    * Update StaticElectrics/StaticElectricConsta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
2025-11-21 Last of the shared components, plus free memory for arduino
2025-11-22 Finalise shared code between projects (#44)
    * Finalise shared code between projects
    ---------
    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
2025-11-25 Fix all global variable names for smoother display (#47)
    [NextionIds.h]
2025-11-28 Fix minor bugs and ensure horn relay index is updated straight away (#50)
    [Config.h, ConfigCommandHandler.cpp]
2025-12-03 Warning network handler (#69)
    prevent auto reconnect when RSSI is low
    [SharedConstants.h]
2025-12-07 Feature/ap ip address (#76)
    * Bit of code tidy
    * Allow configurable IP Address when in AP mode
    * Update SmartFuseBox/WifiController.h
    * Update Shared/Config.h
    * Update SmartFuseBox/WifiServer.cpp
    * Update Shared/SharedConstants.h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
2025-12-14 Refactor/convert from arduino string (#85)
    * Initial conversion BoatControlPanel compiles
    * Convert string from DateTimeManager to char*
    * Update WifiServer to use char*
    * Update SystemFunctions
    * Make buffer length constant
    * Convert relay command handler
    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
2025-12-23 Feature/linked relays (#90)
    * Linked Relays
    * Introduce MessageBus
2026-01-17 Feature/gps course and minor tweaks (#94)
    * Update to include GPS course
    * Add course direction
    * Sensor Controller
    * Minor updates and code tidy
    * sensor command handler update
    * Fix speed sensor handling
    * Blinking issue with loss of link and using last values
    * Add moon Phases
    Show distance/speed in km/kn
    integrate gps module properly
    [BoatControlPanel.ino, NextionIds.h]
2026-01-18 Fix distress screen with active data (#95)
    Some memory savings due to running out on mega 2560
    Reset serial if unknown commands coming through
    Remove TLV Compass Handler
    Introduce phonetic conversions of strings
    Include all Vhf pages
    Minor bug fixes
    [BoatControlPanel.ino, Config.h, ConfigCommandHandler.cpp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]
2026-01-29 Attempt to sync config from control panel to fusebox (#102)
2026-02-06 Feature/boat sensor housing (#103)
    * Partial Complete
    * update dtostrf implementations
    * Minor updates including docs and 3mf for boat sensor housing
    * Re add missing files
    * Update invalid references
    * Update missing config elements
    * refix ConfigCommandHandler
    * refix ConfigCommandHandler
    * refix ConfigCommandHandler
    * Fix handler for led colors
    * Tone manager for control panel
    * Share tonemanager
    * Share tonemanager
    * ToneManager finished and integrated
    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
    [Aviation Connector Covers.3mf, Boat Sensor Housing.3mf]
2026-02-08 Feature/sd card reader (#107)
    This PR introduces SD-card support to SmartFuseBox: periodic sensor snapshot logging to CSV, plus an SD-based configuration loader/exporter (C29/C30) and related system/status plumbing (warnings, system commands, JSON status).
    Changes:
    Add SdCardLogger for non-blocking SD logging with warning integration (missing/error).
    Add SdCardConfigLoader to load config.txt from SD at boot and support C29 (reload) / C30 (export).
    Extend warning propagation and system/status endpoints to expose SD state and include warning masks in heartbeats.
    [BoatControlPanel.ino, ConfigCommandHandler.cpp]
2026-02-12 Integrate DS1302 RTC (#109)
    * Integrate DS1302 RTC
    * prevent spamming
    * Time sync
    [Boat Sensor Housing.3mf]
2026-02-23 Feature/extract startup code (#118)
    * Pre update changes
    * Convert to app to make more easily configurable by consumers
    * Fix issue with relay controller
    [Config.h]
2026-02-26 Features/minor tweaks (#119)
    Integrate Remote Sensors
    Uptime in system sensor handler
    F11 command to show uptime
2026-03-04 Feature/wifi seperation and docs (#120)
    Refactors the SmartFuseBox connectivity layer to be board-independent by introducing WiFi/Bluetooth abstraction interfaces
2026-03-09 Fix/validation checks (#125)
    * Code tidy and remove magic numbers
    * Validation checks and warning removal
    [BoatControlPanel.ino, ConfigCommandHandler.cpp, ConfigNetworkHandler.cpp]
2026-03-11 Prep for KiCad, add Esp32.md and images
    Update .gitattributes to make life easier so as not to accidentally override .ino and Local.h
    [Comms_Monitoring.kicad_sch, ESP32_Module.kicad_sch, Power.kicad_sch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]
2026-03-12 Git/enhancements and docs (#128)
    * Prep for KiCad, add Esp32.md and images
    * Introduce BoardConfig.h to split Board capabilities away from Local.h
    Update documentation
    * Update README.md
    * Update Docs/Forking.md
    * Update Docs/Forking.md
    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
2026-03-14 Enhance debug for LightSensor and specify analog/digital pin in use, update docs, fix issue with enabling MQTT (#136)
    [Config.h]
2026-03-20 Re-factor Config and Settings (#140)
    * Re-factor Config and Settings
    Fix inversion bug in LightSensorHandler
    * Apply suggestions from code review
    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
    [BoardConfig.h, BoatControlPanel.ino, Config.h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]
2026-03-20 Configure DHT22 sensors x 4 (#141)
2026-03-25 Expand Config for future use and update BoatSensorHousing 3mf file (#147)
    * Expand Config for future use and update BoatSensorHousing 3mf file
    * Updates from code review
    [Boat Sensor Housing.3mf]
2026-04-01 Implement matrix strategy for ESP32 firmware builds
    Added matrix strategy for building firmware for multiple ESP32 boards and updated paths for generated files.
2026-04-02 Refactor FirmwareVersion.h generation script
    Updated the script to generate FirmwareVersion.h using printf for better formatting.
2026-04-04 Implement binary presence sensor (#165)
    * Implement binary presence sensor
    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
2026-04-05 Wifi Command Bridge (#168)
    * Wifi Command Bridge
    * Updates from code review and default to 8 connections for esp32, can be changed locally by consumers if required
    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
2026-04-06 Ensure correct and consistent use of millis64() (#170)
    * Ensure correct and consistent use of millis64()
    * Update Docs/ScheduleEvents.md
    * Apply reviewer feedback: fix time source mixing, typos, doc comments, vcxproj filters, and strtoull
    Agent-Logs-Url: https://github.com/SmartFuseBox/SmartFuseBox/sessions/9cc3b3e7-916a-4845-b9af-fabadb1c3d42
    ---------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
2026-04-11 Minor updates and fixes (#172)
    * Minor updates and fixes
    * Minor updates and fixes
    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
    [Config.h, ConfigCommandHandler.cpp, ConfigController.cpp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]
2026-05-07 Ping Guard and Voltage Sensor (#188)
    * Ping Guard and Voltage Sensor
2026-05-10 Json safe float/power control hub app start (#192)
    * Json Safe float values
    * Start of PowerControlHubApp early work in progress
    * Re-add VoltageSensorHandler
    * after initial compile
2026-05-22 Minor fixes and updates, ensure pins are better guarded (#194)
    [BoardConfig.h, PinGuard.h, PowerControlHub.ino]
2026-06-14 Update esp32 wifi handling with chunked client, implement more features within control panel (#196)
2026-07-01 Feature/dashboard (#197)
    * Update PinGuard to include JTAG and SPRAM pins
    * Update color handling and allow updating of relays over wifi
    * Local sensor configuration
2026-07-17 Fix issue with stack overflow on esp32 (#199)
    dashboard updates
    fix issue sensor network handlers not returning correct information on success
    [PowerControlHub.ino, SensorConfigNetworkHandler.cpp]
2026-07-18 Extend pinGuard validation to prevent duplicate pin use (#214)
    [PinGuard.h]
2026-07-18 Extra pin validation (#216)
    Show pins in use
2026-07-24 Consolidate interface (#218)
    Show warning set on ESP device
2026-07-25 Update device date/time from app (#219)
2026-07-26 Feature/settings sub page start (#220)
    * Show not connected banner on all pages when no device is available
    * Initial page time allowing to update device time and time zone
2026-07-26 Configure MQTT from app and add new device mqtt network handler (#221)
    * Configure MQTT from app and add new device mqtt network handler
    * fix double declaration
2026-08-02 Expose pin guard protected pins via serial /radio and display in app
2026-08-08 Implement updating xpdz pin from app (#228)

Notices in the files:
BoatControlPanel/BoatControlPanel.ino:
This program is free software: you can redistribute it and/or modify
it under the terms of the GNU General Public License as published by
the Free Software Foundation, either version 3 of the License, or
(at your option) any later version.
